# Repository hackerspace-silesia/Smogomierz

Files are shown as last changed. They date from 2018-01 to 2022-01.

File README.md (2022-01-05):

# Smogly 

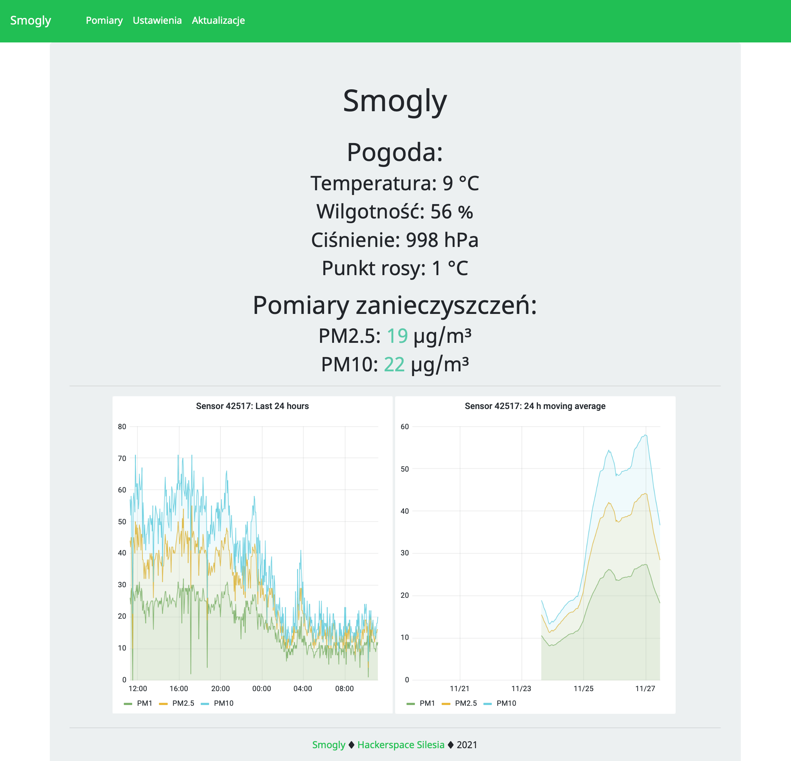
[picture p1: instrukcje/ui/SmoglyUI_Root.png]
Smogly2


Smogly to niekomercyjny projekt łatwego w budowie i taniego miernika zanieczyszczeń powietrza. Projekt jest w pełni otwarty i łatwy w modyfikowaniu. 

Smogly nie wysyła Twoich danych do żadnego serwisu, jeśli nie wyrazisz na to zgody. Dane pomiarowe z Twojego miernika należą do Ciebie i to od Ciebie zależy co z nimi zrobisz i komu je udostępnisz. Jeśli tylko Ty chcesz mieć dostęp do swoich danych, to masz do tego prawo. Jeśli jednak chcesz się nimi podzielić, to w karcie Konfiguracji panelu Smogomierza masz możliwość wyboru kilku serwisów, do których możesz wysłać dane. Wśród nich znajdziesz między innymi serwis [Sensor.Community](https://maps.sensor.community/#7/52.000/19.000), [aqi.eco](https://aqi.eco/), [ThingSpeak](https://thingspeak.com), [AirMonitor](http://mapa.airmonitor.pl)(ESP32), czy bazę danych [InfluxDB](https://www.influxdata.com/time-series-platform/influxdb/). Smogomierz posiada również [wtyczkę Homebridge](https://github.com/bfaliszek/homebridge-smogomierz).

Smogly po pierwszym uruchomieniu tworzy własną sieć WiFi o nazwie "Smogly-deviceName"(np. "Smogly-328017"). Po podłączeniu się z nią, będziesz miał możliwość skonfigurowania połączenia WiFi z własną siecią domową. Z listy dostępnych sieci wybierz swoją własną i podaj do niej hasło. Smogly zapisze dane w swojej pamięci wewnętrznej i ponownie się uruchomienie. Dalszą konfigurację wykonasz już przez przeglądarkę internetową wchodząc pod adres Smogly-deviceName.local lub IP_Smogly(do sprawdzenia na routerze). 

Stworzyliśmy również aplikację dla systemów Windows, macOS oraz Linux), która umożliwia w łatwy sposób wgranie oprogramowania oraz znajdowanie adresu IP Twojego miernika! Możesz ją pobrać ze strony [github.com/hackerspace-silesia/Smogomierz-Flashing-Tool](https://github.com/hackerspace-silesia/Smogomierz-Flashing-Tool/releases).

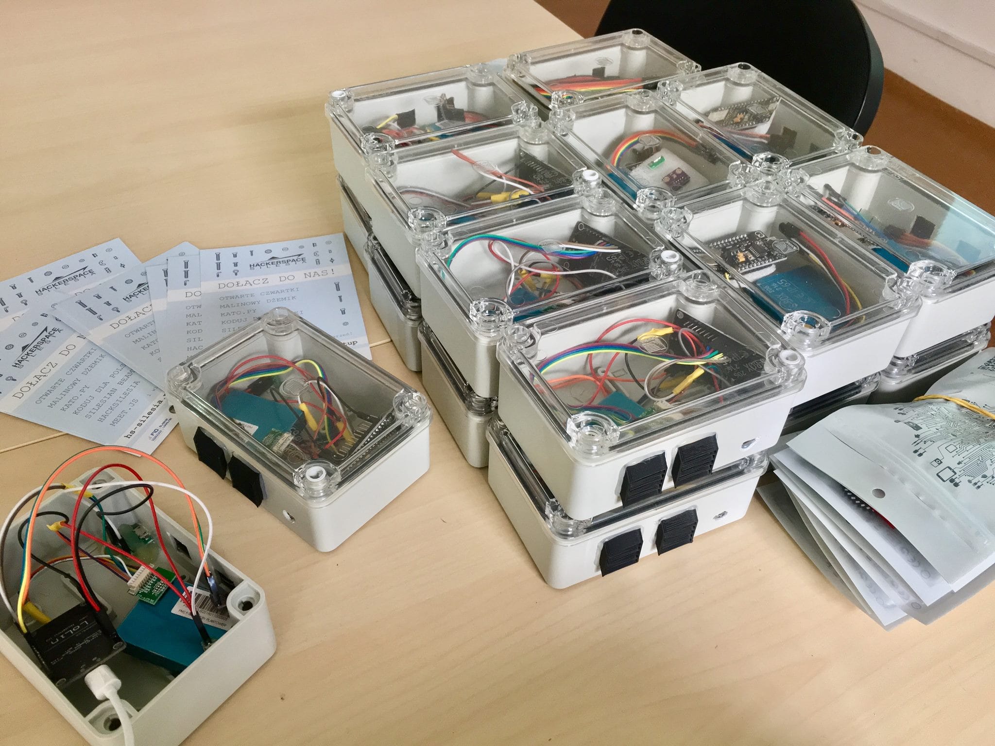
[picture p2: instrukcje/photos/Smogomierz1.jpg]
Smogly1


## Darowizny

Projekt Smogly jest rozwijany od 2017 roku. Wszystko w ramach projektu Smogly robione jest za darmo, w ramach wolontariatu. Jeśli chcesz wesprzeć rozwój projektu, to możesz przekazać darowiznę na Stowarzyszenie Hackerspace Silesia. Najprościej można to zrobić przez specjalny formularz znajdujący się na stronie: [hs-silesia.pl/smogomierz](https://hs-silesia.pl/smogomierz/).



## Instrukcje

1. [Instrukcja zlutowania wymaganych elementów](https://github.com/hackerspace-silesia/Smogomierz/blob/master/instrukcje/soldering.md)

2. [Instrukcja przygotowania obudowy oraz podłączenia elektroniki](https://github.com/hackerspace-silesia/Smogomierz/blob/master/instrukcje/hardware.md)

3. [Instrukcja instalacji/aktualizacji oprogramowania z pliku .bin](https://github.com/hackerspace-silesia/Smogomierz/blob/master/instrukcje/software-bin.md)

4. [Konfiguracja i ustawienia obsługi zewnętrznych serwisów(Sensor.Community, InfluxDB itd.)](https://github.com/hackerspace-silesia/Smogomierz/blob/master/instrukcje/software-additionals.md)

## Parts / Potrzebne części

Do zbudowania własnego Smogly wymagana jest lutownica(wraz z cyną) oraz pistolet do kleju na gorąco, wiertarka, nóż do tapet i śrubokręt do skręcenia obudowy oraz części z poniższej listy.

[Lista potrzebnych części](https://github.com/hackerspace-silesia/Smogomierz/blob/master/instrukcje/components.md)

Gotowe zestawy części potrzebnych do zbudowania własnego Smogly, dostępne są również w sklepie Botland: [Zestaw DIY do budowy miernika smogu](https://botland.com.pl/pl/czujniki-czystosci-powietrza/13434-zestaw-diy-do-budowy-miernika-smogu-czujnik-czystosci-powietrza-pm25-i-pm10.html)

## Smogly PCB

Jeśli ktoś nie lubi podpinać wszystkiego kabelkami, może skorzystać z gotowych projektów płytek PCB. Pozwalają one na połączenie wszystkich elementów. Dostępne są wersja dla [ESP8266](https://github.com/bfaliszek/Smogly-PCB) oraz [ESP32](https://github.com/bfaliszek/Smogly-PCB/tree/esp32). Projekt taki(.zip z plikami gerber [ESP8266](https://github.com/bfaliszek/Smogly-PCB/tree/esp8266/gerber/zip)/[ESP32](https://github.com/bfaliszek/Smogly-PCB/tree/esp32/gerber/zip)) wysyłamy do producenta PCB(np. [JLCPCB](https://jlcpcb.com)) i po kilkunastu dniach otrzymujemy gotowe PCB, do którego przylutowujemy piny lub poszczególne elemeny Smogly.

## Zaawansowane

[Instrukcja instalacji oprogramowania wymaganego do kompilacji oprogramowania z repozytorium](https://github.com/hackerspace-silesia/Smogomierz/blob/master/instrukcje/software.md)

## Roadmap

Lista z głównymi zmianami planowanymi w kolejnych wersjach oprogramowania znajduje się [TUTAJ](https://docs.google.com/spreadsheets/d/1rpeKPuAakPwytqsNge7glb-UtNLumsx8-7kQvhxXOng/edit?usp=sharing). Poza wymienionymi w linkowanym arkuszu funkcjami, przy każdej aktualizacji staram się uaktualnić wsyzstkie wykorzystywane biblioteki i eliminować znalezione błędy.

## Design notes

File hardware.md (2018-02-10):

# Smogomierz - podłączenie elektroniki

Poniższy opis krok po kroku, przeprowadzi Was przez procedurę podłączenia wszystkich czujników obsługiwanych przez nasz miernik smogu. Listę części, wraz z linkami do przykładowych sklepów, gdzie można je kupić znajdziecie pod adresem: https://github.com/hackerspace-silesia/Smogomierz/blob/Arduino/components.md

Całościowy schemat podłączenia:

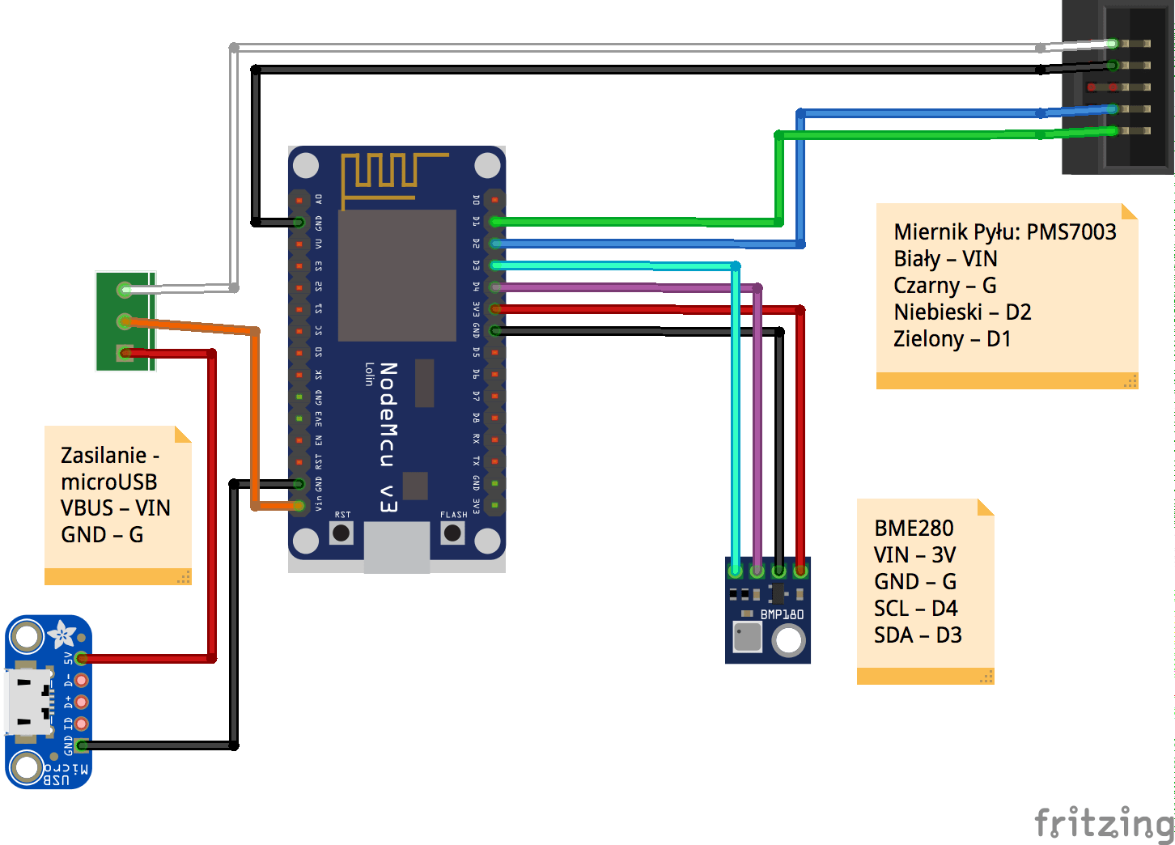
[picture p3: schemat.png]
Schemat


## ESP8266 - NodeMCU V3

Główny element miernika. To właśnie na tę płytkę wgrywamy oprogramowanie. Ma ona wbudowany moduł WiFi, który pozwala na tworzenie sieci bezprzewodowej i wysyłanie danych z pozostałych czujników.

OPIS ESP8266

## BME280 - miernik temperatury, wilgotności i ciśnienia powietrza

BME280 to niewielki moduł pozwalający na bardzo precyzyjne pomiary temperatury powietrza, ciśnienia oraz wilgotności powietrza. 

BME280 można podłączyć na dwa sposoby. W naszym przypadku skorzystamy z I2C. Oznacza to, że poza zasilaniem, będziemy musili jeszcze podłączyć dwa piny: SCL oraz SDA. 

BME280 zasilamy z pinu 3V na ESP8266. Podpinamy go do VIN na BME280. GND łączymy z dowolnym G na ESP8266. SCL podpinamy do pinu D4, SDA do D3 na ESP8266.

SCHEMAT PODŁĄCZENIA BME280

## PMS7003 - laserowy miernik pyłu

Plantower PMS7003 to laserowy miernik pyłu zawieszonego w powietrzu, który podane pomiary PM1, PM2.5 oraz PM10. Posiada wbudowany wiatraczek. Urządzenia zasilane jest 5V i wyniki podaje poprzez UART. W naszym projekcie korzystamy z dwóch pinów RX oraz TX. Pozostałe dostępne w mierniku PMS7003 nie są wykorzystywane.

PMS7003 zasilamy bezpośrednio z pinu 5V wyprowadzonego z portu microUSB w obudowie urządzenia. Piny GND podpinamy do dowolnego pinu G na płytce ESP8266. Pin TX(Pin 9 w PMS7003; zielony kabelek) podpinamy do pinu D1 na płytce ESP8266. Pin RX(Pin 7 w PMS7003; niebieski kabelek) podpinamy do pinu D2 na ESP8266.

SCHEMAT PODŁĄCZENIA PMS7003

## Zasilanie

Miernik smogu zasilany jest poprzez kable microUSB. Układ z wtyczką microUSB umieściliśmy w jednej z gumowych zatyczek w obudowie. Przykleiliśmy go na stałe klejem na gorąco. Z układu wychodzą dwa piny: 5V oraz GND. Służą do zasilania urządzenia.

Wszystkie elementy urządzenia zasilamy poprzez 5V. Źródłem jest pin 5V wyprowadzony z portu microUSB w obudowie urządzenia. 5V musimy doprowadzić do pinu VIN w ESP8266 i 5V w PMS7003(biały kabelek). W tym celu rozdzielamy zasilanie z jednego pinu, na dwa. BME2866 zasilamy z pinu 3V na płytce ESP8266.

Podobnie robimy z GND. Jednak w tym wypadku nie musimy ręcznie rozdzielać masy. Wystarczy ją podłączyć do pinu G na ESP8266. GND z miernika PMS7003(czarny kabelek) podpinamy do G na ESP8266. GND z BME280 również łączymy z G na płytce ESP8266.

SCHEMAT ZASILANIA

## Obudowa

Obudowę miernika smogu stanowi puszka natynkowa IP55. Daje ona dobre zabezpieczenie przeciwko niekorzystnym warunkom atmosferycznym. Puszka ma wymiary 86x86mm i posiada 6 gumowych zatyczek. W miejsce dwóch z nich wkleiliśmy klejem na gorąco elementy wydrukowane na drukarce 3D. Pozwalają one na lepszy przepływ powietrza w obudowie. Można dodać do obudowy niewielki wiatraczek zasilany przez 5V.

ZDJĘCIA OBUDOWY

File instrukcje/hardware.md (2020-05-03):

# Smogomierz - podłączenie elektroniki

Poniższy opis krok po kroku, przeprowadzi Cię przez procedurę podłączenia wszystkich czujników obsługiwanych przez nasz miernik smogu. Listę części, wraz z linkami do przykładowych sklepów, gdzie można je kupić znajdziesz pod adresem: https://github.com/hackerspace-silesia/Smogomierz/blob/master/instrukcje/components.md

Jeśli masz już wszystkie części, to pamiętaj, że kilka z nich wymaga przylutowania pinów. Opis wszystkiego co trzeba zlutować wraz ze zdjęciami znajdziesz w instrukcji ["Lutowanie"](https://github.com/hackerspace-silesia/Smogomierz/blob/master/instrukcje/soldering.md).

Całościowy schemat podłączenia:

Schemat

## ESP32

Moduł ESP, to główny element miernika. To właśnie na tę płytkę wgrywamy oprogramowanie. Ma ona wbudowany moduł WiFi, który pozwala na tworzenie sieci bezprzewodowej i wysyłanie danych z pozostałych czujników. Wszystkie piny GND na płytce są ze sobą połączone i można z nich korzystać zamiennie. Podobnie z pinami 3V. Jeśli zdecydujemy się na Smogomierz oparty o ESP32(zalecane, ma znacznie więcej pamięci niż ESP8266), to nie musimy już zamawiać ESP8266. 

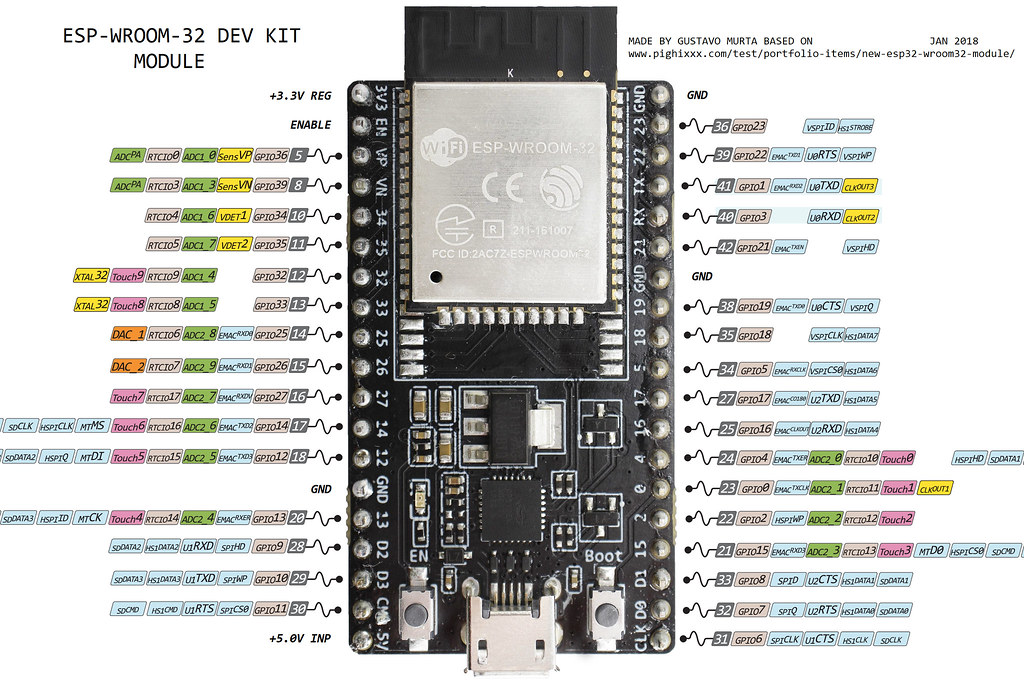
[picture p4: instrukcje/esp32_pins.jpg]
ESP32 Pinour


## ESP8266 - NodeMCU V3

Moduł ESP, to główny element miernika. To właśnie na tę płytkę wgrywamy oprogramowanie. Ma ona wbudowany moduł WiFi, który pozwala na tworzenie sieci bezprzewodowej i wysyłanie danych z pozostałych czujników. Wszystkie piny GND na płytce są ze sobą połączone i można z nich korzystać zamiennie. Podobnie z pinami 3V. Jeśli zdecydujemy się na Smogomierz oparty o ESP8266, to nie musimy już zamawiać ESP32(zalecany jest jednak wybór ESP32, ma znacznie więcej pamięci niż ESP8266). 

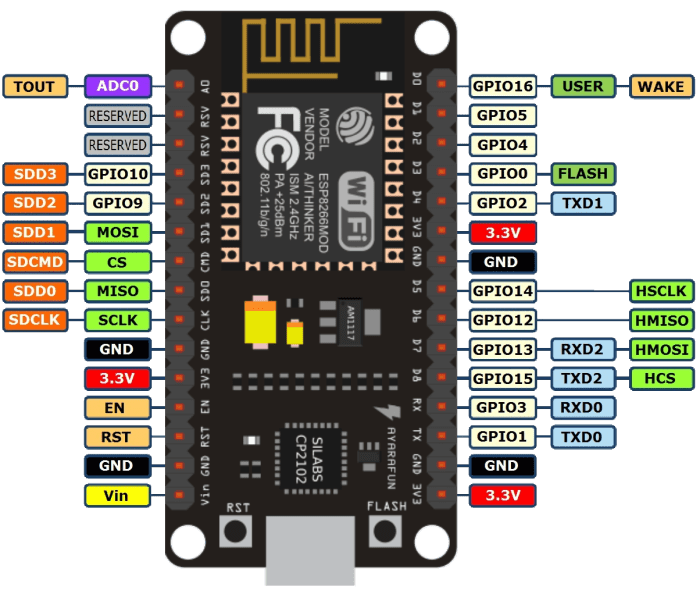
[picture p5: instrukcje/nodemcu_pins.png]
ESP8266 NodeMCU V3 Pinout


## BME280 - miernik temperatury, wilgotności i ciśnienia powietrza

BME280 to niewielki moduł pozwalający na bardzo precyzyjne pomiary temperatury powietrza, ciśnienia oraz wilgotności powietrza. 

BME280 można podłączyć na dwa sposoby. W naszym przypadku skorzystamy z I2C. Oznacza to, że poza zasilaniem, będziemy musieli jeszcze podłączyć dwa piny: SCL oraz SDA. 

BME280 występuje również w wersji **Adafruit**. Charakteryzuje się ona [niebieską płytką](https://www.adafruit.com/product/2652). W przypadku tej wersji BME280 musimy podłączyć SCK tam gdzie pin SCL(do D4) i SDI tam gdzie SDA(do D3) oraz SDO do dowolnego pinu GND na naszym ESP8266.

BME280 zasilamy z pinu 3V na ESP8266. Podpinamy go do VIN na BME280. GND łączymy z dowolnym G(GND) na ESP8266. SCL podpinamy do pinu D4, SDA do D3 na ESP8266.

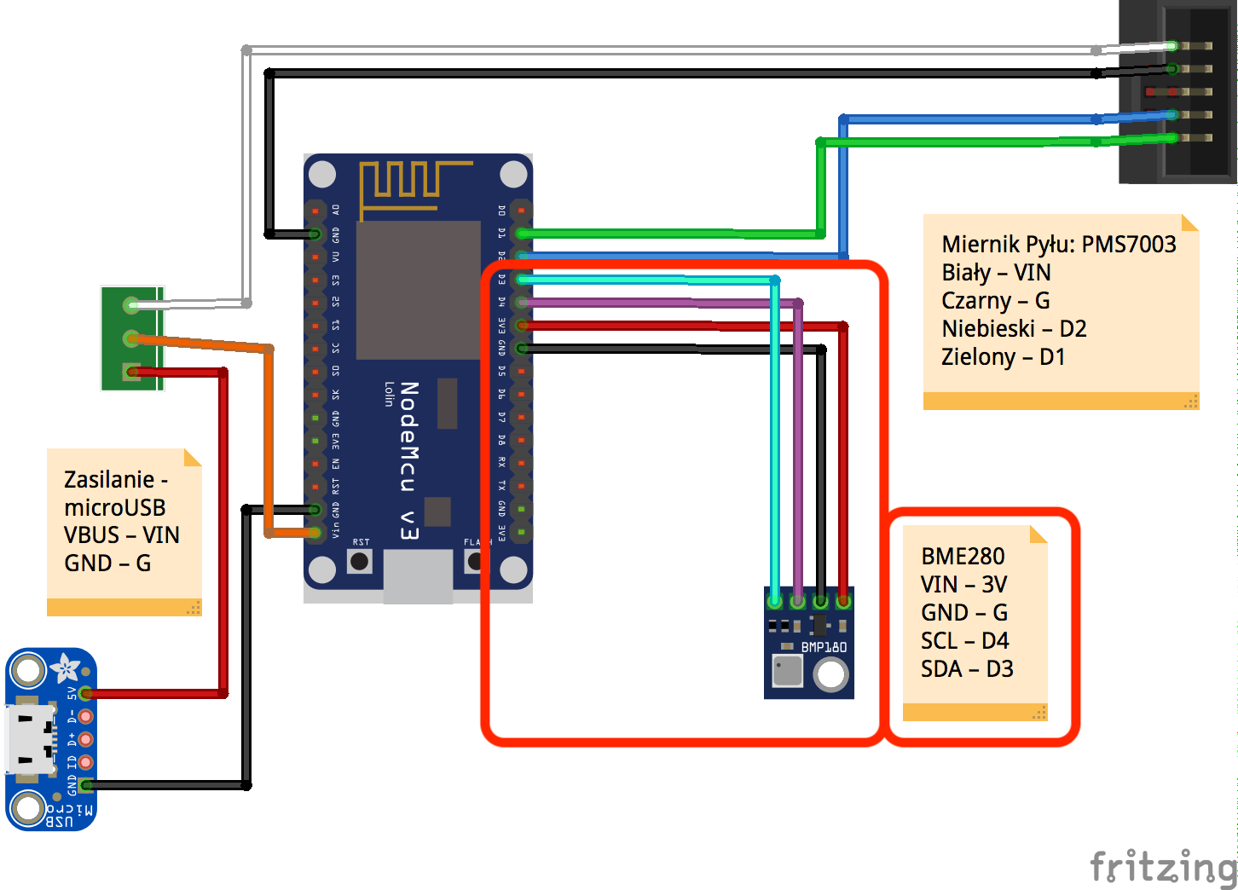
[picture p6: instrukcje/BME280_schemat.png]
BME280 Schemat

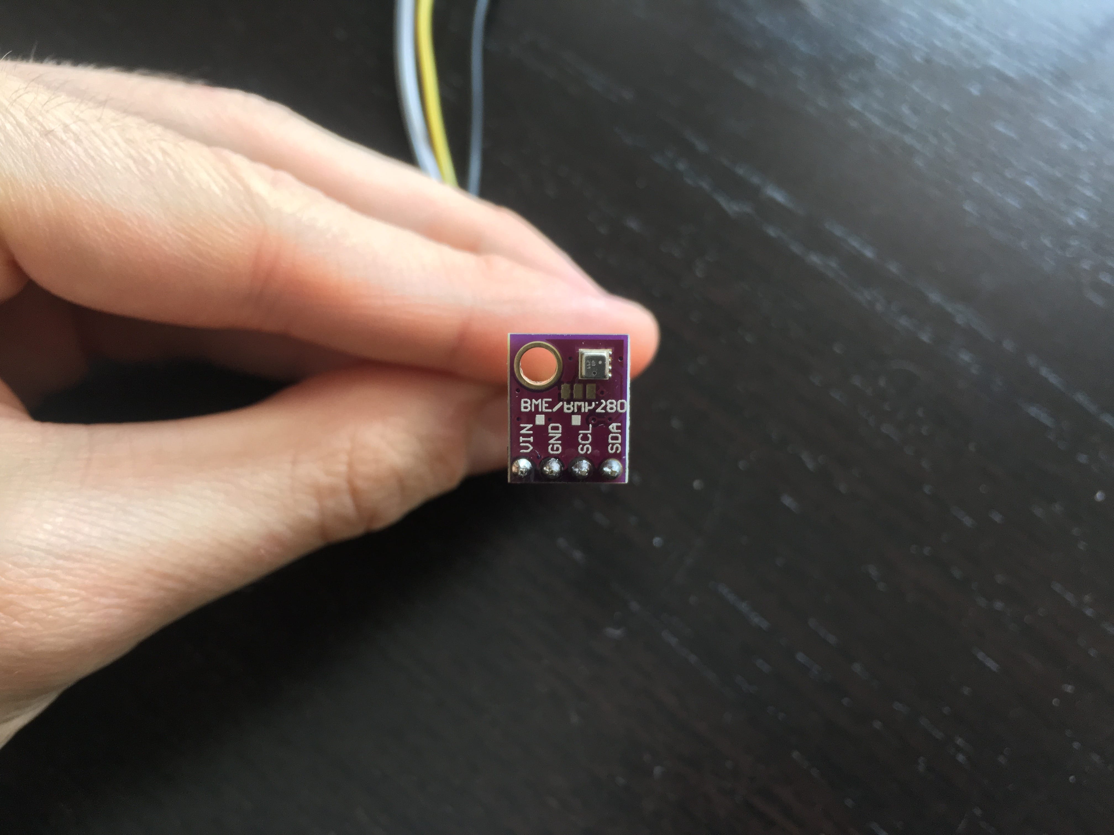
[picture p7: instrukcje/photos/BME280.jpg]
BME280


## SHT1x - miernik temperatury i wilgotności powietrza

SHT1x to niewielki moduł pozwalający na bardzo precyzyjne pomiary temperatury oraz wilgotności powietrza. 

SHT1x zasilamy z pinu 3V na ESP8266. Podpinamy go do VCC na SHT1x. GND łączymy z dowolnym G(GND) na ESP8266. CLOCK/SCL podpinamy do pinu D6, DATA/SDA do D5 na ESP8266. Pomiędzy DATA/SDA a VCC musimy umieścić jeszcze rezystor 10k (pull-up).

## HTU21D - miernik temperatury i wilgotności powietrza

Jeśli zamiast **BME280** chcesz użyć HTU21D. Podłącz go w następujący sposób: 
VIN z HTU21D do pinu 3V na ESP8266. GND łączymy z dowolnym G(GND) na ESP8266. SCL podpinamy do pinu D5, SDA do D6 na ESP8266.

## DHT22/AM2302 - miernik temperatury i wilgotności powietrza

Jeśli zamiast **BME280** chcesz użyć DHT22. Podłącz go w następujący sposób: 
VIN z DHT22/AM2302 do pinu 3V na ESP8266. GND łączymy z dowolnym G(GND) na ESP8266. Pin z danymi pomiarowymi podepnij do D7 na płytce ESP8266.

Kolejność pinów od lewej strony:
- VIN
- DATA
- nieużywany
- GND

## PMS7003 - laserowy miernik pyłu

Plantower PMS7003 to laserowy miernik pyłu zawieszonego w powietrzu, który podane pomiary PM1, PM2.5 oraz PM10. Posiada wbudowany wiatraczek. Urządzenia zasilane jest 5V i wyniki podaje poprzez UART. W naszym projekcie korzystamy z dwóch pinów RX oraz TX do pobierania wyników pomiarów oraz z pinu 5V i GND do zasilania PMS7003. Pozostałe dostępne w mierniku PMS7003 nie będą przez nas wykorzystywane.

PMS7003 zasilamy bezpośrednio z pinu 5V wyprowadzonego z portu microUSB w obudowie urządzenia. Piny GND podpinamy do dowolnego pinu G(GND) na płytce ESP8266. Pin TX(Pin 9 w PMS7003) podpinamy do pinu D1 na płytce ESP8266. Pin RX(Pin 7 w PMS7003) podpinamy do pinu D2 na ESP8266.

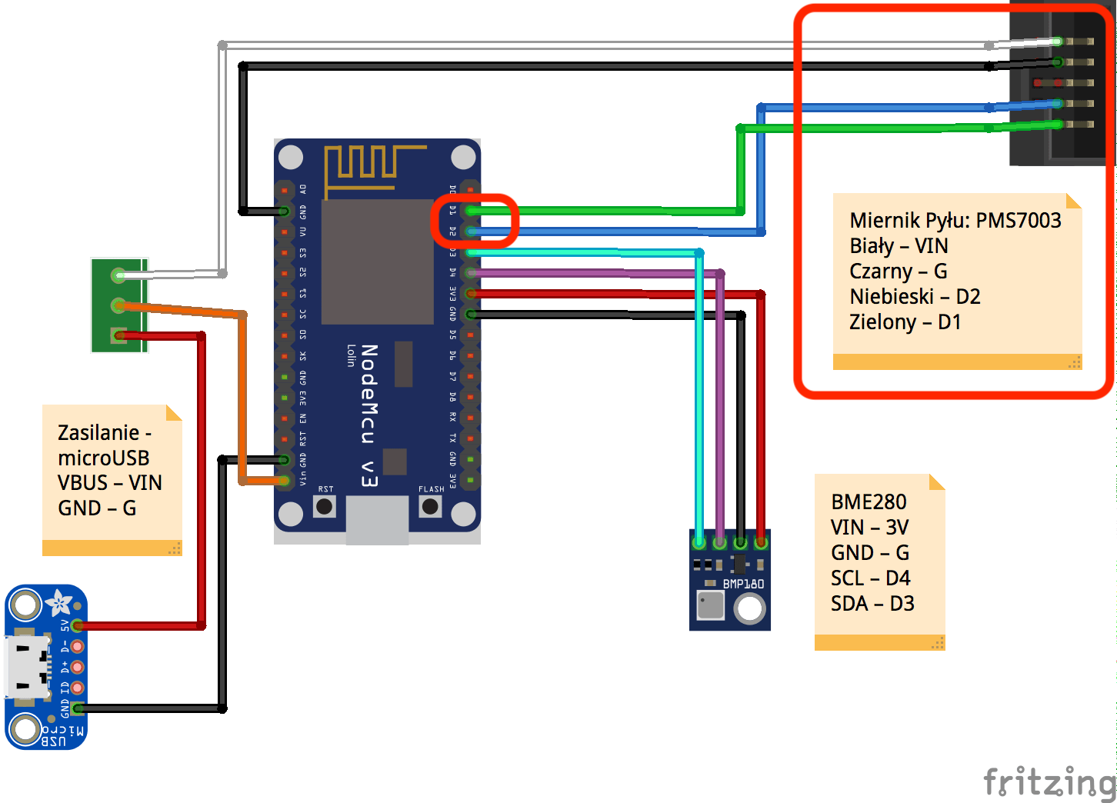
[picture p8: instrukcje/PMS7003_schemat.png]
PMS7003 Schemat


## Sensirion SPS30

Sensirion SPS30 to laserowy miernik pyłu zawieszonego w powietrzu, który podane pomiary PM1, PM2.5, PM4 oraz PM10. Posiada wbudowany wiatraczek. Urządzenia zasilane jest 5V i wyniki podaje poprzez UART. W naszym projekcie korzystamy z dwóch pinów RX oraz TX do pobierania wyników pomiarów oraz z pinu 5V i GND do zasilania SPS30. Pozostałe piny dostępne w mierniku SPS30 nie będą przez nas wykorzystywane. Sensirion SPS30 posiada system automatyczne czyszczenia kurzu osadzającego się wewnątrz miernika oraz żywotność aż 8 lat. Pomiary z Sensirion SPS30 są jednymi z najbardziej dokładnych. Jest on jednak jednym z droższych mierników. Kosztuje w Polsce około 140 zł.

SPS30 zasilamy bezpośrednio z pinu 5V wyprowadzonego z portu microUSB w obudowie urządzenia. Pin GND podpinamy do dowolnego pinu G(GND) na płytce ESP8266. Pin TX podpinamy do pinu D1 na płytce ESP8266. Pin RX podpinamy do pinu D2 na ESP8266. W przypadku użycia ESP8266 pozostały Pin(pin nr. 4) Sensiriona podpinamy do GND. W przypadku ESP32 zostawiamy go niepodłaczonego.

Pełną ([dokumentację](https://www.sensirion.com/en/environmental-sensors/particulate-matter-sensors-pm25/)) możemy znaleźć na stronie producenta Sensiriona SPS30. Warto również pamiętać, że SPS30 posiada dość nietypową wtyczkę: JST ZH 1.5. Wtyczka posiada 5 pinów i raster 1,5mm.

## HPMA115S0

Honeywell HPMA115S0 to laserowy miernik pyłu zawieszonego w powietrzu, który podane pomiary PM1, PM2.5 oraz PM10. Posiada wbudowany wiatraczek. Urządzenia zasilane jest 5V i wyniki podaje poprzez UART. W naszym projekcie korzystamy z dwóch pinów RX oraz TX do pobierania wyników pomiarów oraz z pinu 5V i GND do zasilania HPMA115S0. Pozostałe dostępne w mierniku HPMA115S0 nie będą przez nas wykorzystywane.

## SDS011

SDS011 to laserowy miernik pyłu zawieszonego w powietrzu, który podane pomiary PM2.5 oraz PM10. Posiada wbudowany wiatraczek. Urządzenia zasilane jest 5V i wyniki podaje poprzez UART. W naszym projekcie korzystamy z dwóch pinów RX oraz TX do pobierania wyników pomiarów oraz z pinu 5V i GND do zasilania SDS011. Pozostałe dostępne w mierniku SDS011 nie będą przez nas wykorzystywane.

Pin TXD podłącz do D1 na ESP, natomiast pin RXD do D2.
Zwróć uwagę na sposób montażu ([dokumentacja](http://www.inovafitness.com/en/a/chanpinzhongxin/95.html)) - w zmontowanym urządzeniu wlot powietrza miernika powinien być od góry, lub z lewej strony.

## Obudowa

Na obudowę Smogomierza wybraliśmy puszkę IP67 o wymiarach 118 x 78 x 55 mm. Oferuje ona dobre zabezpieczenie przeciwko niekorzystnym warunkom atmosferycznym. W obudowie Smogomierza istotne są dwie rzeczy. Ochrona przed deszczem oraz swobodny przepływ powietrza. Jeśli chcesz, możesz zastosować jakieś inne rozwiązanie, które spełni te dwa cele.

W przypadku wybranej przez nas obudowy. Musimy wykonać w niej 3 otwory. Dwa większe, które umożliwią przepływ powietrza, oraz jeden mniejszy w celu podłączenia zasilania. Zalecamy wykonanie otworów wentylacyjnych na dłuższym boku obudowy. Otwór na zasilanie możemy umieścić z dowolnej strony. Otwory wentylacyjne najwygodniej wykonać przy użyciu wiertarki i wiertła 10 lub większego. Wykonujemy dwa odwierty obok siebie i następnie wycinany je nożem do tapet w kształt kwadratu. Jeśli chodzi o zasilanie, to wystarczy jeden odwiert wiertłem 10. 

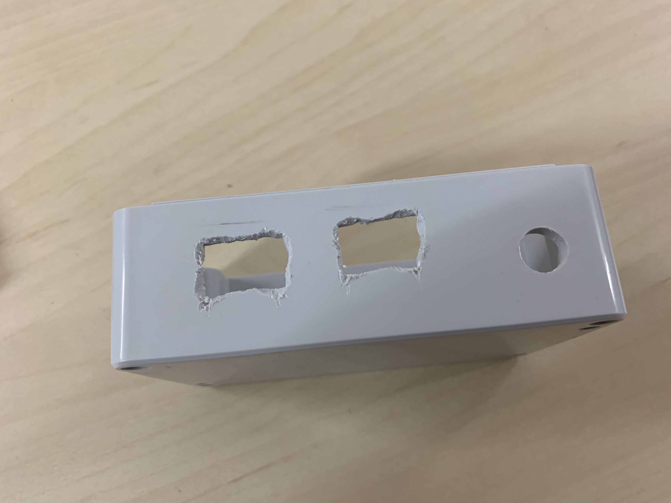
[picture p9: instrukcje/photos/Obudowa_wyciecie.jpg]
Obudowa_wyciecie


Na otwory wentylacyjne wklejamy klejem na gorąco [kratki](https://github.com/hackerspace-silesia/Smogomierz/blob/master/80x80x40mm.stl) wydrukowane na drukarce 3D. Pozwalają one na lepszy przepływ powietrza w obudowie. Natomiast wewnątrz obudowy w miejscu otworu na zasilanie wklejamy wtyczkę microUSB(z wlutowanymi wcześniej pinami).

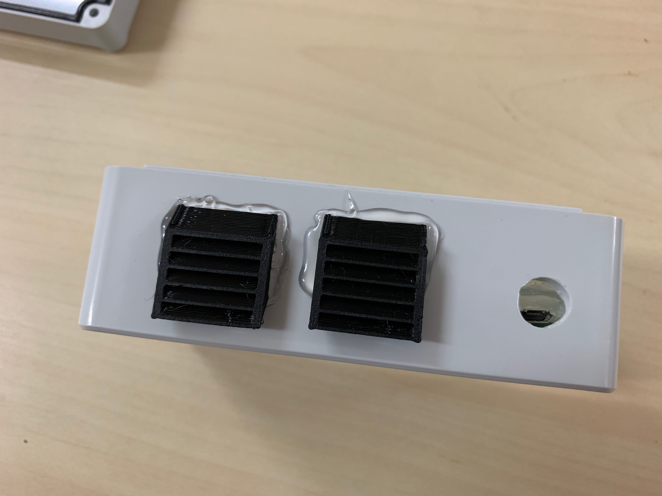
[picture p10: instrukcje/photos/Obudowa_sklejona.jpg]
Obudowa_sklejona

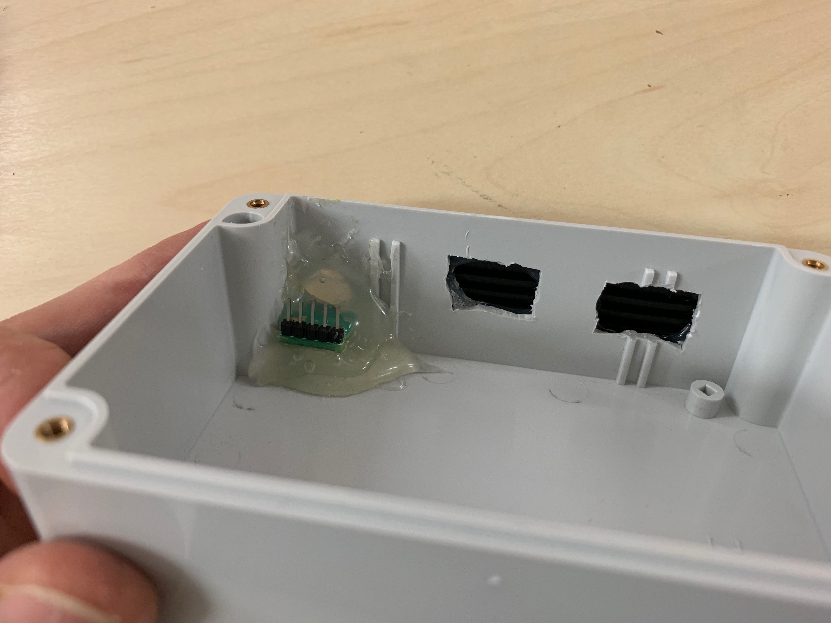
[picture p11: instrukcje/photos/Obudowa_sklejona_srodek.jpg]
Obudowa_sklejona_srodek


## Zasilanie

Miernik smogu zasilany jest poprzez kable microUSB. Układ z wtyczką microUSB wkleiliśmy klejem na gorąco w obudowę. Z układu wychodzą dwa potrzebne nam piny: 5V oraz GND. Służą do zasilania całego Smogomierza.

ESP8266 NodeMCu oraz miernik pyłu PM2.5 i PM10 zasilamy poprzez 5V. Źródłem jest pin 5V wyprowadzony z portu microUSB w obudowie urządzenia. 5V musimy doprowadzić do pinu VIN w ESP8266 i 5V w mierniku pyłu(VCC). W tym celu rozdzielamy zasilanie z jednego pinu, na dwa. Mirnik temperatury i wilgotności zasilamy z pinu 3V na płytce ESP8266. Na koniec nasz rozdzielacz zasilania 5V najlepiej zabezpieczyć kawałkiem taśmy izolacyjnej.

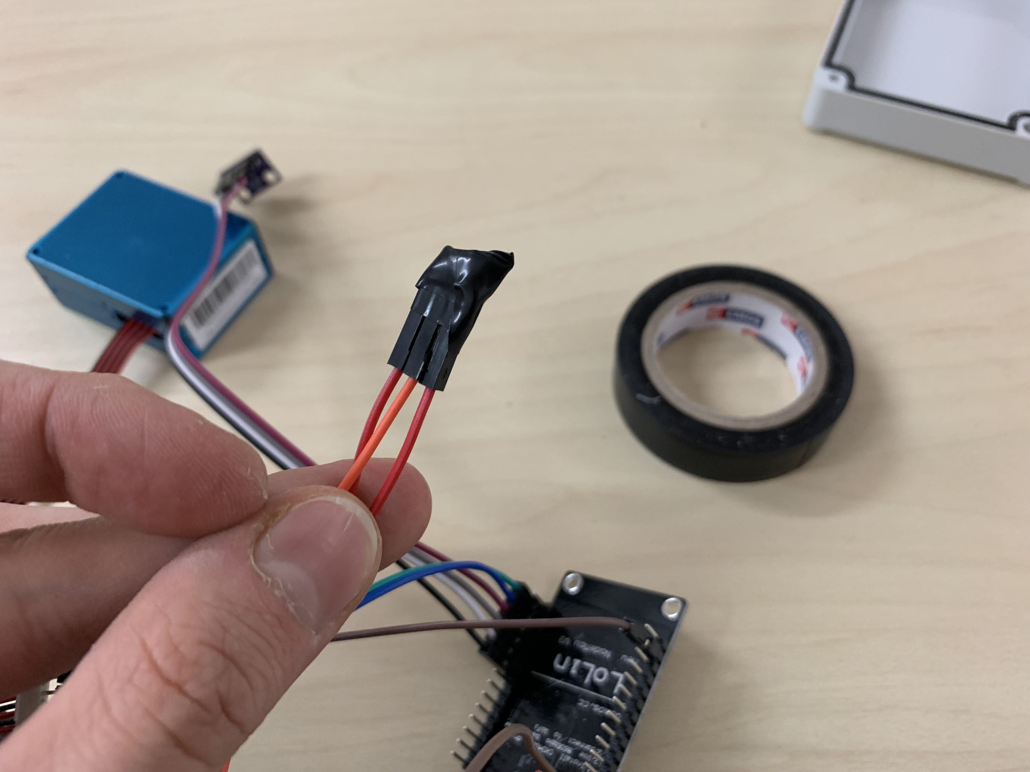
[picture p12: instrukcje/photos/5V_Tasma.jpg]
5V_Tasma


Podobnie robimy z GND. Jednak w tym wypadku nie musimy ręcznie rozdzielać masy. Wystarczy ją podłączyć do pinu G na ESP8266. GND z miernika pyłu podpinamy do G na ESP8266. GND z miernika temperatury i wilgotności również łączymy z G na płytce ESP8266. Wszystkie masy(G/GND) są ze sobą połączone. Tylko od ciebie zależy, do którego pinu G na ESP8266 podłączysz pin G z miernika pyłu czy miernika temperatury.

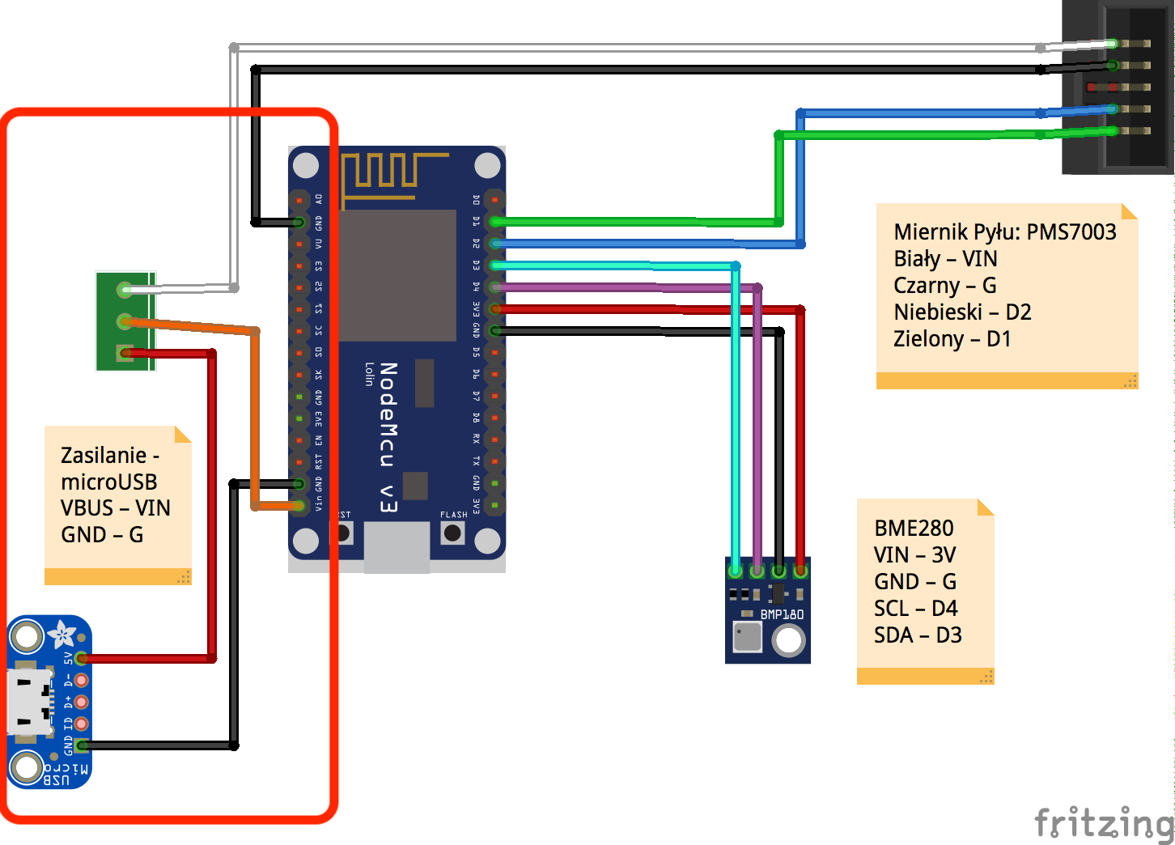
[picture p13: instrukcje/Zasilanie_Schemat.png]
Zasilanie Schemat


## Połączenie całości

Zgodnie ze schematem na początku instrukcji, łączymy wszystkie elementy ze sobą. Z **BME280** pin VIN podpinamy do 3V na ESP8266; GND do G; SCL do D4; SDA do D3. W przypadku **PMS7003** kable 5V z płytką z 3 pinami(pozostałe podpinamy do VIN na ESP8266 oraz VBUS w obudowie miernika); GND do G na ESP8266; TX do D1; RX do D2. Na koniec pin G z obudowy miernika wpinamy do G na ESP8266.

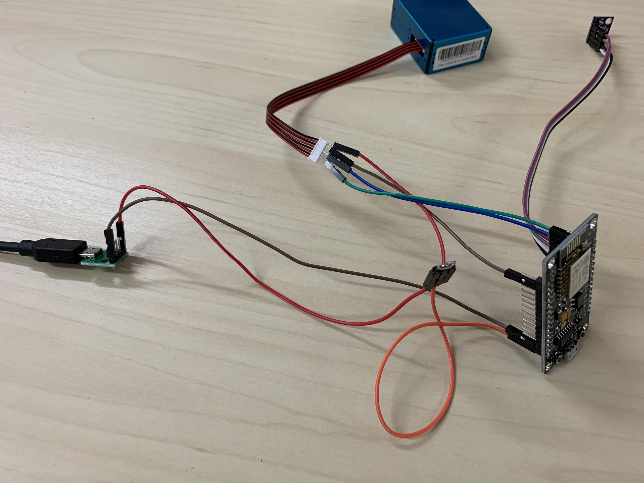
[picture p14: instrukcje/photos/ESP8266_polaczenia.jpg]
ESP8266_polaczenia


## Umiejscowienie podzespołów w obudowie

Jeśli postanowiliśmy użyć jako miernika pyłu modelu SDS011 to obudowa może wydawać się dość mała, ale wszystkie elementy zmieszczą się w niej bez problemu. Jeśli korzystamy z PMS7003 lub HPMA115S0 mamy nadmiar miejsca. Musimy pamiętać, aby wloty z miernika pyłu umiejscowić jak najbliżej otworów wentylacyjnych w obudowie. Pozwoli to na lepszy przepływ powietrza i dokładniejsze pomiary. Polecam ustawienie mierników w obudowie w taki sposób, aby wiatraczkiem z miernika pyłu znajdował się obok otworu wentylacyjnego. 

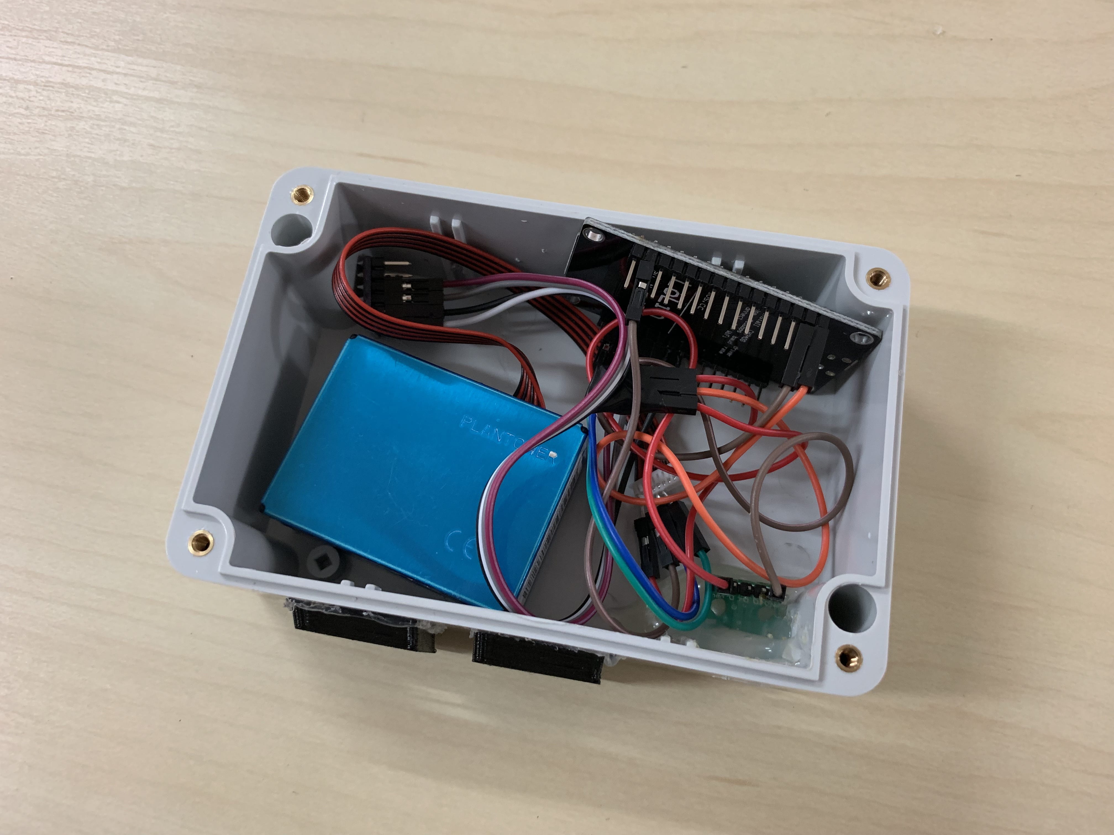
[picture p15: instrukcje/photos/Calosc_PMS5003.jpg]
Calosc_PMS5003

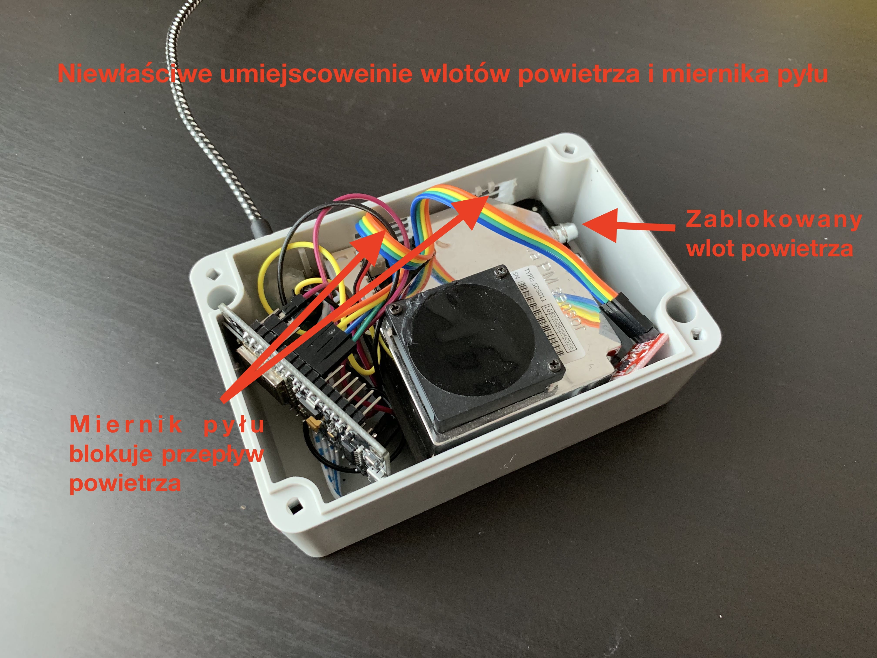
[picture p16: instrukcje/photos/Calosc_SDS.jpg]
Calosc_SDS


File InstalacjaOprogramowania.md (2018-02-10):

# Smogomierz - instalacja orpgoramowania

Poniższy opis ktok po kroku, przeprowadzi Was przez procedurę intalacji oprogramowania wymaganego do wgrania nowego systemu na mierniki smogu. Całe oprogramowanie jest w pełni darmowe, a jego pobranie nie wymaga żadnej rejestracji i podawania swoich danych.

## Arduino - instalacja

Na początku musimy ponrać program ArduinoIDE. Pozwala on na programowanie płytek z rodziny Arduino. W późniejszym kroku, dodamy do niego obsługę płytki ESP8266. To właśnie na nich oparte są nasze mierniki smogu.

1. Pobieramy oprogramowanie ze strony https://www.arduino.cc/en/Main/Software. W tym celu musimy wybrać jaki system operacyjny mamy zainstalowany na komputerze, a następnie kliknąć na napis "Download the Arduino IDE".
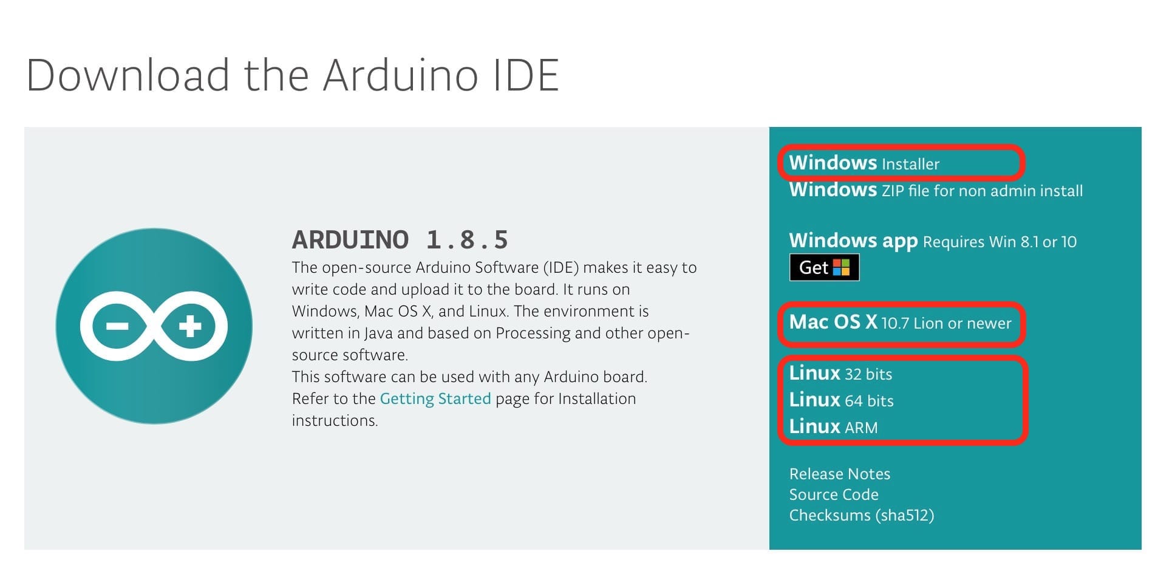
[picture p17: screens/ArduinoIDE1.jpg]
ArduinoIDE1


2. Klikamy napis "JUST DOWNLOAD". W tym momencie rozpocznie się pobieranie instalatora ArduinoIDE.
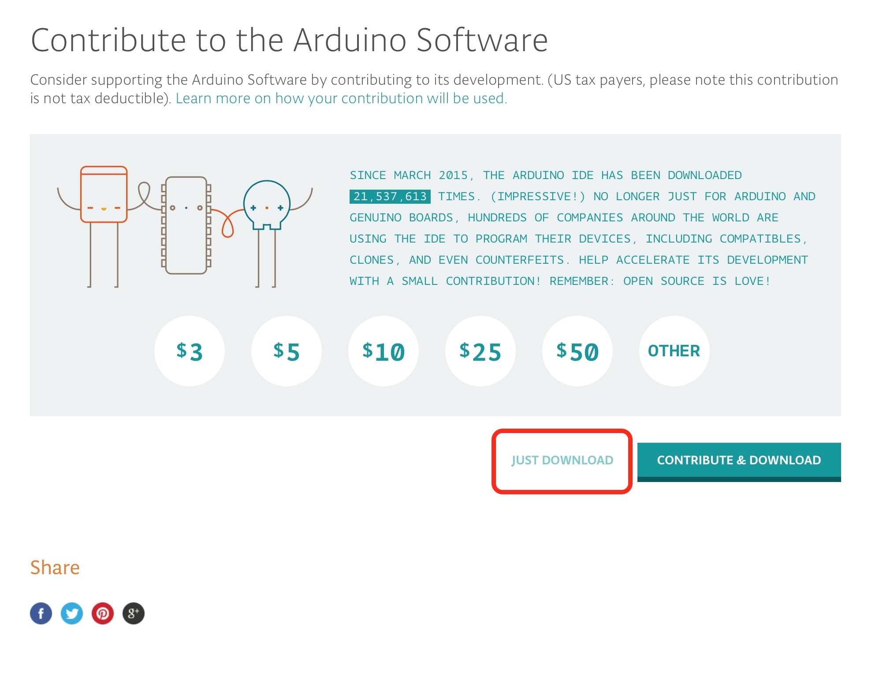
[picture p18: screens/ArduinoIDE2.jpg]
ArduinoIDE2


3. Instalujemy pbrany porogram. W przypadku Windowsa klikamy na niego 2 razy i instalujemy. W systemie macOS przenosimy do foldery Aplikacje. Na Linuksie uruchamiamy skrypt install.sh.

## Arduino - konfiguracja

Po zainstalowaniu ArduinoIDE, musimy dodać w nim obsługę płytek ESP8266.

1. Uruchamiamy aplikację ArduinoIDE i wybieramy "Plik > Ustawienia" lub "Arduino > Preferences…" w przypadku systemu macOS.
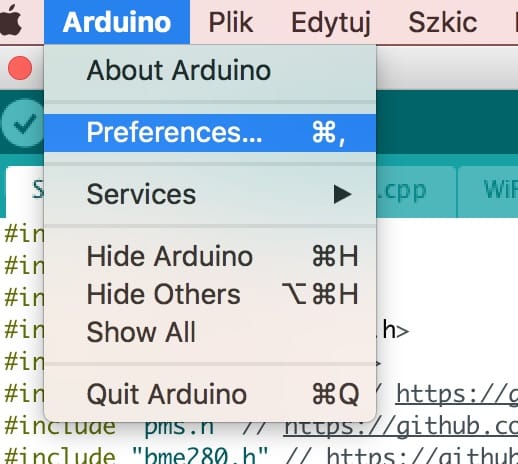
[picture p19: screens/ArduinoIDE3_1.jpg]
ArduinoIDE3_1


2. W okienku „Dodatkowe adresy URL do menedżera płytek:” wpisujemy adres: http://arduino.esp8266.com/stable/package_esp8266com_index.json
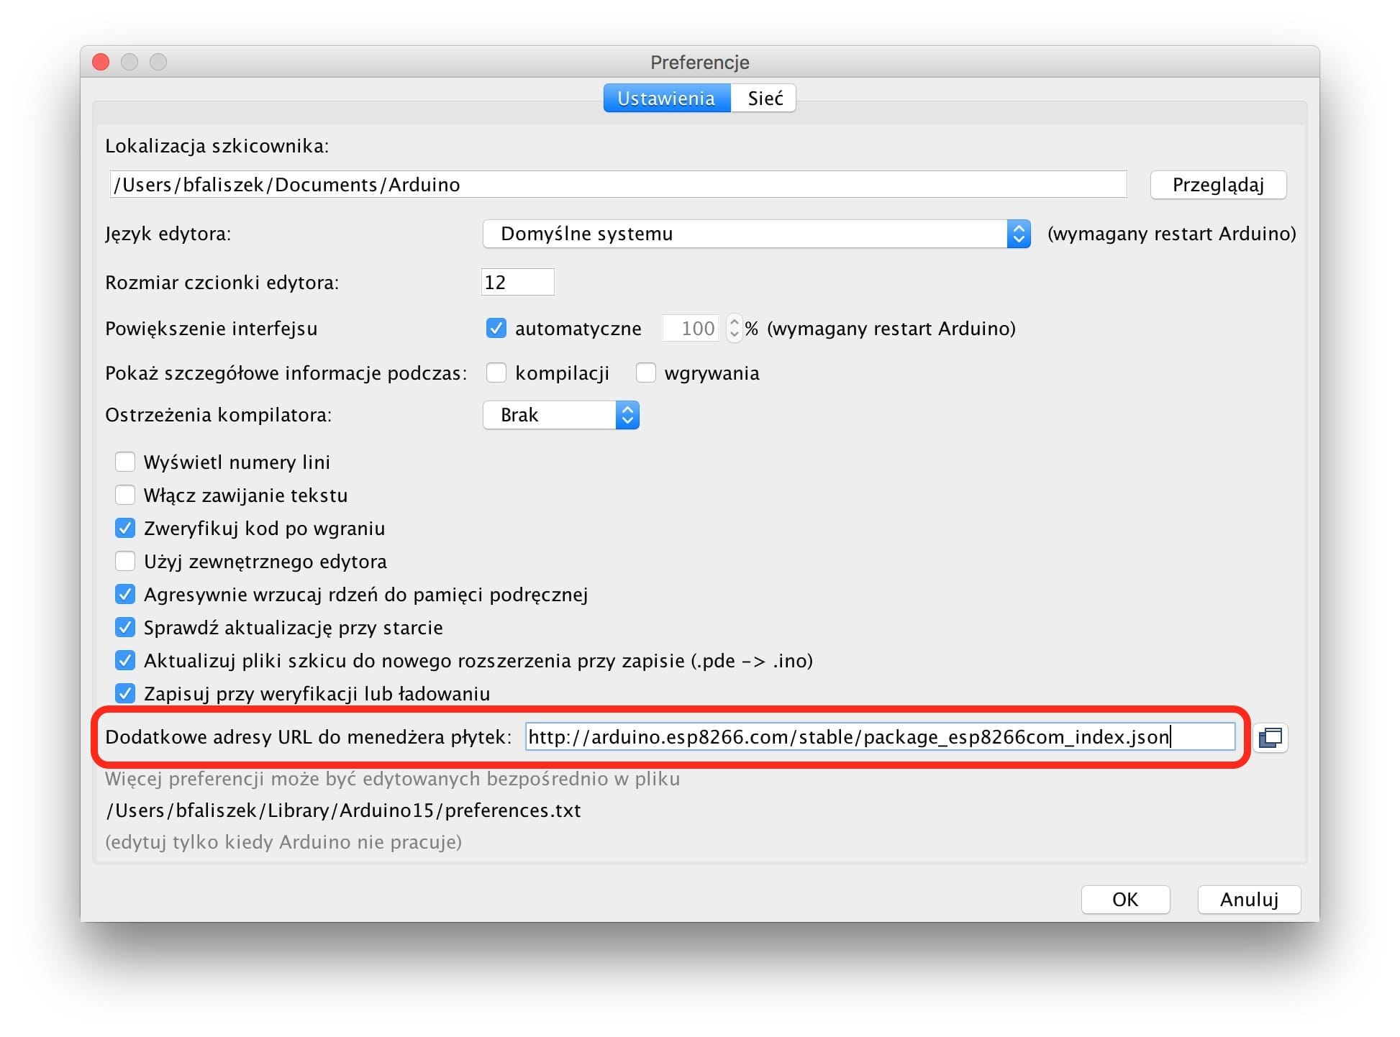
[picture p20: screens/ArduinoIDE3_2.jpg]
ArduinoIDE3_2


3. Po dodaniu adresu, skąd program może pobrać informacje o nowych płytkach, musimy je jeszcze pobrać. W tym celu klikamy "Narzędzia > Płytka > Menedżer płytek…".
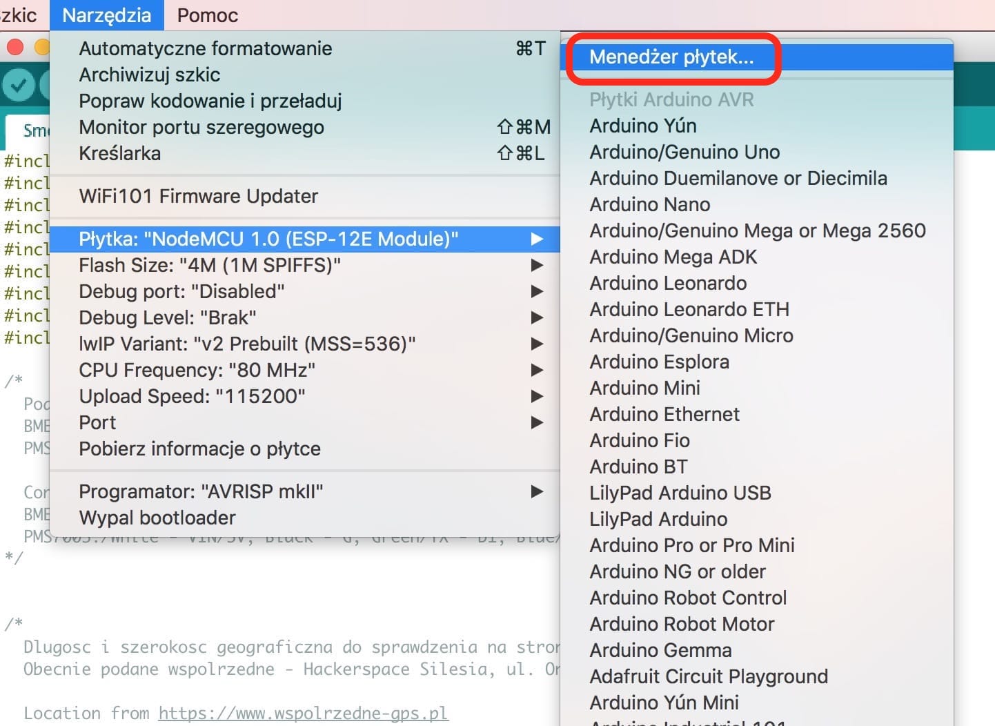
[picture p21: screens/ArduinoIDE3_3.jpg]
ArduinoIDE3_3


4. W wyszukiwarce wpisujemy frazę: "esp8266" i instalujemy nowe płytki.
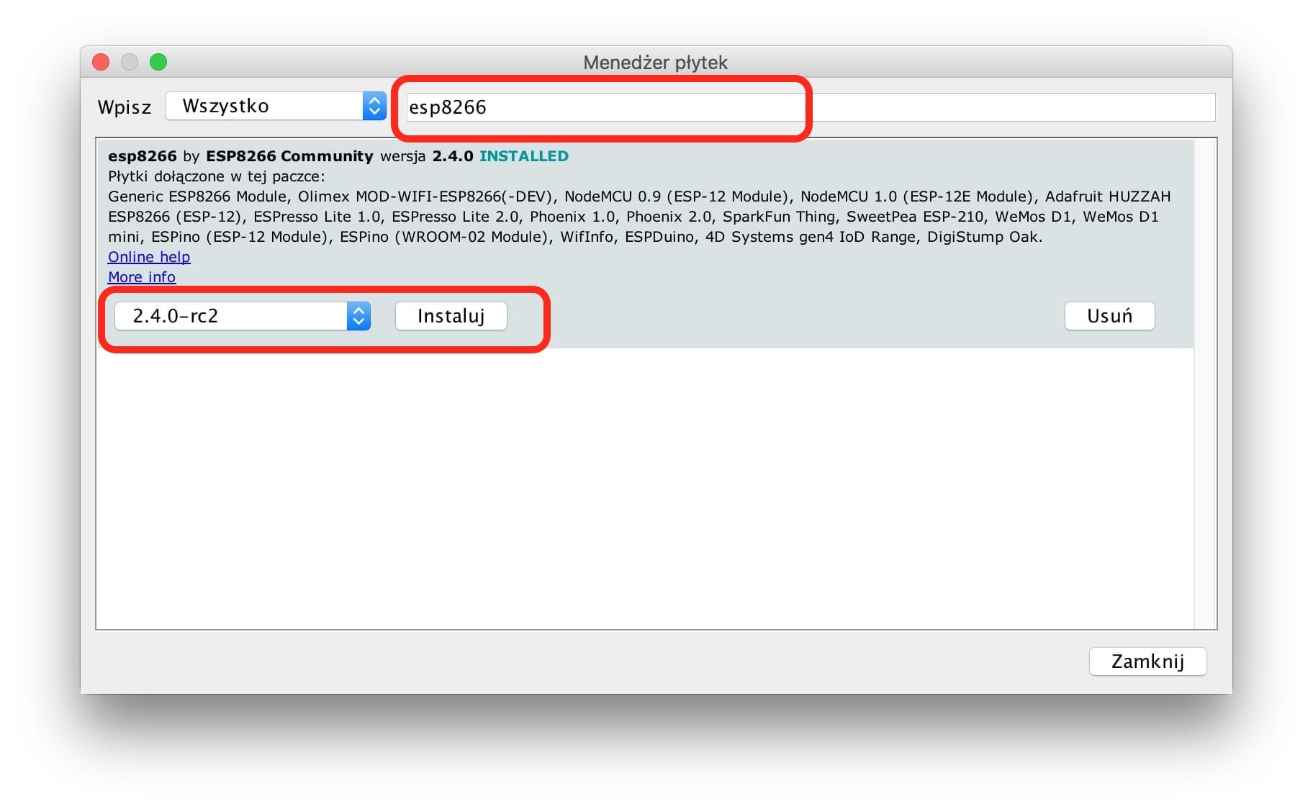
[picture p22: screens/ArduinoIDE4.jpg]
ArduinoIDE4


5. Teraz pozostaje nam tylko ustawić w ArduinoIDE, że nasz kod ma być dostosowany do płytek ESP8266, a nie standardowego Arduino. W tym celu musimy wybrać "Narzędzia > Płytka > NodeMCU 1.0 (ESP-12E Module)". 
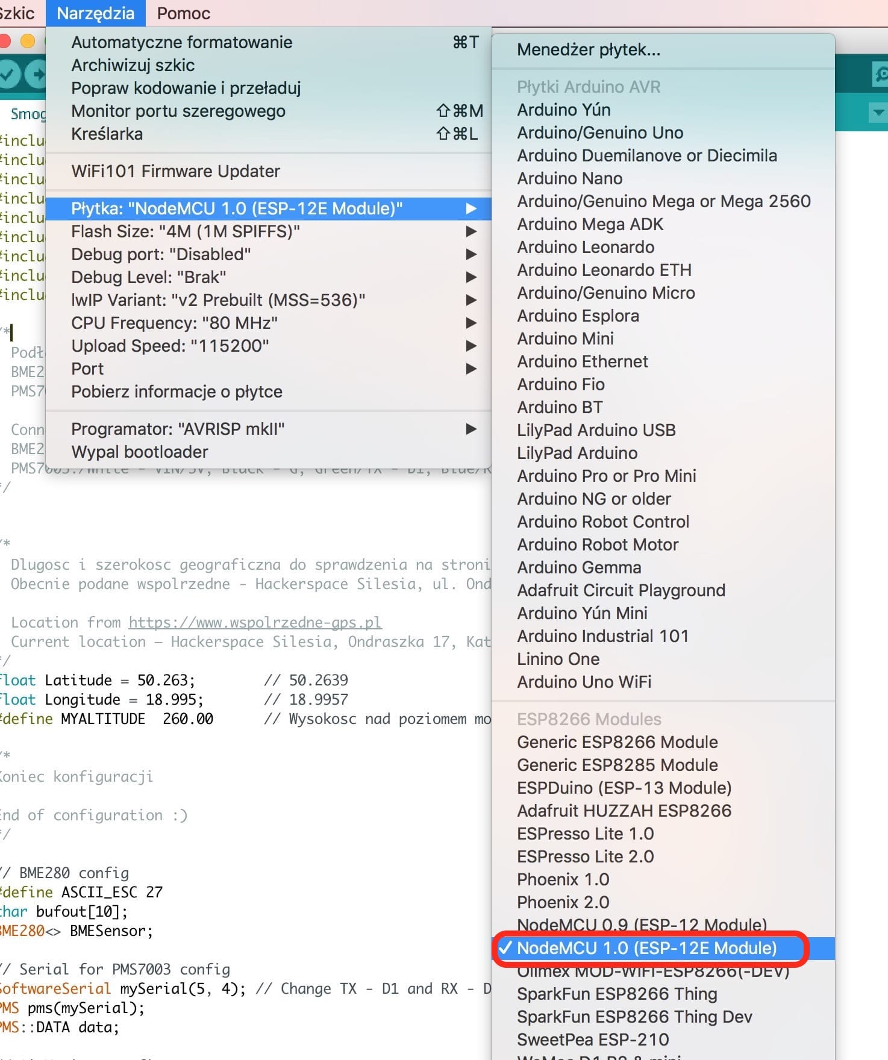
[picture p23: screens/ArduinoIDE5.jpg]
ArduinoIDE5


6. Na koniec pozostaje nam wybranie portu szeregowego, go którego podłączona jest nasza płytka. W tym celu podpinamy ESP8266 do portu USB w komputerze i wybieramy "Narzędzia > Port > COM3". W przypadku systemu innego niż Windows, zamiast "COM3" będziemy mieć inną opcję do wyboru np. "/dev/cu.wchusbserial1410". 
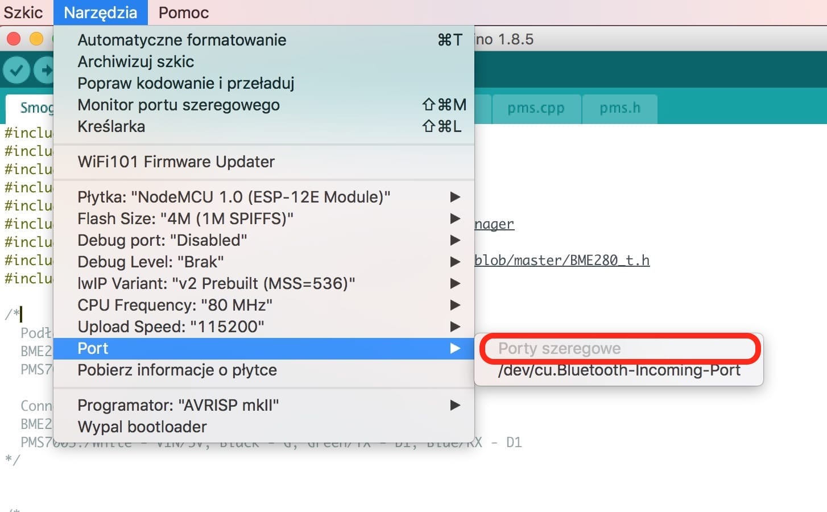
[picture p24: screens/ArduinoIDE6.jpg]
ArduinoIDE6


7. Teraz wszystko jest już gotowe do obsługi naszych mierników smogu. Możemy przejść do pobrania oprogramowania i sprawdzenia czy działa.

## Smogomierz - pobranie i wgranie oprogramowania na ESP8266

1. Wchodzimy na stronę projektu Smogomierz w serwisie github i pobieramy pliki: https://github.com/hackerspace-silesia/Smogomierz/tree/Arduino
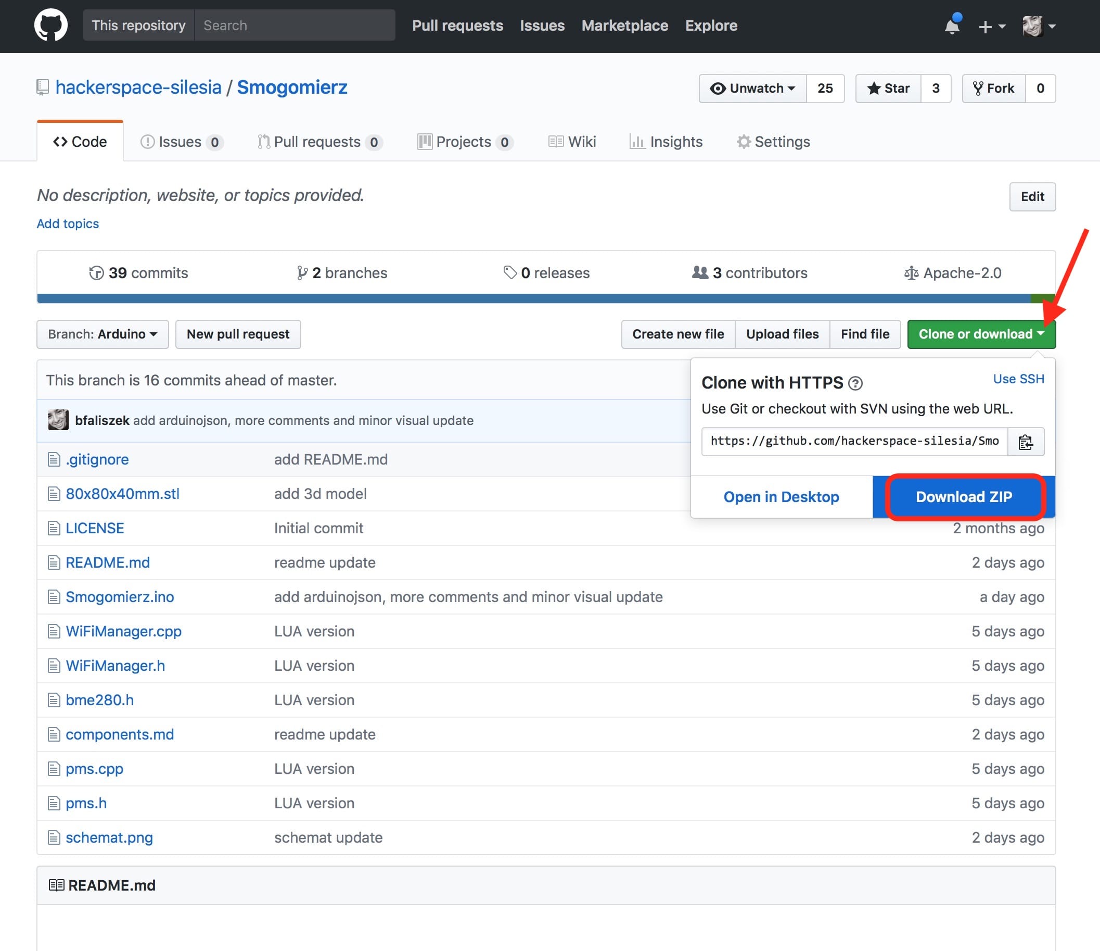
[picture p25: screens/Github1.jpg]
Github1


2. Rozpakowujemy pobraną paczkę i otwieramy plik Smogomierz.ino.

3. Otworzy się nam okienko programu ArduinoIDE z kodem naszej aplikacji Smogomierza.  
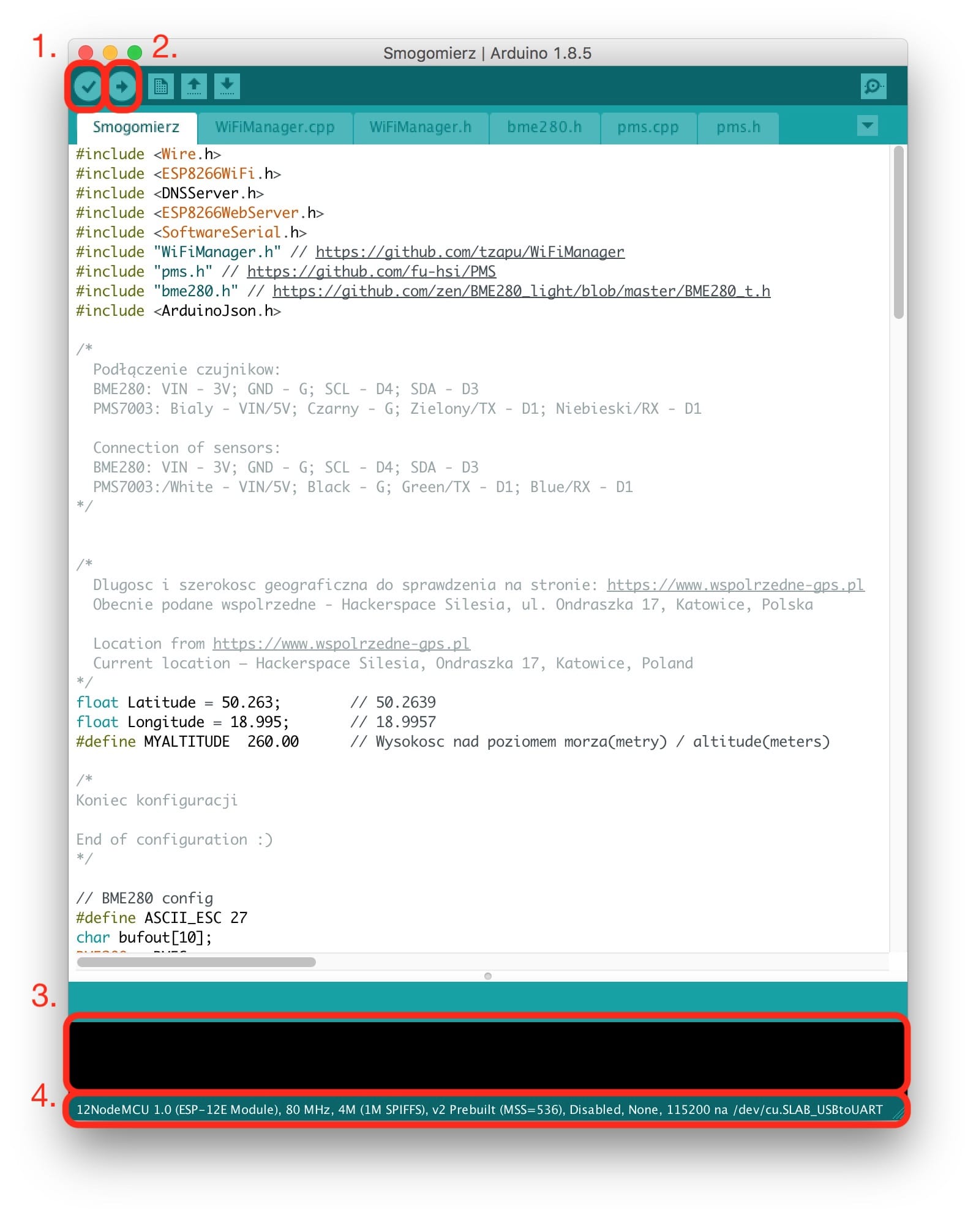
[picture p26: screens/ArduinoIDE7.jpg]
ArduinoIDE7


1 – Sprawdzenie poprawności oprogramowania

2 – Wgranie oprogramowania na płytkę

3 – Postęp weryfikacji/wgrywania oprogramowania i ewentualne błędy

4 – Płytka oraz port, które mamy ustawione

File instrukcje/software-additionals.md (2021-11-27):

# Smogomierz - dodatki

Smogomierz pozwala na obsługę różnych serwisów internetowych, do których możesz wysłać swoje dane. Poniżej znajdziesz opis jak korzystać z kilku z nich.

## Nazwa urządzenia oraz Bonjour/Zeroconf

Smogomierz domyślnie tworzy sieć WiFi o nazwie np. "Smogomierz-328017". Ostatnie 6 znaków to Chip ID płytki ESP. Jest ono unikatowe dla każdego ESP32/ESP8266. Nazwę naszego urządzenia możemy zmienić w zakładce Konfiguracja w panelu Smogomierza. Musimy w tym celu wyłączyć automatyczne generowanie nazwy i wpisać swoją własną. 

Smogomierz domyślnie obsługuje protokół Bonjour/Zeroconf. Pozwala on na połączenie się z miernikiem będącym w naszej sieci, bez znajomości jego adresu IP. Po połączeniu Smogomierza z naszą siecią WiFi, możemy otworzyć przeglądarkę internetową i wpisać adres np. "Smogomierz-328017.local"(jeśli ustawimy sobie własną nazwę urządzenia będzie to NaszaNazwa.local). Zeroconf do działania potrzebuje doinstalowania na komputerze z Windowsem aplikacji [Bonjour](https://support.apple.com/kb/DL999?locale=pl_PL), a pod Linuksem – Avahi. System macOS(oraz iOS) nie wymaga instalacji dodatkowego oprogramowania.

## Sensor.Community

[Sensor.Community](https://maps.sensor.community/#7/52.000/19.000) to największa sieć społecznych czujników jakości powietrza na świecie. Powstała na bazie projektu Luftdaten. Serwis ten umożliwia tworzenie wykresów z pomiarami zanieczyszczeń powietrza i wyświetlanie ich bezpośrednio w panelu Smogly. Dodatkowo serwis udostępnia dane do dziesiątek aplikacji i serwisów zewnętrznych, dzięki temu nasze dane pomiarowe będą mogły znaleźć się w wielu aplikacjach mobilnych czy na mapach zanieczyszczeń powietrza.

Jeśli chcesz wysyłać swoje dane do serwisu Sensor.Community i wyświetlać swoje wykresy, to na początku musisz sprawdzić współrzędne geograficzne miejsca, gdzie znajduje się Twój miernik. Może to zrobić na stronie https://www.wspolrzedne-gps.pl. Wystarczy tam wpisać adres, a uzyskamy szerokość oraz długość geograficzną. 

Sensor.Community wymaga rejestracji na stronie [devices.sensor.community](https://devices.sensor.community), gdzie podajemy adres naszego urządzenia(współrzędne geograficzne, warto zwrócić uwagę, aby były takie same jak w panelu Smogly). Dodatkowo podajemy ID sensora(ChipID z panelu Smogly), oraz wybieramy jakie mierniki ma nasze urządzenie. Jeśli Współrzędne oraz miernik naszego urządzenia są identyczne na stronie devices.sensor.community jak w panelu ustawień Smogly, możemy właczyć wykresy, które powstają na podstawie przesłanych do serwisu danych.

## aqi.eco

[aqi.eco](https://aqi.eco) to serwis, który pozwala na gromadzenie danych pomiarowych z różnych czujników oraz tworzenie wykresów do zgromadzonych danych. Wykresy oraz pomiary mogą być prywatne lub publicznie dostępne. Serwis wymaga rejestracji. Ma darmowe konta ograniczone. aqi.eco pozwala na dostęp do danych pomiarowych z dowolnego miejsca. Jeśli chcesz mieć dostęp do informacji ze swojego Smogomierza w każdym miejscu, to aqi.eco powinien w tym pomóc. Jest to wygodne rozwiązanie dla osób, które nie chcą tworzyć własnej bazy danych, a zależy im głównie na dostępnie do informacjach z własnego miernika.

## ThingSpeak

[ThingSpeak](https://thingspeak.com) to serwis, który pozwala na gromadzenie danych pomiarowych z różnych czujników oraz tworzenie wykresów do zgromadzonych danych. Wykresy oraz pomiary mogą być prywatne lub publicznie dostępne. Serwis wymaga rejestracji. Ma darmowe konta ograniczone do 3 mln pomiarów na rok. ThingSpeak pozwala na dostęp do danych pomiarowych z dowolnego miejsca. Wystarczy tylko login i hasło. Jeśli chcesz mieć dostęp do informacji ze swojego Smogomierza w każdym miejscu, to ThingSpeak powinien w tym pomóc. Dodatkowo serwis posiada aplikacje dostępne na smartfony. Jest to wygodne rozwiązanie dla osób, które nie chcą tworzyć własnej bazy danych, a zależy im głównie na dostępnie do informacjach z własnego miernika. Opis rejestracji w serwisie ThingSpeak oraz konfiguracji profilu znajdziesz w instrukcji ["ThingSpeak"](https://github.com/hackerspace-silesia/Smogomierz/blob/master/instrukcje/thingspeak.md).

## AirMonitor - ESP32

Serwis [AirMonitor](http://mapa.airmonitor.pl) pozwala na umieszczenie naszych danych pomiarowych na mapie. Dodatkowo umożliwia nam generowanie wykresów. Działa tylko z ESP32.

Jeśli chcesz wysyłać swoje dane do serwisu AirMonitor i wyświetlać swoje wykresy, to na początku musisz sprawdzić współrzędne geograficzne miejsca, gdzie znajduje się Twój Smogomierz. Może to zrobić na stronie https://www.wspolrzedne-gps.pl. Wystarczy tam wpisać adres, a uzyskamy szerokość oraz długość geograficzną. 

Musimy również wypełnić [formularz](https://airmonitor.pl/prod/station_registration), aby punkt z naszymi współrzędnymi pojawił się na mapie(Model sensora np. PMS7003). W formularzu długość i szerokość geograficzną wpisujemy w formacie xx.xxxx(np. 50.1234; używamy kropek, a nie przecinków).

Na koniec zostało nam tylko włączenie możliwości wysyłania danych pomiarowych w naszym mierniku. Możemy to zrobić oczywiście w zakładce Konfiguracja w panelu Smogomierza. Musimy tutaj również wpisać nasze współrzędne geograficzne(tutaj używamy formatu xx,xxx – np. 50,1234; używamy przecinków a nie kropek). Dodatkowo podanie wysokości umożliwi nam dokładniejsze pomiary ciśnienia atmosferycznego.

## InfluxDB

Smogomierz pozwala na wysyłanie pomiarów do własnej bazy danych [InfluxDB](https://www.influxdata.com/time-series-platform/influxdb/). Jeśli chcesz to zrobić, to w zakładce Konfiguracja w panelu Smogomierza, musisz włączyć wysyłanie danych do InfluxDB oraz wpisać adres swojej bazy danych, podać port na którym działa, nazwę bazy danych oraz użytkownika i hasło. InfluxDB jest świetnym źródłem danych dla Grafany, czyli darmowego środowiska do wizualizacji danych. [Grafana](https://grafana.com) pozwala na łatwe tworzenie wykresów ze zgromadzonych danych. 

## HomeKit

Jeśli jesteś użytkownikiem sprzętu Apple i Twoje urządzenie używa ESP32, to w ustawieniach możesz włączyć obsługę HomeKit. Dzięki temu będizesz mógł dodać swój miernik do aplikacji Dom na iPhonie/iPadzie/Macu. Domyślny kod dodawania nowych urządzeń to 111-11-111.

## Homebridge

Jeśli jesteś użytkownikiem sprzętu Apple, to możesz również skorzystać z wtyczki dla [Homebridge](https://github.com/nfarina/homebridge), aby mieć dostęp do danych pomiarowych w aplikacji Dom na swoim iPhonie, iPadzie lub na Macu. Wtyczka Homebridge-Smogomierz dostępna jest [tutaj](https://github.com/bfaliszek/homebridge-smogomierz).

## API

Każdy Smogomierz wyświetla pod adresem IP_Smogomierza/api aktualne dane pomiarowe w formacie JSON. Możesz ich użyć w dowolny sposób w swoich własnych projektach.

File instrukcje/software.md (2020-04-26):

# Smogomierz - instalacja oprogramowania

Poniższy opis krok po kroku, przeprowadzi Cię przez procedurę instalacji oprogramowania wymaganego do wgrania nowego systemu na Twój mierniki smogu. Całe oprogramowanie jest w pełni darmowe, a jego pobranie nie wymaga żadnej rejestracji i podawania swoich danych. Poniższy opis jest pomocny jeśli chcesz samemu skompilować oprogramowanie dla Smogomierza. Jeśli chcesz użyć gotowej, przygotowanej przez nas paczki, zajrzyj do opisu ["Wgrywanie pliku .bin z oprogramowaniem"](https://github.com/hackerspace-silesia/Smogomierz/blob/master/instrukcje/software-bin.md)

## Arduino - instalacja

Na początku musisz pobrać program ArduinoIDE. Pozwala on na programowanie płytek z rodziny Arduino. W późniejszym kroku, dodamy do niego obsługę wybranej przez nas płytki ESP(ESP32 lub ESP8266). To właśnie na niej oparty jest nasz mierniki smogu.

1. Pobieramy oprogramowanie ze strony https://www.arduino.cc/en/Main/Software. W tym celu musimy wybrać jaki system operacyjny mamy zainstalowany na komputerze, a następnie kliknąć na napis "Download the Arduino IDE". W przypadku korzystania z systemu Windows, zalecamy wybranie wersji "Installer, for Windows XP and up"
ArduinoIDE1

2. Klikamy napis "JUST DOWNLOAD". W tym momencie rozpocznie się pobieranie instalatora ArduinoIDE.
ArduinoIDE2

3. Instalujemy pobrany program. W przypadku Windowsa klikamy na niego 2 razy i instalujemy. W systemie macOS przenosimy do foldery Aplikacje. Na Linuksie uruchamiamy skrypt install.sh.

## Arduino - konfiguracja

Po zainstalowaniu ArduinoIDE, musisz dodać w nim obsługę płytek ESP.

1. Uruchamiamy aplikację ArduinoIDE i wybieramy "Plik > Preferencje" lub "Arduino > Preferences…" w przypadku systemu macOS.
ArduinoIDE3_1

2. W okienku „Dodatkowe adresy URL do menedżera płytek:” wpisujemy adres: http://arduino.esp8266.com/stable/package_esp8266com_index.json a linijkę niżej https://raw.githubusercontent.com/espressif/arduino-esp32/gh-pages/package_esp32_index.json
ArduinoIDE3_2

3. Po dodaniu adresu, skąd program może pobrać informacje o nowych płytkach, musimy je jeszcze pobrać. W tym celu klikamy "Narzędzia > Płytka > Menedżer płytek…".
ArduinoIDE3_3

4. W wyszukiwarce wpisujemy frazę: "esp8266" lub "esp32"(w zależności od tego jakiej wersji ESP użyliśmy do budowy Smogomierza) i instalujemy nowe płytki.
ArduinoIDE4

5. Teraz pozostaje nam tylko ustawić w ArduinoIDE, że nasz kod ma być dostosowany do płytek ESP8266, a nie standardowego Arduino. W tym celu musimy wybrać "Narzędzia > Płytka > NodeMCU 1.0 (ESP-12E Module)". W przypadku ESP32, wybieramy płytkę "Narzędzia > Płytka > ESP32 Dev Module"
ArduinoIDE5

6. Na koniec pozostaje nam wybranie portu szeregowego, go którego podłączona jest nasza płytka. W tym celu podpinamy ESP do portu USB w komputerze i wybieramy "Narzędzia > Port > COM3". W przypadku systemu innego niż Windows, zamiast "COM3" będziemy mieć inną opcję do wyboru np. "/dev/cu.wchusbserial1410". Jeśli pomimo podłączenia płytki do portu USB, na liście nie ma żadnej pozycji do wyboru, musimy jeszcze doinstalować sterownik odpowiedni sterownik. NodeMCu V3 korzysta z układy **CH340**. Sterowniki do niego można pobrać [tutaj](https://sparks.gogo.co.nz/ch340.html)(W przypadku systemu macOS, zalecamy instalację wersji 1.5 lub nowszej dostępnej [tutaj](https://github.com/adrianmihalko/ch340g-ch34g-ch34x-mac-os-x-driver)). Istnieje jednak możliwość, że Twoja płytka ma układ **CP2102**. Sterowniki do niego dostępnej są [tutaj](https://www.silabs.com/products/development-tools/software/usb-to-uart-bridge-vcp-drivers). Jeśli nie jesteś pewien jaki układ znajduje się na Twojej płytce ESP, zobacz informacje na spodzie płytki. Powinno być tam to napisane. Po pobraniu i instalacji odpowiednich sterowników, powinniśmy uruchomić ponownie komputer. Arduino powinno widzieć już nasza płytkę podłączoną do portu szeregowego.
ArduinoIDE6

7. Smogomierz zapisuje w pamięci wewnętrznej(SPIFFS) płytki ESP ustawienia. Robi to, aby po nonownym uruchomienie nie było konieczne wpisywanie wszystkich danych na nowo. Musimy się upewnić, że w ArduinoIDE wybraliśmy opcję stworzenia przestrzeni w pamięci na nasz plik konfiguracyjny. W tym celu dla ESP8266 musimy zaznaczyć opcję **4M (FS:1M OTA: ~1019KB)** z menu "Narzędzia > Flash Size > 4M (FS:1M OTA: ~1019KB)". Natomiast w przupadku ESP32, opcję **Minimal SPIFFS (1.9MB APP with OTA/190KB SPIFFS)** z menu "Narzędzia > Partition Scheme".
ArduinoIDE7

8. Kod, który będziemy wgrywać na płytki ESP wymaga do poprawnego działania, dwóch zewnętrznych bibliotek. Aby je dodać wystarczy wybrać z menu ArduinoIDE "Szkic > Dołącz bibliotekę > Zarządzaj bibliotekami...".
ArduinoIDE8

9. W wyszukiwarce wpisujemy nazwę biblioteki i następnie ją instalujemy. Biblioteki, które musimy doinstalować to: **ArduinoJson(w wersji 6.5.0 lub nowszej)** oraz najnowsze wersje bibliotek: **Adafruit BMP280 Library**, **DHT sensor library by Adafruit**, **ThingSpeak**, **Adafruit Unified Sensor**, **DallasTemperature**, **OneWire**(by Jim Studt, tom Pollard…) oraz **PubSubClient**.
ArduinoIDE10

10. Musimy jeszcze doinstalować kilka bibliotek, poprzed dodanie plików .zip. Tymi bibliotekami są: [ESPAsyncWebServer](https://github.com/me-no-dev/ESPAsyncWebServer) oraz [ESPAsyncTCP](https://github.com/me-no-dev/ESPAsyncTCP). W przypadku ESP32 musimy doinstalować jeszcze [AsyncTCP](https://github.com/me-no-dev/AsyncTCP). W przypadku ESP32 musimy również doinstalować Pythona3 oraz [pyserial](https://pypi.org/project/pyserial/).

11. Teraz wszystko jest już gotowe do obsługi naszych mierników smogu. Możemy przejść do pobrania oprogramowania i sprawdzenia czy działa.

## Smogomierz - pobranie i wgranie oprogramowania na płytkę ESP

1. Wchodzimy na stronę projektu Smogomierz w serwisie github i pobieramy pliki: https://github.com/hackerspace-silesia/Smogomierz/
Github1

2. Rozpakowujemy pobraną paczkę. Zmieniamy nazwę folderu ze "Smogomierz-master" na "Smogomierz" i otwieramy plik Smogomierz.ino, który znajduje się w środku.

3. Otworzy się nam okienko programu ArduinoIDE z kodem naszej aplikacji Smogomierza.  
ArduinoIDE7

1 – Sprawdzenie poprawności oprogramowania

2 – Wgranie oprogramowania na płytkę

3 – Postęp weryfikacji/wgrywania oprogramowania i ewentualne błędy

4 – Płytka oraz port, które mamy ustawione

4. Zanim wgramy nasz kod na płytkę ESP, możemy w nim ustawić kilka wartości. Wśród nich np. miejsce, gdzie będzie znajdował się nasz miernik. W tym celu musimy otworzyć plik defaultConfig.h. Wszystkie ustawenia można w dowolnej chwili modyfikować przez przeglądarkę internetową, dlatego zmiana czegokolwiek w defaultConfig.h jest opcją dodatkową.

5. Wartości, które możemy zmienić, to szerokość(LATITUDE) i długość(LONGITUDE) geograficzna oraz wysokość na jakiej będzie znajdował się nasz miernik(MYALTITUDE). Wszystkie te dane możemy uzyskać na stronie https://www.wspolrzedne-gps.pl. Wystarczy tam wpisać adres, gdzie miernik zostanie umieszczony. Obecnie wpisane dane, to współrzędne lokalu Hackerspace Silesia. Długość i Szerokość geograficzna jest wymagana, aby nasze dane pojawiły się we właściwym miejscu w serwisie [mapa.airmonitor.pl](http://mapa.airmonitor.pl). Dodatkowo musimy wypełnić [formularz](https://docs.google.com/forms/d/e/1FAIpQLSdw72_DggyrK7xnSQ1nR11Y-YK4FYWk_MF9QbecpOERql-T2w/viewform), aby punkt z naszymi współrzędnymi pojawił się na mapie(Model sensora: PMS7003).
ArduinoIDE12

6. Miernik pozwala na wysyłanie danych do serwisu [ThingSpeak](https://thingspeak.com). ThingSpeak wymaga rejestracji i założenia darmowego konta. Pozwoli to na przesyłanie naszych pomiarów do tego serwisu i uzyskanie wykresów zanieczyszczeń oraz danych o temperaturze, wilgotności i ciśnieniu powietrza. Opis rejestracji i konfiguracji kanału w serwisie ThingSpeak znajdziecie [TUTAJ](https://github.com/hackerspace-silesia/Smogomierz/blob/master/instrukcje/thingspeak.md). W celu dodania obsługi serwisu ThingSpeak, w pliku defaultConfig.h musimy zmienić trzy parametry: Wpisać odpowiednie dane do THINGSPEAK_API_KEY(parametr "Key" ze strony ThingSpeak) oraz THINGSPEAK_CHANNEL_ID(parametr "Channel ID"), a w THINGSPEAK_ON zmienić słowo "false" na "true".
ArduinoIDE13

7.  Miernik jest również w stanie wysyłać dane do serwisu [aqi.eco](https://aqi.eco). Instrukcja konfiguracji aqi.eco znajduje się na [osobnej stronie](aqi-eco.md).

8. Teraz możemy zweryfikować nasz kod(Punkt 3., podpunkt 1.). Jeśli wszystko poprawnie się skompiluje możemy przejść do składania fizycznych części naszego miernika smogu. Dokładny opis w [Instrukcja podłączenia elektroniki](https://github.com/hackerspace-silesia/Smogomierz/blob/master/instrukcje/hardware.md).

9.  Wszystkie wartości podane w pliku defaultConfig.h są domyślnymi wartościami potrzebnymi przy pierwszym uruchomieniu miernika. Każdą z tych pozycji można w dowolnej chwili zmienić w zakładce Ustawienia w panelu Smogomierza.

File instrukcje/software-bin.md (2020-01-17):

# Smogomierz - wgrywanie pliku .bin z oprogramowaniem

Poniższy opis krok po kroku, przeprowadzi Cię przez procedurę wgrywania oprogramowania z pliku .bin na Twój mierniki smogu. Poniższy opis jest pomocny jeśli nie chcesz zmieniać przygotowanego przez nas oprogramowania dla Smogomierza. Jeśli planujesz dopisać własny kod, lub chcesz samemu skompilować plik .bin z oprogramowaniem dla Miernika zajrzyj do opisu ["Instalacja oprogramowania"](https://github.com/hackerspace-silesia/Smogomierz/blob/master/instrukcje/software.md)

Pliki .bin można wgrać na płytkę ESP32/ESP8266 na kilka sposobów. Jeśli masz już działający Smogomierz, wystarczy, że wejdziesz przez przeglądarkę internetową w kartę Update i wybierzesz tam plik .bin. Oprogramowanie zrobi resztę. Przeinstaluje się na nowsza wersję i uruchomi ponownie miernik smogu. Jeśli jednak wgrywasz oprogramowanie po raz pierwszy będziesz musiał skorzystać z połączenia przewodowego i podłączyć ESP do portu USB w komputerze.

Najnowszą wersję oprogramowania dla Smogomierza znajdziesz zawsze [tutaj](https://github.com/hackerspace-silesia/Smogomierz/releases).

## Sterowniki

Jeśli nigdy wcześniej nie korzystaliśmy z Arduino ani ESP32/ESP8266 lub podobnych rozwiązań, będziemy musieli zainstalować sterowniki, aby nasz system widział podłączoną do USB płytkę ESP32/ESP8266.

NodeMCu V3 korzysta najczęściej z układu **CH340**. Sterowniki do niego można pobrać [tutaj](https://sparks.gogo.co.nz/ch340.html)(W przypadku systemu macOS, zalecamy instalację wersji 1.4 dostępnej [tutaj](https://github.com/adrianmihalko/ch340g-ch34g-ch34x-mac-os-x-driver)). 
Istnieje jednak możliwość, że Twoja płytka ma układ **CP2102**. Sterowniki do niego dostępnej są [tutaj](https://www.silabs.com/products/development-tools/software/usb-to-uart-bridge-vcp-drivers). 
Jeśli nie jesteś pewien jaki układ znajduje się na Twojej płytce NodeMCu, zobacz informacje na spodzie płytki. Powinno być tam to napisane. 
Po pobraniu i instalacji odpowiednich sterowników, powinniśmy uruchomić ponownie komputer. 

## Flasher

Nazwa brzmi trochę strasznie, ale to oprogramowanie służące do wgrywania plików .bin na płytkę ESP. Istnieją różne programy służące do wgrywania plików .bin. Polecamy użycie **NodeMCU PyFlasher**. To darmowy program z graficznym interfejsem użytkownika. Działa zarówno pod systemem Windows jak i macOS. Można go pobrać [tutaj](https://github.com/marcelstoer/nodemcu-pyflasher/releases). 
W przypadku Linuksa(działa również na macOS) zalecamy instalację narzędzia konsolowego: [esptool](https://github.com/espressif/esptool). 
PyFlasher1

W przypadku aktualizacji oprogramowania pamiętaj o tym, aby zmienić opcję "Erase flash" na "no". W przeciwnym wypadku wszystkie Twoje ustawienia zostaną skasowane. W przypadku problemów z uruchomieniem się Smogomierza po wgraniu oprogramowania, warto wgrać je jeszcze raz z włączonym wymazaniem pamięci.

## Aktualizacja oprogramowania

W celu aktualizacji oprogramowania najlepiej wejść w zakładkę Update w panelu Smogomierza. Pozwala ona na wgrywanie plików .bin z nową wersją oprogramowania dla miernika. 

Najnowszą wersję oprogramowania dla Smogomierza znajdziesz zawsze [tutaj](https://github.com/hackerspace-silesia/Smogomierz/releases).

Plik .bin można stworzyć samemu z kodu dostępnego w tym repozytorium. Do zrobienia tego potrzebne jest ArduinoIDE – [Instrukcja instalacji wymaganego oprogramowania](https://github.com/hackerspace-silesia/Smogomierz/blob/master/instrukcje/software.md). W "Plik > Preferencje" lub "Arduino > Preferences…" zaznaczamy przy "Pokaż szczegółowe informacje podczas:" opcję "Kompilacji". W czasie kompilowania naszego kodu, na dole ekranu ArduinoIDE pojawią się adresy(coś w stylu "/var/folders/k9/tbv_kmpn1dj5fl5spjk209480000gn/T/arduino_build_795090/Smogomierz.ino.bin"), gdzie zostanie zapisany plik Smogomierz.ino.bin. Plik ten to właśnie paczka z naszym oprogramowaniem, które możemy wgrać przez kartę Update w panelu Smogomierza.

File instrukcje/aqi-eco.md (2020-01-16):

# aqi.eco - opis

aqi.eco to serwis, dzięki któremu w atrakcyjny sposób wyświetlisz wyniki pomiarów czystości powietrza, zmierzone urządzeniami Smogomierz, Nettigo Air Monitor lub Luftdaten.

## Rejestracja

1.  Rejestrujemy się na [aqi.eco](https://aqi.eco/register).
2.  Po rejestracji i zalogowaniu, klikamy na [Urządzenia](https://aqi.eco/device) i znaczek [plusa](https://aqi.eco/device/create).
3.  Jako ESP8266 ID należy wpisać część numeryczną nazwy "ChipID" ze strony konfiguracyjnej czujnika (np. dla czujnika `ChipID: smogomierz-14958720` musimy wpisać 14958720).
4.  Po dodaniu czujnika otworzy się strona konfiguracyjna. Kopiujemy z niej pola "Adres serwera" i "Ścieżka".
5.  Otwieramy stronę Smogomierza i zaznaczymy:
*   Wysyłanie danych do aqi.eco: *Tak*
*   Adres serwera aqi.eco: *skopiowane z aqi.eco*
*   Ścieżka aqi.eco: *skopiowane z aqi.eco*
6.  Po zapisaniu ustawień Smogomierz zacznie wysyłać dane do aqi.eco.

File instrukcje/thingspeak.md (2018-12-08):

# ThingSpeak - opis

ThingSpeak to serwis, który pozwala na gromadzenie danych pomiarowych z różnych czujników oraz tworzenie wykresów do zgromadzonych danych. Wykresy oraz pomiary mogą być prywatne lub publicznie dostępne. Serwis wymaga rejestracji. Ma darmowe konta ograniczone do 3 mln pomiarów na rok. Więcej info w [FAQ](https://thingspeak.com/pages/license_faq) i na stronie [ThingSpeak.com](https://thingspeak.com). ThingSpeak pozwala na dostęp do danych pomiarowych z dowolnego miejsca. Wystarczy tylko login i hasło. Jeśli chcesz mieć dostęp do informacji ze swojego Smogomierza w każdym miejscu, to ThingSpeak powinien w tym pomóc. Dodatkowo serwis posiada aplikacje dostępne na smartfony. Jest to wygodne rozwiązanie dla osób, które nie chcą tworzyć własnej bazy danych, a zależy im głównie na dostępnie do informacjach z własnego miernika.

##  Rejestracja

1. Po wejściu na stronę [ThingSpeak.com](https://thingspeak.com), klikamy przycisk "Sign Up"(prawy górny róg strony). 

2. Podajemy nasz email, login oraz hasło, wybieramy kraj oraz podajemy imię i nazwisko.
ThingSpeak1

3. Po rejestracji i zalogowaniu się na nasze nowe konto, musimy utworzyć nowy kanał. Na każdy kanał możemy wysyłać 8 równych pomiarów. W naszym przypadku wystarczy 1 kanał, gdyż będziemy wysyłać 6 pomiarów(PM1, PM2.5, PM10, Temperatura, Wilgotność i Ciśnienie). W celu stworzenia nowego kanału klikamy na zielony przycisk "Channels". a następnie na zielone "New Channel".
ThingSpeak2

4. Wypełniamy pole Name oraz pola Field od 1 do 6. Podobnie jak na screenie powyżej. Możemy również podać wysokość w metrach oraz położenie naszego miernika. W tym celu musimy uzupełnić pole Elevation oraz Latitude i Longitude. Na koniec klikamy na zielony przycisk "Save Channel" na dole strony.

5. Po stworzeniu nowego kanału możemy dodać opisy do wykresów. W tym celu klikamy na symbol ołówka nad każdym wykresem i w polu "Title" wpisujemy nazwę wykresu.
ThingSpeak3

6. Kolejnym krokiem jest wybranie karty "API Keys". Potrzebujemy z niej pobrać dwa bardzo ważne ciągi znaków: "Channel ID" oraz "Key". Te dwie wartości są unikalne dla każdego użytkownika i będziemy je musieli ustawić w pliku config.h naszego miernika, jeśli chcemy aby nasze pomiary były wizualizowane na wykresach.
ThingSpeak4

7. Pozostała nam jeszcze jedna rzecz do zrobienia na stronie ThingSpeak - ustawienie kwestii prywatności. Przechodzimy do karty "Sharing". Domyślnie zaznaczona opcja to "Keep channel view private". Oznacza ona, że dane przesłane do serwisu ThingSpeak będą widoczne tylko nam. Oznacza to również, że wykresy na naszym mierniku smogu będzie widzieć tylko osoba zalogowana na nasze konto w serwisie ThingSpeak. Jeśli jesteśmy jedyną osobą, która ma mieć dostęp do miernika, to nie musimy niczego zmieniać, ale jeśli będziemy chcieli pokazywać nasze dane pomiarowe innym osobom, warto zmienić ten parametr na "Share channel view with everyone". Dzięki temu nawet, gdy się wylogujemy z serwisu ThingSpeak, lub ktoś inny będzie chciał zobaczyć pomiary naszego miernika, będzie mógł to zrobić. Po zaznaczeniu opcji "Share channel view with everyone", warto również przejść do karty "Public View" i ponownie ustawić opisy wykresów(podobnie jak w punkcie 5.).
ThingSpeak5

Gotowe! Nowy kanał w serwisie ThingSpeak jest już w pełni gotowy do obsługi naszego miernika smogu. Pozostało jedynie przepisać "Channel ID" oraz "Key" do pliku konfiguracyjnego config.h. Jak to zrobić? Zajrzyj do [Instrukcja instalacji wymaganego oprogramowania](https://github.com/hackerspace-silesia/Smogomierz/blob/master/instrukcje/software.md)

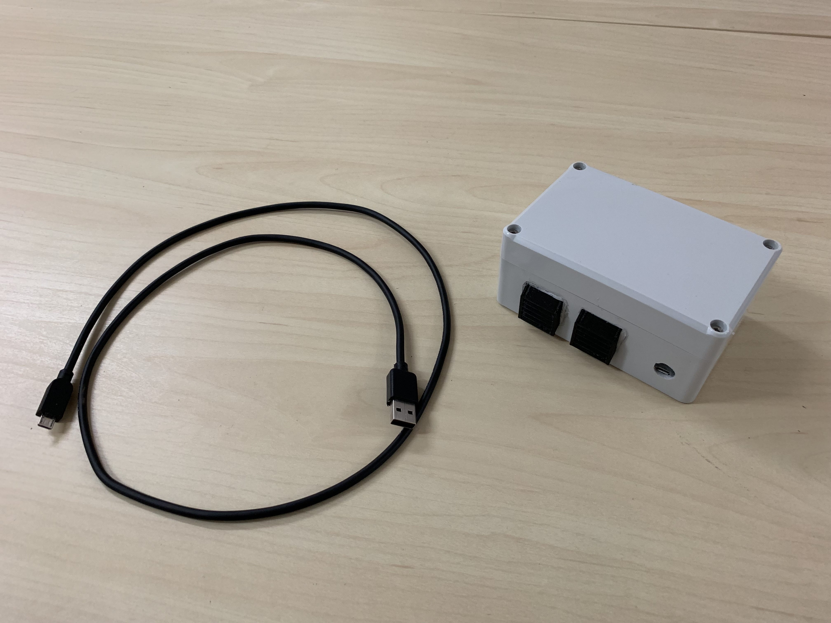
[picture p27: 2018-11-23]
instrukcje/photos/Smogomierz2.jpg

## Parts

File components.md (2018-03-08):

# Smogomierz - Components / Podzespoły

Lista elementów potrzebnych do zbudowania miernika smogu. Podane linki to przykładowe miejsca, w których można kupić dany produkt. Każdą z wymienionych cześci można kupić w dowolnym sklepie. Zastosowane elementy, to łatwodostępne podzespoły, które dostępne są w większości sklepów z elektroniką. 

## Układ główny

**ESP8266 – NodeMCu V3** – https://www.aliexpress.com/item/V3-Wireless-module-NodeMcu-4M-bytes-Lua-WIFI-Internet-of-Things-development-board-based-ESP8266-esp/32647542733.html

## Mierniki

**PMS7003** – Laserowy miernik pyłu PM1, PM2.5 i PM10 – https://www.aliexpress.com/item/1-set-Laser-PM2-5-PMS7003-G7-High-precision-laser-dust-concentration-sensor-digital-dust-particles/32826370928.html 

**BME280** – Miernik temperatury, wilgotności - ciśnienia powietrza – https://www.aliexpress.com/item/High-Accuracy-BME280-Digital-Sensor-Temperature-Humidity-Barometric-Pressure-Sensor-Module-GY-BME280-I2C-SPI-1/32672210336.html 

## Obudowa

Do wyboru mamy dwie możliwości. Polecamy zastosowanie obudowy **IP56**. Nie wymaga ona drukowania elementów na drukarce 3D. Niezależnie od wyboru.

+ **Obudowa IP55**, minimum 86x86 mm – http://allegro.pl/puszka-natynkowa-czarna-ep-lux-ip55-0226-02-86x86x-i7038770485.html 

	Dwa element umożliwiający przepływ powietrza przez obudowę do wydrukowania na drukarce 3D / Two 3D printed parts – https://github.com/hackerspace-silesia/Smogomierz/blob/master/80x80x40mm.stl

+ **Obudowa IP56**, 120x80x50mm – http://allegro.pl/puszka-hermetyczna-ip56-120x80x50mm-przezroczysta-i6661288346.html

## Pozostałe części

**Wtyczka** – microUSB – https://www.aliexpress.com/item/1pcs-MICRO-USB-to-DIP-Adapter-5pin-female-connector-B-type-pcb-converter-pinboard-2-54/32666589270.html 

**Przewody** do połączenia(żeńskie/female) wszystkich elementów – https://www.aliexpress.com/item/Free-Shipping-80pcs-dupont-cable-jumper-wire-dupont-line-female-to-female-dupont-line-20cm-1P/701588771.html 

**Goldpiny** – http://allegro.pl/wtyk-szpilkowy-goldpin-arduino-avr-pic-80szt-fv-i6846674238.html 

## Narzędzia

Lutownica(wraz z cyną) oraz pistolet do kleju na gorąco oraz nóż do tapet, do zlutowania, sklejenia i wycięcia niektórych z wymienionych wyżej elementów. W przypadku obudowy IP56 przyda się również wiertarka.

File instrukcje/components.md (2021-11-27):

# Smogomierz - Components / Podzespoły

Wszystkie potrzebne części możesz zamówić w sklepie internetowym **Botland**. Oferuje on gotowe zestawy z ESP8266(zalecam jednak wybrać mocniejsze ESP32) – https://botland.com.pl/pl/czujniki-czystosci-powietrza/13434-zestaw-diy-do-budowy-miernika-smogu-czujnik-czystosci-powietrza-pm25-i-pm10.html

Jeśli jednak wolisz kupić wszystkie części samodzielnie, to poniżej znajdziesz listę potrzebnych elementów. Podane linki to przykładowe miejsca, w których można kupić dany produkt. Każdą z wymienionych części można kupić w dowolnym sklepie. Zastosowane elementy to łatwo dostępne podzespoły, które znajdziesz w większości sklepów z elektroniką. 

## Układ główny
Główny układ sterujący Smogomierzem to ESP32 lub ESP8266 w wersji ESP-12. Zalecamy użycie **ESP32**(ma znacznie więcej pamięci niż ESP8266), jednak bez problemu oprogramowanie będzie działać też na ESP8266(np. NodeMCu V3, WeMos D1).

+ **ESP32** – https://www.aliexpress.com/item/32928267626.html

+ **ESP8266 – NodeMCu V3** – https://www.aliexpress.com/item/V3-Wireless-module-NodeMcu-4M-bytes-Lua-WIFI-Internet-of-Things-development-board-based-ESP8266-esp/32647542733.html

## Mierniki PM2.5 i PM10

Oprogramowanie Smogomierza wspiera obecnie kilka różnych modeli mierników pyłu zawieszonego w powietrzu. Zalecamy użycie miernika ***Sensrion SPS30*** lub **PMS7003**. Lista obsługiwanych modeli znajduje się poniżej:

+ **PMS5003/PMS7003** – Laserowy miernik pyłu PM1, PM2.5 i PM10. Polecam zamówić wersję z kablem, bo bezpośrednio do PMS7003 praktycznie nie da się przylutować/podłaczyć przewodów. Przykładowy model z kablem – https://www.aliexpress.com/item/1-set-Laser-PM2-5-PMS7003-G7-High-precision-laser-dust-concentration-sensor-digital-dust-particles/32826370928.html 

+ **Honeywell HPMA115S0** – Laserowy miernik pyłu PM1, PM2.5 i PM10 – https://www.tme.eu/pl/details/hpma115s0-xxx/czujniki-gazu/honeywell/

+ **Sensirion SPS30** – Laserowy miernik pyłu PM1, PM2.5, PM4 i PM10 – https://www.tme.eu/pl/details/sps30/czujniki-gazu/sensirion/1-101638-10/ Warto zamiętać o zakupue specjalnego kabla dla SPS30 - JST ZH 1.5. Wtyczka posiada 5 pinów i raster 1,5mm - https://allegro.pl/oferta/jst-zh-1-50mm-5pin-wtyczka-z-kablami-8129839140

+ **SDS011** – Laserowy miernik pyłu PM2.5 i PM10 – https://www.aliexpress.com/item/Nova-PM-sensor-SDS011-High-precision-laser-pm2-5-air-quality-detection-sensor-module-Super-dust/32606349048.html

## Mierniki temperatury, wilgotności i ciśnienia

Smogomierza wspiera obecnie kilka różnych modeli mierników temperatury, wilgotności i ciśnienia powietrza. Najistotniejszym elementem jest tutaj pomiar wilgotności powietrza. Wilgotność wpływa na pomiary pyłu PM2.5 oraz PM10(przy wilgotności >60% mierniki zaczynają wykrywać parę wodną jako zanieczyszczenia powietrza). Smogomierz pozwala na automatyczną kalibrację pomiarów pyłu zawieszonego, jednak potrzebuje do tego pomiarów wilgotności powietrza. Zalecamy użycie miernika **BME280**. Lista obsługiwanych modeli znajduje się poniżej:

+ **BME280** – Miernik temperatury, wilgotności i ciśnienia powietrza – https://www.aliexpress.com/item/High-Accuracy-BME280-Digital-Sensor-Temperature-Humidity-Barometric-Pressure-Sensor-Module-GY-BME280-I2C-SPI-1/32672210336.html 

+ **HTU21D** – Miernik temperatury i wilgotności powietrza – https://www.aliexpress.com/item/New-HTU21D-Temperature-and-Humidity-Sensor-Module/32476325114.html

+ **DHT22** – Miernik temperatury i wilgotności powietrza – https://www.aliexpress.com/item/DHT22-single-bus-digital-temperature-and-humidity-sensor-module-2302-electronic-building-blocks/32753887461.html

## Obudowa

Do wyboru mamy kilka możliwości. Polecamy zastosowanie modelu **IP55**. Obudowa chroni elektronikę przed bezpośrednim kontaktem z wodą. Musi umożliwiać swobodny przepływ powietrza, ale jednocześnie chronić przez deszczem. Jeśli chcesz możesz użyć jakiejś zupełnie innej obudowy, pamiętaj jednak do przepływie powietrza oraz wymiarach. Na wszystkie elementy Smogomierza potrzebne jest około 120 x 80 x 50 mm. Zwłaszcza jeśli postanowiłeś użyć miernika SDS011. 

+ **Obudowa IP55**, 118 x 78 x 55 mm – https://botland.com.pl/pl/obudowy/6235-obudowa-plastikowa-kradex-z57j-118x78x55mm-jasna.html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

+ **Obudowa IP67**, 118 x 78 x 55 mm – https://botland.com.pl/pl/obudowy/9051-obudowa-plastikowa-kradex-z57js-abs-z-uszczelka-i-mosieznymi-tulejkami-ip67-118x78x55mm-jasna.html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

+ **Obudowa IP56**, 120 x 80 x 50 mm – http://allegro.pl/puszka-hermetyczna-ip56-120x80x50mm-przezroczysta-i6661288346.html

	Opcjonalne, choć bardzo mocno zalecane jest użycie dwóch elementów chroniących otwory umożliwiające przepływ powietrza przez obudowę. Elementy te można wydrukować na drukarce 3D / Two 3D printed parts – https://github.com/hackerspace-silesia/Smogomierz/blob/master/instrukcje/80x80x40mm.stl

## Pozostałe części

Elementy potrzebne do podłączenia całości. 

+ **Wtyczka** – microUSB – https://www.aliexpress.com/item/1pcs-MICRO-USB-to-DIP-Adapter-5pin-female-connector-B-type-pcb-converter-pinboard-2-54/32666589270.html 

+ **Przewody** do połączenia(żeńskie/female) wszystkich elementów – https://www.aliexpress.com/item/Free-Shipping-80pcs-dupont-cable-jumper-wire-dupont-line-female-to-female-dupont-line-20cm-1P/701588771.html 

+ **Goldpiny** – http://allegro.pl/wtyk-szpilkowy-goldpin-arduino-avr-pic-80szt-fv-i6846674238.html 

## Narzędzia

Lutownica(wraz z cyną) oraz pistolet do kleju na gorąco, wiertarka oraz nóż do tapet i śrubokręt do skręcenia obudowy. 

Jeśli masz już wszystkie części, to pamiętaj, że kilka z nich wymaga przylutowania pinów. Opis wszystkiego co trzeba zlutować wraz ze zdjęciami znajdziesz w instrukcji ["Lutowanie"](https://github.com/hackerspace-silesia/Smogomierz/blob/master/instrukcje/soldering.md).

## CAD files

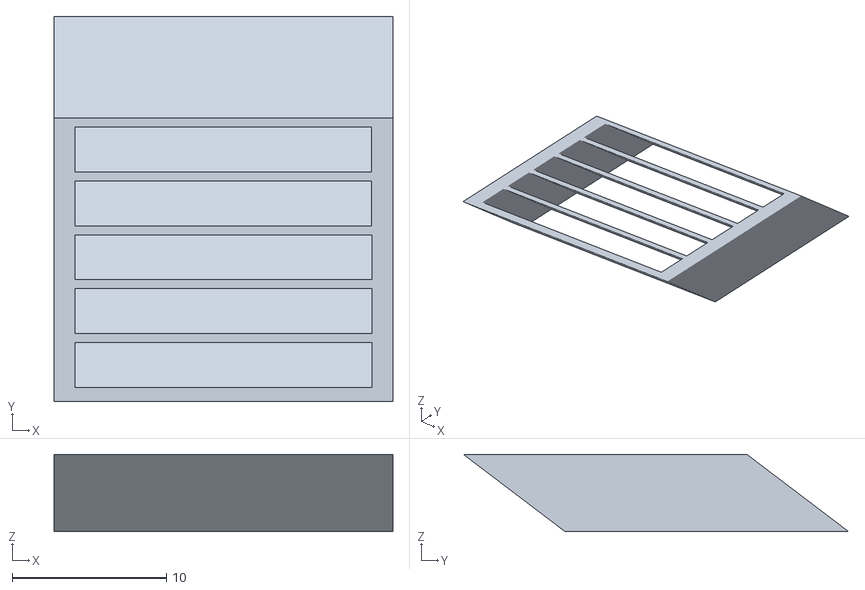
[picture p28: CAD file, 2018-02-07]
instrukcje/80x80x40mm.stl
22.0 x 25.0 x 5.00

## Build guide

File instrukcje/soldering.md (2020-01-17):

# Smogomierz - lutowanie

W przypadku kilku części używanych w Smogomierzy konieczne użycie lutownicy. Lutowanie jest tutaj ograniczone do minimum i w 90% polega na przylutowaniu pinów do mierników. Dla przykładu miernik temperatury, wilgotności i ciśnienia powietrza BME280 najcześciej dostaje się w woreczku razem z pinami do przylotowania. Podobnie z wtyczką microUSB, której użyjemy jako źródło zasilania Smogomierza. Będziemy musili również zlutować ze sobą trzy goldpiny, aby stworzyć rozdzielacz zasilania 5V.

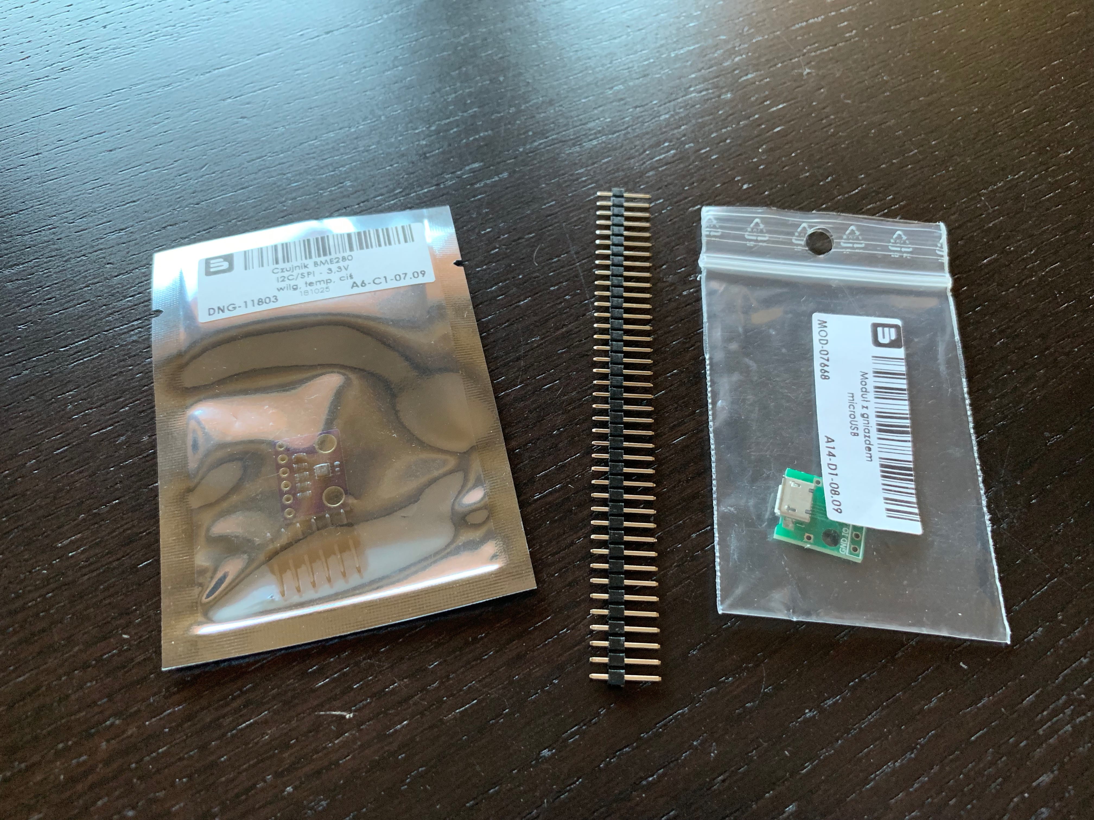
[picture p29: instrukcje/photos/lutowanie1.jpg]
lutowanie1


## BME280 oraz wtyczka microUSB

W przypadku obu tych elementów sprawa jest dosyć prosta. Musimy w otwory w miernikach wlutować goldpiny.

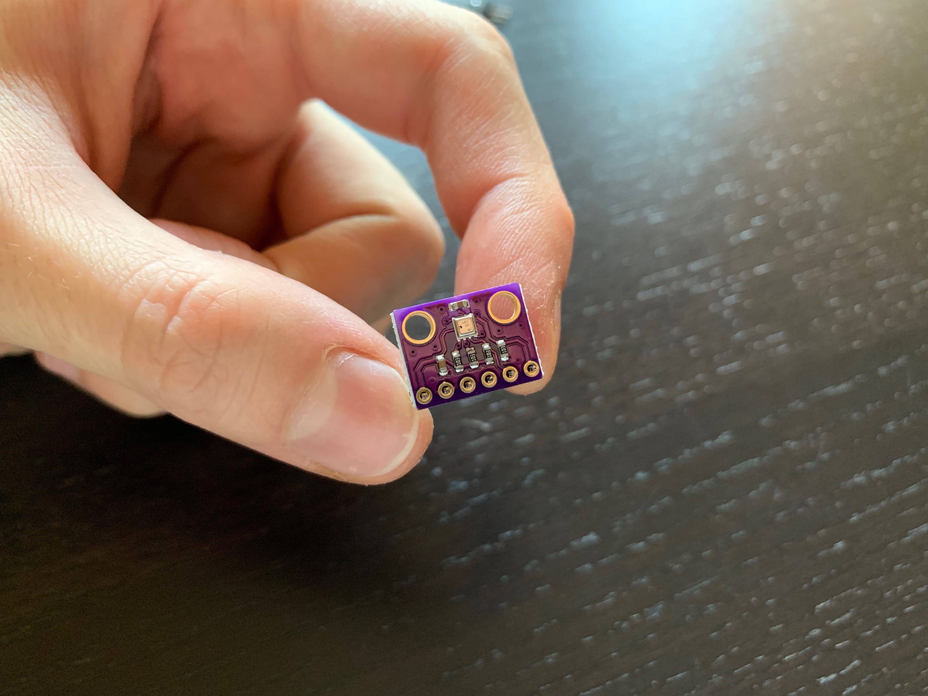
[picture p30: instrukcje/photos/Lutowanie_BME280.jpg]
Lutowanie_BME280

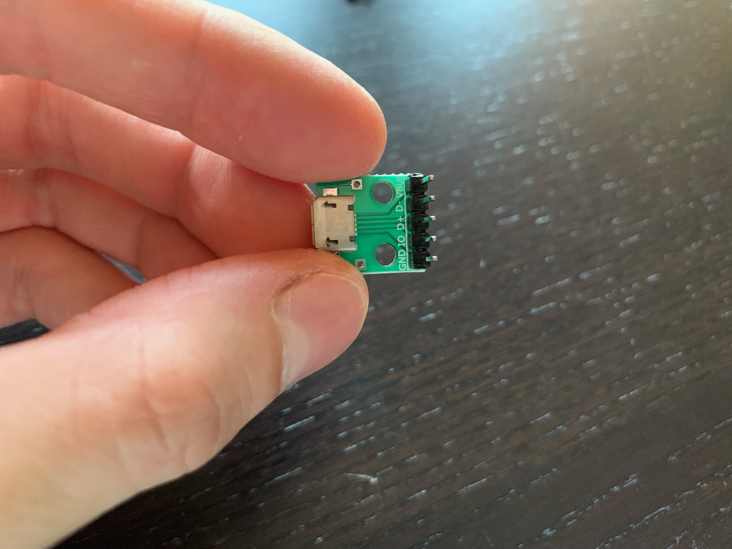
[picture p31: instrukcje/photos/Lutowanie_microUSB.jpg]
Lutowanie_microUSB


## Rozdzielacz 5V

W celu jednoczesnego zasilania ESP oraz miernika zanieczyszczeń powietrza, musimy przygotować rozdzielacz napięcia 5V. Nie jest to nic skomplikowanego. Można go zrobić na wiele sposobów. Postanowiliśmy użyć do tego trzech goldpinów i je ze sobą zlutować.

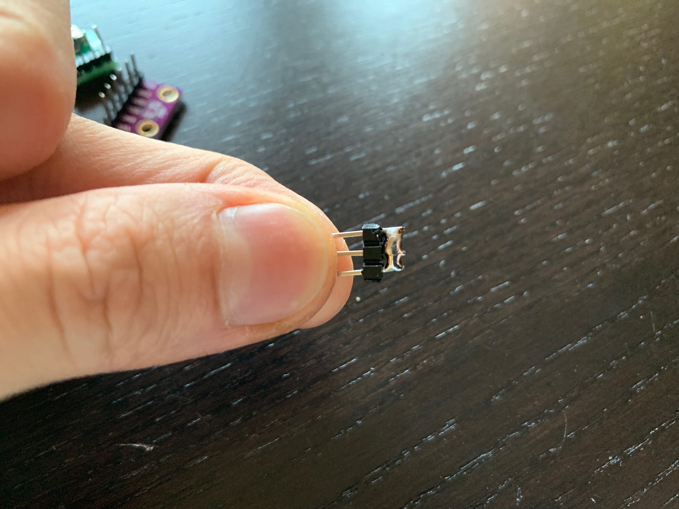
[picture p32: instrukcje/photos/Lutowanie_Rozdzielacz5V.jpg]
Lutowanie_Rozdzielacz5V


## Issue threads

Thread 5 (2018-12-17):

Temperatura i wilgotność w API i interfejsie

jozwikp, 2018-12-17:
Brak danych o temperaturze i wilgotności w odpowiedzi API oraz w interfejsie pomimo włączonego czujnika w konfiguracji.

jozwikp, 2018-12-17:
ok widzę w kodzie, że jest funkcja sprawdzająca status czujnika i u mnie pewnie coś nie działa. Sprawdzę jeszcze raz połączenia.

bfaliszek, 2018-12-17:
Jaki masz model czujnika? Jeśli BME280 to powinny być wszystkie dane na stronie /api w takiej formie(JSON) jak poniżej:
```
{
  "device_name": "Smogomierz-3909D1",
  "pm1": 102,
  "pm25": 195,
  "pm10": 259,
  "temperature": 4.25,
  "pressure": 1026,
  "humidity": 76,
  "dewpoint": -0.413086
}
```

jozwikp, 2018-12-17:
Tak cos nie dziala u mnie.
Czujnik z zestawu botland nie dziala.

W dniu pon., 17.12.2018 o 18:45 Blazej Faliszek <notifications@github.com>
napisał(a):

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
--
Sent from Gmail Mobile

ziyo98, 2018-12-17:
Witajcie, U mnie to samo ( czujnik z zestawu nie działa). Wymieniłem na inny i wszystko śmiga.

jozwikp, 2018-12-17:
czy orientujecie się, czy zadziała DHT11? Jeśli tak to jak podłączyć bo mam tu tylko dout.

bfaliszek, 2018-12-17:
@jozwikp nie testowałem z DHT11, ale działa DHT22 https://github.com/hackerspace-silesia/Smogomierz/blob/master/instrukcje/hardware.md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ści-powietrza Nie polecam używania DHT22 a co dopiero DHT11, one często podają bardzo dziwne dane i skokowo mają jakieś szalone pomiary. Może to nieźle namieszać jeśli włączysz w konfiguracji automatyczną kalibrację pomiarów(wykorzystuje ona wilgotność powietrza do kalibracji pomiarów PM).

@ziyo98 z jakiego modelu miernika temperatury/wilgotności korzystasz? BME280? Część osób, która zamówiła zestawy w Botlandzie dostała wersję Adafriut, podpina się ją troszkę inaczej: https://github.com/hackerspace-silesia/Smogomierz/blob/master/instrukcje/hardware.md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ści-i-ciśnienia-powietrza Ostatnio wysłali też zestawy z BME280 SparkFun, ale nie miałem okazji ich testować.

ziyo98, 2018-12-18:
dokładnie tego SparkFun'a dostałem: [https://botland.com.pl/pl/czujniki-pogodowe/4901-bme280-cyfrowy-czujnik-wilgotnosci-temperatury-i-cisnienia-atmosferycznego-i2cspi.html](https://botland.com.pl/pl/czujniki-pogodowe/4901-bme280-cyfrowy-czujnik-wilgotnosci-temperatury-i-cisnienia-atmosferycznego-i2cspi.html)  .
On ma jeszcze możliwość adresacji i dołożenia pull-up'a , ale nie miałem czasu tego rozkminiac. Na razie wsadziłem takiego: [https://botland.com.pl/pl/czujniki-cisnienia/11803-bme280-czujnik-wilgotnosci-temperatury-oraz-cisnienia-110kpa-i2cspi-33v.html](https://botland.com.pl/pl/czujniki-cisnienia/11803-bme280-czujnik-wilgotnosci-temperatury-oraz-cisnienia-110kpa-i2cspi-33v.html) .

jozwikp, 2018-12-18:
Ja tez mam tego sparkfuna. ktoś wie już jak go zmusić do działania?

firemark, 2018-12-18:
Czy nie powinno wystarczyć podłączenie SDA, SCL, VCC i GND względem https://github.com/hackerspace-silesia/Smogomierz/blob/master/instrukcje/hardware.md?

Jeżeli jest już dobrze podłączone, to może się okazał że adres do BME280 jest inny niż powinnien być.

Adres możesz zmienić tutaj: https://github.com/hackerspace-silesia/Smogomierz/blob/master/src/bme280.h#L18 - prawd. jest gdzieś w PDFie sparkfuna

bfaliszek, 2018-12-18:
Adafriut domyślnie ma adres 0x77. W Adafriut można podłączyć SDO do GND w ESP8266 i zmienia adres na 0x76. Nie trzeba wtedy zmieniać nic w kodzie.

W przypadku SparkFun też jest domyślnie 0x77. Chyba w przypadku SparkFun  trzeba zmienić ręcznie w kodzie lub zlutować odpowiednie piny https://learn.sparkfun.com/tutorials/sparkfun-bme280-breakout-hookup-guide/all

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

bfaliszek, 2018-12-18:
@jozwikp zrobię to dziś wieczorem.

bfaliszek, 2018-12-18:
@jozwikp @ziyo98 przygotowałem na szybko .bin dla osób z BME280 SparkFun. Tylko dajcie znać czy działa, bo nie mam BME280 SparkFun i nie wiem czy działa używana przez nas bibliotek. SparkFun ma swoje i mogę je dodać, ale to trochę potrwa. Jeśli będzie ok, to dodam ten .bin do releases.

https://www.dropbox.com/s/x64tdjx8b40rq9w/Smogomierz_2.4.6_PMS-SparkFunBME280_build_13.05_18.12.2018.bin

jozwikp, 2018-12-18:
404
Tego pliku już tu nie ma

bfaliszek, 2018-12-18:
@jozwikp sorry złego linka wkleiłem. Ten jest poprawny: https://www.dropbox.com/s/12xe23mcz3t5ukp/Smogomierz_2.4.6_PMS-SparkFunBME280_build_13.05_18.12.2018.bin

jozwikp, 2018-12-18:
działa.

bfaliszek, 2018-12-18:
Dodałem ten .bin z obsługą BME280 SparkFun do plików w releases: https://github.com/hackerspace-silesia/Smogomierz/releases

ziyo98, 2018-12-18:
@bfaliszek  - własnie wróciłem z pracy i miałem zabrać się za modyfikację kodu - a tu niespodzianka od Ciebie.  Wielkie dzięki , u mnie też działa.

Closed 2018-12-17.

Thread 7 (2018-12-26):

Stabilność sprzętu - zawieszony smogomierz

jozwikp, 2018-12-26:
Cześć

Zauważyłem problem ze smogomierzem. Zawiesza się. Rzadko udaje mi się utrzymać go więcej niż dobę w działaniu. Czy ktoś spotkał podobne problemy? Może dobrze byłoby go softem restartować raz na jakiś czas?

ziyo98, 2018-12-26:
Hej,  miałem to samo - pomogła wymiana zasilacza na mocniejszy

bfaliszek, 2018-12-26:
@jozwikp Mam kilka mierników i w żadnym nie mam problemu z wieszaniem się. W jednym czasami przestaje na godzinę lub dwie działać bme280 i podejrzewam, że to kwestia zasilania. Jakich zasilaczy używasz?
BTW W oprogramowaniu jest systemowy reset ustawiony na 24 godziny ;)

jozwikp, 2018-12-27:
ja mam 5V - 2500mA - za mało?

bfaliszek, 2018-12-27:
2,5A na pewno wystarczy, na 500mA działa bez problemu. Co rozumiesz przez "Zawiesza się"? Nie działa interface www czy nie wysyła danych do zewnętrznych serwisów? Od ponad roku wysyłam pomiary do InfluxDB z kilku Smogomierzy i poza sporadycznymi zawieszeniami się BME280 reszta pomiarów działa bez problemów.
Możesz też spróbować podłączyć kabel usb bezpośrednio do ESP i włączyć w konfiguracji debug. W monitorze portu szeregowego powinny być komunikaty o każdym pomiarze i ewentualnych błędach.

jozwikp, 2018-12-27:
Nie działa endpoint /api i interfejs www
rusza po restarcie prądowym.

jozwikp, 2018-12-27:
Wersja oprogramowania: 2.4.7 build 13:05_18.12.2018

Closed 2019-03-29.

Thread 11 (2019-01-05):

Smogomierz nie prezentuje nic oprócz PM z BME280

opennas, 2019-01-05:

bfaliszek, 2019-01-05:
BME280 nie podaje PM, tylko temperaturę, wilgotność i ciśnienie. Jaki masz model BME280? Adafruit? SparkFun? Taki na fioletowej płytce? Jaka wersja oprogramowania dla Smogomierza?

opennas, 2019-01-05:
Chyba nie zauważyłem, że źle podłączyłem :(

GND z NodeMcu do CSB zamiast GND
3V z NodeMcu do SDO zamiast VCC

Mój pierwszy błąd!
Teraz już podłączyłem dobrze. Myślicie, że zjarałem już BME280 ?

Jeśli sądzicie, że żyje to jak uzyskać ciśnienie i wilgotność z CSB i SDO ?

bfaliszek, 2019-01-05:
Nie używasz CSB i SD0, bo Smogomierz używa I2C do połączenia z BME280 a nie SPI.

SLC podpinasz do D4, SDA do D3, VCC do 3V, a GND do G.

opennas, 2019-01-05:
Teraz mam tak
VCC - 3V
GND - G
SCL - D4
SDA - D3

niestety w "Pomiary" nie pokazuje nic poza PM1, PM2,5, PM10.
W konfiguracji jest włączony BME280 :(

BME280 padł myślisz i dlatego nic nie pokazuje z temperatury, ciśnienia i wilgotności ?

bfaliszek, 2019-01-05:
Sprawdź jeszcze adres BME280. Możesz to zrobić wybierając w ArduinoIDE Plik>Szkicownik>I2C_Scanner. Powinno być 0x76.

opennas, 2019-01-05:
W programie Arduino w ścieżce Plik>Szkicownik> nie pojawia mi się nic
Nie wiem co zrobić, aby tam było >I2C_Scanner :(

W monitorze portu szeregowego też podaje tylko 3 wartości PM.

bfaliszek, 2019-01-06:
To tutaj jest kod https://playground.arduino.cc/Main/I2cScanner Tylko zmień sobie ```Serial.begin(9600);``` na ```Serial.begin(115200);```. Jeśli wszystko masz dobrze podłączone to powinien wykryć połączenie I2C i wyświetlić adres w monitorze portu szeregowego. BME280 ma zazwyczaj adres 0x76 albo 0x77. W kodzie Smogomierza ustawiony jest 0x76. Jeśli masz 0x77 to nie będzie go widzieć.

opennas, 2019-01-26:
Przepraszam za zwłokę, ale dla pewności zamówiłem drugi komplet częsci, bo nie wiedziałem czy nie jest coś uszkodzone. Skorzystałem z kodu do sprawdzenia I2C, który powyżej zaproponowałeś. Zamieniłem szybkość zgodsnie z rekomendacją. Wynikiem jest dziwne zachowanie, bo skanowanie nie daje rezultatu pozytywnego.
Nie wiem co może być przyczyną tego problemu i proszę o pomoc, bo chwilowo wyczerpały mi się pomysły.

20:16:21.928 -> Scanning...
20:16:21.928 -> Unknown error at address 0x01
20:16:21.928 -> Unknown error at address 0x02
20:16:21.928 -> Unknown error at address 0x03
20:16:21.962 -> Unknown error at address 0x04
20:16:21.962 -> Unknown error at address 0x05
20:16:21.962 -> Unknown error at address 0x06
20:16:21.962 -> Unknown error at address 0x07
20:16:21.962 -> Unknown error at address 0x08
20:16:21.962 -> Unknown error at address 0x09
20:16:21.962 -> Unknown error at address 0x0A
20:16:21.962 -> Unknown error at address 0x0B
20:16:21.962 -> Unknown error at address 0x0C
20:16:21.962 -> Unknown error at address 0x0D
20:16:21.962 -> Unknown error at address 0x0E
20:16:21.962 -> Unknown error at address 0x0F
20:16:21.962 -> Unknown error at address 0x10
20:16:21.995 -> Unknown error at address 0x11
20:16:21.995 -> Unknown error at address 0x12
20:16:21.995 -> Unknown error at address 0x13
20:16:21.995 -> Unknown error at address 0x14
20:16:21.995 -> Unknown error at address 0x15
20:16:21.995 -> Unknown error at address 0x16
20:16:21.995 -> Unknown error at address 0x17
20:16:21.995 -> Unknown error at address 0x18
20:16:21.995 -> Unknown error at address 0x19
20:16:21.995 -> Unknown error at address 0x1A
20:16:21.995 -> Unknown error at address 0x1B
20:16:21.995 -> Unknown error at address 0x1C
20:16:22.029 -> Unknown error at address 0x1D
20:16:22.029 -> Unknown error at address 0x1E
20:16:22.029 -> Unknown error at address 0x1F
20:16:22.029 -> Unknown error at address 0x20
20:16:22.029 -> Unknown error at address 0x21
20:16:22.029 -> Unknown error at address 0x22
20:16:22.029 -> Unknown error at address 0x23
20:16:22.029 -> Unknown error at address 0x24
20:16:22.029 -> Unknown error at address 0x25
20:16:22.029 -> Unknown error at address 0x26
20:16:22.029 -> Unknown error at address 0x27
20:16:22.029 -> Unknown error at address 0x28
20:16:22.063 -> Unknown error at address 0x29
20:16:22.063 -> Unknown error at address 0x2A
20:16:22.063 -> Unknown error at address 0x2B
20:16:22.063 -> Unknown error at address 0x2C
20:16:22.063 -> Unknown error at address 0x2D
20:16:22.063 -> Unknown error at address 0x2E
20:16:22.063 -> Unknown error at address 0x2F
20:16:22.063 -> Unknown error at address 0x30
20:16:22.063 -> Unknown error at address 0x31
20:16:22.063 -> Unknown error at address 0x32
20:16:22.063 -> Unknown error at address 0x33
20:16:22.063 -> Unknown error at address 0x34
20:16:22.063 -> Unknown error at address 0x35
20:16:22.097 -> Unknown error at address 0x36
20:16:22.097 -> Unknown error at address 0x37
20:16:22.097 -> Unknown error at address 0x38
20:16:22.097 -> Unknown error at address 0x39
20:16:22.097 -> Unknown error at address 0x3A
20:16:22.097 -> Unknown error at address 0x3B
20:16:22.097 -> Unknown error at address 0x3C
20:16:22.097 -> Unknown error at address 0x3D
20:16:22.097 -> Unknown error at address 0x3E
20:16:22.097 -> Unknown error at address 0x3F
20:16:22.097 -> Unknown error at address 0x40
20:16:22.097 -> Unknown error at address 0x41
20:16:22.130 -> Unknown error at address 0x42
20:16:22.130 -> Unknown error at address 0x43
20:16:22.130 -> Unknown error at address 0x44
20:16:22.130 -> Unknown error at address 0x45
20:16:22.130 -> Unknown error at address 0x46
20:16:22.130 -> Unknown error at address 0x47
20:16:22.130 -> Unknown error at address 0x48
20:16:22.130 -> Unknown error at address 0x49
20:16:22.130 -> Unknown error at address 0x4A
20:16:22.130 -> Unknown error at address 0x4B
20:16:22.130 -> Unknown error at address 0x4C
20:16:22.130 -> Unknown error at address 0x4D
20:16:22.130 -> Unknown error at address 0x4E
20:16:22.130 -> Unknown error at address 0x4F
20:16:22.164 -> Unknown error at address 0x50
20:16:22.164 -> Unknown error at address 0x51
20:16:22.164 -> Unknown error at address 0x52
20:16:22.164 -> Unknown error at address 0x53
20:16:22.164 -> Unknown error at address 0x54
20:16:22.164 -> Unknown error at address 0x55
20:16:22.164 -> Unknown error at address 0x56
20:16:22.164 -> Unknown error at address 0x57
20:16:22.164 -> Unknown error at address 0x58
20:16:22.164 -> Unknown error at address 0x59
20:16:22.164 -> Unknown error at address 0x5A
20:16:22.164 -> Unknown error at address 0x5B
20:16:22.198 -> Unknown error at address 0x5C
20:16:22.198 -> Unknown error at address 0x5D
20:16:22.198 -> Unknown error at address 0x5E
20:16:22.198 -> Unknown error at address 0x5F
20:16:22.198 -> Unknown error at address 0x60
20:16:22.198 -> Unknown error at address 0x61
20:16:22.198 -> Unknown error at address 0x62
20:16:22.198 -> Unknown error at address 0x63
20:16:22.198 -> Unknown error at address 0x64
20:16:22.198 -> Unknown error at address 0x65
20:16:22.198 -> Unknown error at address 0x66
20:16:22.198 -> Unknown error at address 0x67
20:16:22.233 -> Unknown error at address 0x68
20:16:22.233 -> Unknown error at address 0x69
20:16:22.233 -> Unknown error at address 0x6A
20:16:22.233 -> Unknown error at address 0x6B
20:16:22.233 -> Unknown error at address 0x6C
20:16:22.233 -> Unknown error at address 0x6D
20:16:22.233 -> Unknown error at address 0x6E
20:16:22.233 -> Unknown error at address 0x6F
20:16:22.233 -> Unknown error at address 0x70
20:16:22.233 -> Unknown error at address 0x71
20:16:22.233 -> Unknown error at address 0x72
20:16:22.233 -> Unknown error at address 0x73
20:16:22.233 -> Unknown error at address 0x74
20:16:22.266 -> Unknown error at address 0x75
20:16:22.266 -> Unknown error at address 0x76
20:16:22.266 -> Unknown error at address 0x77
20:16:22.266 -> Unknown error at address 0x78
20:16:22.266 -> Unknown error at address 0x79
20:16:22.266 -> Unknown error at address 0x7A
20:16:22.266 -> Unknown error at address 0x7B
20:16:22.266 -> Unknown error at address 0x7C
20:16:22.266 -> Unknown error at address 0x7D
20:16:22.266 -> Unknown error at address 0x7E
20:16:22.266 -> No I2C devices found
20:16:22.266 ->

Marcin999, 2019-12-05:
Witam,
mam identyczny problem. Poniżej dane:
demos D1 mini
dystrybucja: ESP8266_Smogomierz_2.7.2_PMS-SparkFunBME280_build_4.10.2019.bin
VCC - 5V
GND - G
SCL - D4
SDA - D3
Mój czujnik działa na 5V. Sprawdzone na dystrybucji espeasy - działa bez problemu I2C.
Na rynku dwa rodzaje tych czujników 3V i 5V i podłączając go pod 3V na espeasy miałem te same błędy co opennas.
Niestety wyniki z BME280 nie są widoczne. Będę wdzięczny za wskazówki.

bfaliszek, 2019-12-05:
Wersja `ESP8266_Smogomierz_2.7.2_PMS-SparkFunBME280_build_4.10.2019.bin` różni się od `ESP8266_Smogomierz_2.7.2_PMS_build_4.10.2019.bin` innym adresem BME280 w I2C. Jeśli BME280 nie jest widoczne, to może sprawdź oprogramowanie bez `SparkFunBME280` w nazwie.

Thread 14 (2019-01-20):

Problem z BMP280

kuba-str, 2019-01-20:
cześć

mam problem z I2C.
Mam dwa czujniki takie jak:
http://prntscr.com/m9mqnc
oraz
http://prntscr.com/m9mqwh

Podłączam je prawidłowo. Według instrukcji. Niestety nie są wykrywane. Wgrałem także szkic z https://playground.arduino.cc/Main/I2cScanner. Skaner nie wykrywa ani jednego, ani drugiego termometru.

Macie jakiś pomysł ?
wersja softu to: Smogomierz_2.4.9_PMS_build_19.05_3.01.2019.bin
Zmiana czujnika z BME na BMP w sofcie nic nie daje.

bfaliszek, 2019-01-20:
Jeśli nie wykrywa ich I2cScanner, to muszą być źle podłączone. Spróbuj odwrotnie podłączyć SCL i SDA.

kuba-str, 2019-01-20:
Na NodeMCU też wykrywa, pokazuje mu 0x76. Jednak musiałem zmienić piny 12 i 14. Na 0 i 2 nie czytało w skanerze. Jednak nadal nie podaje wartości, w debugu pokazuje brak danych.

bfaliszek, 2019-01-20:
Sprawdzę to jutro wieczorem, bo mam gdzieś BMP280 i dam znać.

bfaliszek, 2019-01-21:
Głównie BME280 i jednego SHT1x. BMP280 ma raczej tutaj średnie zastosowanie, bo nie mierzy wilgotności powietrza, która jest potrzeba do automatycznej kalibracji pomiarów PM2.5 oraz PM10. Przy zastosowaniu BMP280 pomiary PM będą bez kalibracji i mogą być zawyżone.

kuba-str, 2019-01-21:
mam i taki i taki, jednak wykrywane są tylko pod pinami 12 i 14, nie podają natomiast pomiarów. Czekam na efekt sprawdzania.

bfaliszek, 2019-01-21:
OK, faktycznie BMP280 nie działa. Przy kolejnej aktualizacji oprogramowania postaram się to naprawić.

kuba-str, 2019-01-21:
szukałem, szukałem aż w końcu znalazłem. Skaner pokazywał że czujnik działa na I2C i jego port 0x76. Szukałem dalej, szukałem problemu w bibliotece. Znalazłem kod https://github.com/finitespace/BME280/blob/master/examples/BME_280_I2C_Test/BME_280_I2C_Test.ino. Oparty jest na innej bibliotece i po wgraniu ukazała się wartość wilgotności, ciśnienia i temperatury. Czy można tą bibliotekę włączyć do smogomierza ?

kuba-str, 2019-01-21:
dobra, już wszystko wiem. Testowałem, testowałem aż doszedłem do tego że w tych płytkach NODEMCU i wemos I2C działa tylko na portach D1 i D2. Co za tym idzie, na żadnym innym nie będzie działać. Teraz, wystarczyło zamienić miejscami piny na których działa czujnik smogu i BME280.  Czujnik smogu na 0,2 a I2C na 5 i 4. Teraz elegancko działa. http://prntscr.com/maaj4f

Closed 2019-01-22.

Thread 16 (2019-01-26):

Smogomierz nie podaje danych z BME280 cd.

opennas, 2019-01-26:
Mam czujnik BME280 wilgotności temperatury oraz ciśnienia i podłączony mam 4 kabelkami z wykorzystaniem SCL i SDA.

Zgodnie z rekomendacją wdo sprawdzenia adresu BME280 wykorzystałem kod https://playground.arduino.cc/Main/I2cScanner i zmieniłem Serial.begin(9600); na Serial.begin(115200);

Zmieniłem na nowy zarówno kontroler NodeMCU v3 + moduł WiFi ESP8266 jak i również czujnik BME280. Wszystko połączone jest zgodnie ze schematem i opisem.

Nie wiem co może być przyczyną tego problemu i proszę o pomoc, bo chwilowo wyczerpały mi się pomysły.

20:16:21.928 -> Scanning...
20:16:21.928 -> Unknown error at address 0x01
20:16:21.928 -> Unknown error at address 0x02
20:16:21.928 -> Unknown error at address 0x03
20:16:21.962 -> Unknown error at address 0x04
20:16:21.962 -> Unknown error at address 0x05
20:16:21.962 -> Unknown error at address 0x06
20:16:21.962 -> Unknown error at address 0x07
20:16:21.962 -> Unknown error at address 0x08
20:16:21.962 -> Unknown error at address 0x09
20:16:21.962 -> Unknown error at address 0x0A
20:16:21.962 -> Unknown error at address 0x0B
20:16:21.962 -> Unknown error at address 0x0C
20:16:21.962 -> Unknown error at address 0x0D
20:16:21.962 -> Unknown error at address 0x0E
20:16:21.962 -> Unknown error at address 0x0F
20:16:21.962 -> Unknown error at address 0x10
20:16:21.995 -> Unknown error at address 0x11
20:16:21.995 -> Unknown error at address 0x12
20:16:21.995 -> Unknown error at address 0x13
20:16:21.995 -> Unknown error at address 0x14
20:16:21.995 -> Unknown error at address 0x15
20:16:21.995 -> Unknown error at address 0x16
20:16:21.995 -> Unknown error at address 0x17
20:16:21.995 -> Unknown error at address 0x18
20:16:21.995 -> Unknown error at address 0x19
20:16:21.995 -> Unknown error at address 0x1A
20:16:21.995 -> Unknown error at address 0x1B
20:16:21.995 -> Unknown error at address 0x1C
20:16:22.029 -> Unknown error at address 0x1D
20:16:22.029 -> Unknown error at address 0x1E
20:16:22.029 -> Unknown error at address 0x1F
20:16:22.029 -> Unknown error at address 0x20
20:16:22.029 -> Unknown error at address 0x21
20:16:22.029 -> Unknown error at address 0x22
20:16:22.029 -> Unknown error at address 0x23
20:16:22.029 -> Unknown error at address 0x24
20:16:22.029 -> Unknown error at address 0x25
20:16:22.029 -> Unknown error at address 0x26
20:16:22.029 -> Unknown error at address 0x27
20:16:22.029 -> Unknown error at address 0x28
20:16:22.063 -> Unknown error at address 0x29
20:16:22.063 -> Unknown error at address 0x2A
20:16:22.063 -> Unknown error at address 0x2B
20:16:22.063 -> Unknown error at address 0x2C
20:16:22.063 -> Unknown error at address 0x2D
20:16:22.063 -> Unknown error at address 0x2E
20:16:22.063 -> Unknown error at address 0x2F
20:16:22.063 -> Unknown error at address 0x30
20:16:22.063 -> Unknown error at address 0x31
20:16:22.063 -> Unknown error at address 0x32
20:16:22.063 -> Unknown error at address 0x33
20:16:22.063 -> Unknown error at address 0x34
20:16:22.063 -> Unknown error at address 0x35
20:16:22.097 -> Unknown error at address 0x36
20:16:22.097 -> Unknown error at address 0x37
20:16:22.097 -> Unknown error at address 0x38
20:16:22.097 -> Unknown error at address 0x39
20:16:22.097 -> Unknown error at address 0x3A
20:16:22.097 -> Unknown error at address 0x3B
20:16:22.097 -> Unknown error at address 0x3C
20:16:22.097 -> Unknown error at address 0x3D
20:16:22.097 -> Unknown error at address 0x3E
20:16:22.097 -> Unknown error at address 0x3F
20:16:22.097 -> Unknown error at address 0x40
20:16:22.097 -> Unknown error at address 0x41
20:16:22.130 -> Unknown error at address 0x42
20:16:22.130 -> Unknown error at address 0x43
20:16:22.130 -> Unknown error at address 0x44
20:16:22.130 -> Unknown error at address 0x45
20:16:22.130 -> Unknown error at address 0x46
20:16:22.130 -> Unknown error at address 0x47
20:16:22.130 -> Unknown error at address 0x48
20:16:22.130 -> Unknown error at address 0x49
20:16:22.130 -> Unknown error at address 0x4A
20:16:22.130 -> Unknown error at address 0x4B
20:16:22.130 -> Unknown error at address 0x4C
20:16:22.130 -> Unknown error at address 0x4D
20:16:22.130 -> Unknown error at address 0x4E
20:16:22.130 -> Unknown error at address 0x4F
20:16:22.164 -> Unknown error at address 0x50
20:16:22.164 -> Unknown error at address 0x51
20:16:22.164 -> Unknown error at address 0x52
20:16:22.164 -> Unknown error at address 0x53
20:16:22.164 -> Unknown error at address 0x54
20:16:22.164 -> Unknown error at address 0x55
20:16:22.164 -> Unknown error at address 0x56
20:16:22.164 -> Unknown error at address 0x57
20:16:22.164 -> Unknown error at address 0x58
20:16:22.164 -> Unknown error at address 0x59
20:16:22.164 -> Unknown error at address 0x5A
20:16:22.164 -> Unknown error at address 0x5B
20:16:22.198 -> Unknown error at address 0x5C
20:16:22.198 -> Unknown error at address 0x5D
20:16:22.198 -> Unknown error at address 0x5E
20:16:22.198 -> Unknown error at address 0x5F
20:16:22.198 -> Unknown error at address 0x60
20:16:22.198 -> Unknown error at address 0x61
20:16:22.198 -> Unknown error at address 0x62
20:16:22.198 -> Unknown error at address 0x63
20:16:22.198 -> Unknown error at address 0x64
20:16:22.198 -> Unknown error at address 0x65
20:16:22.198 -> Unknown error at address 0x66
20:16:22.198 -> Unknown error at address 0x67
20:16:22.233 -> Unknown error at address 0x68
20:16:22.233 -> Unknown error at address 0x69
20:16:22.233 -> Unknown error at address 0x6A
20:16:22.233 -> Unknown error at address 0x6B
20:16:22.233 -> Unknown error at address 0x6C
20:16:22.233 -> Unknown error at address 0x6D
20:16:22.233 -> Unknown error at address 0x6E
20:16:22.233 -> Unknown error at address 0x6F
20:16:22.233 -> Unknown error at address 0x70
20:16:22.233 -> Unknown error at address 0x71
20:16:22.233 -> Unknown error at address 0x72
20:16:22.233 -> Unknown error at address 0x73
20:16:22.233 -> Unknown error at address 0x74
20:16:22.266 -> Unknown error at address 0x75
20:16:22.266 -> Unknown error at address 0x76
20:16:22.266 -> Unknown error at address 0x77
20:16:22.266 -> Unknown error at address 0x78
20:16:22.266 -> Unknown error at address 0x79
20:16:22.266 -> Unknown error at address 0x7A
20:16:22.266 -> Unknown error at address 0x7B
20:16:22.266 -> Unknown error at address 0x7C
20:16:22.266 -> Unknown error at address 0x7D
20:16:22.266 -> Unknown error at address 0x7E
20:16:22.266 -> No I2C devices found
20:16:22.266 ->

bfaliszek, 2019-01-27:
Wygląda jakby BME280 było uszkodzone

firemark, 2019-01-27:
Pytanie durne - czy dobrze podłączyłeś zasilanie? :)

bfaliszek, 2019-01-29:
a sprawdź na D1 i D2? Jeśli samemu kompilujesz kod w ArduinoIDE to daj znać też jaką masz wersję ESP8266core najnowsza to 2.5.0 beta 3 i w tych betach może coś nie działać(np. SoftwareSerial).

opennas, 2019-02-02:
Po odłączeniu D1 i D2 z projektu Smogomierz i podłączeniu BME280

VCC - 3V
GND - G
SCL - D2
SDA - D1

nie wykrywał nic.

```
22:30:30.391 -> Scanning...
22:30:30.425 -> No I2C devices found
22:30:30.425 ->
22:30:35.402 -> Scanning...
22:30:35.435 -> No I2C devices found
22:30:35.435 ->
```

ESP8266 mam teraz w wersji 2.4.2.

bfaliszek, 2019-02-03:
To jeszcze ostatnie pytanie. Na pewno masz wybraną płytkę NodeMCU 1.0? To chyba jeszcze ostatnia opcja jaka została. Jeśli tak, to chyba masz po prostu wadliwe BME280, które nie działa.

opennas, 2019-02-03:
Włączona opcja NodeMCU 1.0 (ESP-12E Module) i dwa czujniki BME280. Jeszcze mam trzeci, ale muszę wlutować piny.
Mam dwa pełne zestawy Smogomierza i testowałęm na dwóch płytkach NodeMCU.

Zauważyłem teraz po zmianach, że mam w trakcie kompilacji błędy dotyczące biblioteki Wire.
Nie mogę ich skopiować i proaszę o pomoc jak skopiować błędy z kompilacji.
Mam kompilacja zakończona, ale były błedy Wire.
Pewnie to pomoże ustalić przyczyny ...

opennas, 2019-02-09:
Jeszcze dwie kwestie do upewnienia się:

1. Kabel USB mam podłączony do komputera z jednej a do NodeMCU z drugiej.
Po zaprogramowaniu mogę oglądać monitor portu szeregowego, ale nie mam podłączonego zasilania Smogomierza w dedykowanym konektorze. Może muszę dodatkowo podłączyć zasilania i wtedy dopiero pojawi się zasilanie i będzie działać I2C?

2. Po przeprogramowaniu straciłem urządzenie na WiFi i pomimo ponownego programowanie nie generuje sie sieć Smogomierz..
Jak zresetować WiFi w smogomierzu, abym po zaprogramowaniu mógł zmienić jemu sieć WiFi

3 Czy może lepiej jest ustawićdomyślną sieć w kodzie i podać nazwę SSID oraz hasło do przyłaczenia sieci jako default

bfaliszek, 2019-02-09:
> masz po prostu wadliwe BME280, które nie działa.
🤷🏻‍♂️

opennas, 2019-02-09:
Próbowałem już dwa BME280. Dzisiaj doszła trzecia sztuka BM280. Zaraz ją przygotuje i podłączę.

opennas, 2019-02-09:
Teraz podłączyłem 3 sztukę BME280 i to samo :(
Zakupiłem w Botland i teraz po sprawdzeniu 3 sztuju pozostaje mi nic innego jak napisać reklamacje.
Mało prawdopodobne, aby w trzech wysyłkach tylko BME280 było 3X wadliwe.

opennas, 2019-02-09:
Sukces, po resecie NodeMCU oraz ustawieniu SSDI na sztywno.
Zadziałał BME280.

Ciągle zastanawiam się co było przyczyną tego.

{
  "device_name": "Smogomierz-C68890",
  "pm1": 19,
  "pm25": 31,
  "pm10": 37,
  "temperature": 23.3,
  "pressure": 1022,
  "humidity": 25,
  "dewpoint": 8.306054
}

Closed 2019-02-26.

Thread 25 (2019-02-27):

Wsparcie dla czujnika BME680

wiuwiu, 2019-02-27:
Z ciekawych rzeczy fajnie by było mieć obsługę MQTT w Smogomierzu by móc przesyłać dane bezpośrednio do lokalnego systemu inteligentnego domu.
Kolejną ciekawą rzeczą jest obsługa czujnika BME680 z pomiarem VOC / gazów. Bosh udostępnia firmware dla ESP8266 do obliczania indeksu jakości powietrza IAQ. Link: [https://botland.com.pl/pl/czujniki-gazow/10872-adafruit-bme680-czujnik-temperatury-wilgotnosci-cisnienia-i-gazu.html](url)

bfaliszek, 2019-02-27:
Zakładam, że Smogomierze są umieszczane raczej na zewnątrz, więc pomiar IAQ (Indoor air quality), plus to co podaje BME680 to nie jest wartość VOC, tylko rezystancja wszystkich gazów. Myślałem o dodaniu CCS811, który podaje właśnie VOC i CO2, ale on nie podaje wartości absolutnych i każdy z nich wymaga kalibracji, więc raczej za dużo z tym zachodu. Chciałbym dodać coś do pomiaru NO2 ale większość mierników nie radzi sobie z niskimi wartościami, a te które podają wartość od 0, kosztują majątek.

wiuwiu, 2019-02-27:
Wzięte z opisu czujnika:

> Czujnik BME680 zawiera mały czujnik MOX. Ogrzewany tlenek metalu zmienia rezystancje w oparciu o lotne związki organiczne (VOC) znajdujące się w powietrzu, dzięki czemu może wykrywać gazy i alkohole, takie jak etanol, alkohol i tlenek węgla. Może być także wykorzystywany do wykonywania pomiarów czystości powietrza.

>
W przypadku CCS811 można by oprzeć się nie tyle na samych wartościach co na ich zmianie. Wówczas kalibracja nie byłaby potrzeba a każdy by widział, że jeżeli wartości nagle strzelają w górę to "wiedz, że coś się dzieje" :)

bfaliszek, 2019-03-23:
W 2.6.0 dodałem wstępnie wsparcie dla MQTT, tylko nie miałem za bardzo jak przetestować, więc będę wdzięczny na info czy działa – https://github.com/hackerspace-silesia/Smogomierz/tree/2.6.0

mientki, 2019-03-24:
Wygląda na to że coś tam się pojawia w brokerze...

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
 Możnaby ewentualnie dodać w składni topiców nazwę urządzenia, np. tak:

Smogomierz-8421EF/sensor/temperature

gdzie "Smogomierz-8421EF" to nazwa urządzenia. Przy dwóch smogomierzach na tym samym brokerze MQTT jest konflikt, a wyniki nadpisują się pod takim samym topikiem.

bfaliszek, 2019-03-24:
@mientki dzięki za info. Dodam to w kolejnej aktualizacji.

bfaliszek, 2019-03-29:
Jest już 2.6.2 - https://github.com/hackerspace-silesia/Smogomierz/releases/tag/v2.6.2 poprawiłem m.in. tam wsparcie dla MQTT

mientki, 2019-04-07:
Mam 2 smogomierze w sieci:
1) Nazwa urządzenia: Smogomierz-8421EF
2) Nazwa urządzenia: Smogomierz-0A5017

Na brokerze MQTT pojawiają zupełnie inne nazwy:

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

Z czego to może wynikać?

bfaliszek, 2019-04-07:
Nazwa urządzenie jest trochę inaczej generowane. To co jest w brokerze to ten sam ChipID, który jest podany na stronie Konfiguracji przy opcji włączenia luftdaten.

mientki, 2019-04-07:
A jak jest generowany? Możnaby to ujednolicić.

Closed 2021-11-16.

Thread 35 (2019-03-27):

changing chipID may cause collision with other sensors on Luftdaten.info

ricki-z, 2019-03-27:
At the moment Luftdaten.info doesn't accept regsitrations for devices with this firmware.
The possibility to change the chipID may lead to collisions with other sensors (not only for Luftdaten.info).
Please contact me for more infos (we had a collsion with the third registration of such a device).
You could change the device prefix in "X-Sensor" (src/luftdaten.cpp) from esp8266 to smogomierz . Users then need to send "smogomierz-"+chipID as the chipID at registration. So collisions may only affect users of this firmware.

bfaliszek, 2019-03-27:
thanks for the information. I will correct the code as suggested. I will change the X-Sensor to a smogomierz

bfaliszek, 2019-03-27:
1) Removed change ChipID option: https://github.com/hackerspace-silesia/Smogomierz/commit/173f307d755490a2c5fe84594a6c6be9225e7a8c
2) Added "smogomierz" to X-Sensor: https://github.com/hackerspace-silesia/Smogomierz/commit/838135d37aec250721df52e6304eeee744c49d56

ricki-z, 2019-03-27:
could you please also add the prefix to the config page so that user will see what "chipID" they have to use for registration?

bfaliszek, 2019-03-27:
Yes. I also added it to the configuration page https://github.com/hackerspace-silesia/Smogomierz/commit/173f307d755490a2c5fe84594a6c6be9225e7a8c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

ricki-z, 2019-03-27:
Then I can close this issue.

Closed 2019-03-27.

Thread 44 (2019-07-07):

Niepoprawny build z kodów źródłowych

p-jac, 2019-07-07:
Na początek dziękuję hackerspace-silesia i @bfaliszek - świetny projekt, zmontowałem Wasz smogomierz kilka miesięcy temu i sprawdza się świetnie!

Próbuję go odrobinę wzbogacić (używam smogomierza w mieszkaniu i chcę dołożyć mu czujnik CCS811, LCD 2x16 + pasek 8 LEDów) i mam kłopot z właściwym zbudowaniem pliku .bin.

Działam na wersji 2.7.0 i z gotowym plikiem .bin ściągniętym z gita działa dobrze. Jestem w stanie również skompilować tę wersję u siebie w Arduino i wgrać na płytkę - ale niestety tak przygotowana wersja nie działa (pomimo braku jakichkolweik zmian w kodzie) - sypie się coś przy starcie, bo dioda NodeMCU nie świeci, ewentualnie mruga niemrawo. Taki stan mam zarówno po wgrywce skompilowanego przeze mnie pliku .bin flasherem, jak i bezpośrednio z Arduino.

Po wgraniu oryginalnego pliku .bin z gita, działa dobrze. Binarnie wersje te są różne (.bin z gita ma 497 968 B, a skompilowany u mnie 504 416 B).

Coś mam pewnie nie tak z Arduino, ale nie mogę tego namierzyć. Jedyne co przychodzi mi do głowy to niewłaściwa wersja jakiejś biblioteki - wszystko ściągałem w czerwcu, więc są świeże, ale może właśnie któraś potrzebna jest "nieświeża"? Możecie podrzucić numery wersji bibliotek wykorzystywane przez Was do kompilacji? Ewentualnie inne pomysły, co może być nie tak...

Z góry dzięki za pomoc - jak się uda i moje dodatko zadziałają, dorzucę na gita propozycję kodu do obsługi czujnika CCS811, LCD i LEDów - może komuś jeszcze się przyda :-)

PS Moja konfiguracja: Arduino 1.8.9 na Windows 10, ustawiona płytka ESP-12E, prędkość 115200, CPU 80Mhz, pamięć 4 MB (1 MB SPIFFS), wszystkie debugowania wyłączone. Każdorazowo czyszczę tylko sketch z flasha, żeby nie tracić ustawień. Ustawień Arduino nie ruszałem poza płytką, pamięcią i ściągnięciem bibliotek. Jestem początkujący jeśli chodzi o NodeMCU i szerzej mikrokontrolery, więc może chodzić o jakąś drobnostkę.

bfaliszek, 2019-07-08:
Sprawdź jaką masz wersję biblioteki do obsługi płytek esp8266? Najnowsza to 2.5.2 i na niej się raczej nie skompiluje, bo zmienili coś w obsłudze SPIFFS. Dostępne .bin są skompilowane na 2.5.0 i tam powinno być ok. Jak znajdę trochę wolnego czasu na poprawię kod, żeby działał na 2.5.2.

bfaliszek, 2019-07-08:
Co do CCS811 to w sumie ostatnio trochę z nimi eksperymentuję i w sumie to mogę dodać obsługę, tylko wychodzę raczej z założenie, że Smogomierz to urządzenie, które umieszcza się na zewnątrz, więc pomiary eCO2 i TVOC raczej nie mają sensu. Plus z CCS811 mam problem z ustawieniem baseline, teoretycznie zapisuję po 30 minutach na świeżym powietrzu ustawienia i przywracam je później, a wyniki i tak są zupełnie inne niż z MH-Z19.

p-jac, 2019-07-08:
Dzięki! Na bibliotece płytki 2.5.0 wgrywa się i śmiga bez zarzutu.
Jeśli możesz podrzucić swój kod z CCS811, chętnie potestuję. Mam na razie bardzo wstępną wersję, która tylko wystawia wyniki do bazy influx. Udało mi się to odpalić, ale patrząc na wykres czujnik chyba jeszcze się wygrzewa... rozrzuty pomiarów o setki punktów w odstępie kilku minut.

bfaliszek, 2019-07-10:
CCS811 powinien się nagrzewać jakieś 25 minut i później ma sensowne pomiary.
Jeśli chodzi o kod, to używałem tej biblioteki https://github.com/maarten-pennings/CCS811

p-jac, 2019-07-11:
No cóż, u mnie po 48-godzinnym burn in CCS811 daje jeszcze bardziej rozedrgane wyniki. Potestuję jeszcze, ale nie wygląda, żeby miał pokazywać coś sensownego (załączam zrzuty gdyby Cię zainteresowały - spadek rano nie daje się powiązać z niczym, czujnik stał 2 metry od uchylonego okna, sądzę że powinien pokazywać w miarę stabilne czyste powietrze...). Używam oryginalnej biblioteki Sparkfun (https://github.com/sparkfun/CCS811_Air_Quality_Breakout), taką mam płytkę.
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

Za to wyświetlacz LCD 2x16 działa dobrze i pasek LEDowy też (pozytywne zaskoczenie, bo zasilam go z linii 3,3V - poniżej specyfikacji). Wszystko (choć nie bez kłopotów z wykorzystaniem pinu D8) udało mi się podpiąć pod NodeMCU. Wrzucę kod jak go trochę posprzątam, może komuś się przyda.

bfaliszek, 2019-08-23:
Hej, w końcu znalazłem chwilę, żeby poprawić kilka rzeczy w kodzie i już mi się kompiluje na esp8266 core 2.5.2, kod jest na razie w branchu dev - https://github.com/hackerspace-silesia/Smogomierz/tree/dev
Wersja 2.7.1 nie wnosi żadnych nowości, po prostu kompiluje się i powinna działać na najnowszych bibliotekach.

bfaliszek, 2019-08-30:
Właśnie udostępniłem poprawiony kod - 2.7.1. Teraz już się kompiluje na najnowszych bibliotekach dla ESP8266 oraz ESP32 ;)

Closed 2019-08-30.

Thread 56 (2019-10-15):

Pomiar napięcia zasilania Smogomierza

porebskitomasz, 2019-10-15:
Witam.
Zmajstrowałem Smgomierza zgodnie z opisem.
Wszystko działa wyśmienicie.
Ja swoją wersję zasilam niezależnie z ogniw 3x18650 o łącznej pojemności około 8000mAh.  Jednocześnie wykorzystałem do doładowania ich dwa niewielkie panele fotowolaticzne o napięciu do 6V- niestety nie potrafię określić ich mocy.
Moje pytanie/propozycja brzmi: Czy byłaby możliwość dopisania funkcji pomiaru napięcia akumulatorów, i wysyłania na przykład do serwisów np http://thingspeak.com, lub żeby było widoczne na głównej stronie z pomiarami Smogomierza?
Tomek

turonl, 2019-10-22:
Hej,
  Czy masz tam jakiś stabilizator czy po prostu podłączasz te ogniwa do 5v ESP8266?
Z odpowiednim dzielnikiem powinno się dać użyć wejścia ADC Esp8266 - trochę rozbieżne są tylko opisy co do zakresu napiec tego ADC i obecności tegoż dzielnika na płytce ESP.
Tu przykład : https://www.engineersgarage.com/esp8266/nodemcu-battery-voltage-monitor/
Pytanie czy jest potrzeba dodać do Smogomierza coś takiego na stale (jako opcja)...

Riventros, 2020-01-25:
Hej,
Na jak długo starcza zasilania? Ogniwa zmieściły się w zalecanej obudowie? Czy twój układ pracuje na zewnątrz?

Pozdrawiam.

m-dudzinski, 2020-02-17:
Cześć, ja też jestem już po budowie własnego egzemplarza, wszystko śmiga aż miło :) Zamówiłem też sobie akumulatorki 18650 razem z modułem ładowania ([link](http://pl.aliexpress.com/item/32966489898.html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,searchweb201602_,searchweb201603_)), żeby móc zamontować urządzenie na zewnątrz bez konieczności podciągania do niego kabla.

Czy jest możliwość aby te dane były wysyłane tak jak pomiary np PM2.5 do serwisów (ja używam thingspeak)? Jak podejść do tego tematu?

Closed 2021-11-16.

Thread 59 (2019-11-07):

Zawieszanie SDS011

skwaruch, 2019-11-07:
Coś nie ma szczęścia do czujników PMS7003 nie wyłącza się softwear'owo a SDS011 wiesza mi się średnio co dzień (smogomierz pokasuje ciągle tą samą wartość). Ponowne uruchomienie czujnika pomaga.

bfaliszek, 2019-11-07:
Oprogramowanie 2.7.2 i ESP8266?

skwaruch, 2019-11-07:
Tak

piotrrekkk, 2020-02-07:
Jakaś aktualizacja odnośnie tego buga? Też się z nim spotkałem.

Kriztower, 2020-02-07:
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
U mnie podobnie. Wiesza się minimum codziennie, jak nie kilka razy dziennie. Po restarcie kilka godzin spokoju i znowu.

slawek0200, 2020-02-07:
Ja również potwierdzam, restart co kilka godzin. SDS011 się zawiesza.

theundefined, 2020-02-08:
U mnie na wemos d1 + sds11 +dht22 działa stabilnie. 2.7.2.
Jedno co to mam wrażenie że zaniża wielkości pomiarów - trend jest zgodny z tym co okoliczne czujniki syngeos i looko2, ale wielkosci niższe.

slawek0200, 2020-02-09:
U mnie płytka CH340 NodeMcu V3, +SDS011 +BME280 są problemy z zawieszaniem. Wymienię na  płytkę WEMOS D1 i sprawdzę.

bfaliszek, 2020-02-09:
> U mnie na wemos d1 + sds11 +dht22 działa stabilnie. 2.7.2.
> Jedno co to mam wrażenie że zaniża wielkości pomiarów - trend jest zgodny z tym co okoliczne czujniki syngeos i looko2, ale wielkosci niższe.

Ogólnie looko2 używa mierników PMS5003. Najbardziej zauważalna różnica pomiędzy PMS a SDS to różnica w wykrywaniu poziomu zanieczyszczeń przy ich niskim poziomie. SDS lepiej wykrywa poziomy do około 15ug/m3. PMSy zazwyczaj pokazują 0-2, 5 albo od razu 10ug/m3. SDS jest po prostu bardziej czuły przy niskich stężeniach pyłu. To może być powodem rozbieżności. Plus dht22 często podaje wilgotność z czapy, więc może też wpływać na pomiary PM, jeśli masz włączoną kalibrację w ustawieniach.

bfaliszek, 2020-02-09:
> U mnie płytka CH340 NodeMcu V3, +SDS011 +BME280 są problemy z zawieszaniem. Wymienię na płytkę WEMOS D1 i sprawdzę.

Wydaje mi się, że zmiana z NodeMcu na Wemosa nie powinna mieć żadnego wpływu. Sprawdzę w wolnej chwili jak całość działa z SDSem. Możliwe, że jest jakiś błąd w bibliotece do obsługi SDSów, bo ten błąd nie występuje w innych wersjach oprogramowania, a one różnią się tylko obsługiwanymi miernikami pyłu.

Kriztower, 2020-02-09:
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

Jeszcze się u mnie na zewnątrz nie zdąży o żeby czujnik (sds011) pokazał <10 😀

Kriztower, 2020-02-10:
Niestety znowu to samo😭
Widać dwa zawieszenia, a po restarcie znowu mierzy przez kilka godzin i znowu zawias.
A ciekawe że temperaturę i wilgotność pokazuje dobrze cały czas.
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

skwaruch, 2020-02-10:
Nic w tym ciekawego że jest temp. bo zawiesza się SDS011, który temp. nie mierzy.

theundefined, 2020-02-10:
Może inny zasilacz?

Kriztower, 2020-02-10:
> Może inny zasilacz?

Chodzi bezpośrednio z płytki.

> Nic w tym ciekawego że jest temp. bo zawiesza się SDS011, który temp. nie mierzy.

No tak tylko dlaczego? Wina czujnika? Przecież po restarcie działa ok.

theundefined, 2020-02-10:
Może zwiesza się SDS przy problemach z zasilaniem? Strzelam. Jak nie masz jak zmienić SDS spróbuj jakiś mocniejszy zasilacz użyć :-)

bfaliszek, 2020-02-11:
@Kriztower tutaj opcje są dwie, a w zasadzie to trzy. Dane o temperaturze są wysyłane, więc urządzenia działa. Pomiary temperaturze są dobrze wykonywane, więc jedyne co nie działa to wykonywanie pomiarów przez SDS. Stąd trzy opcje:

+ biblioteka do obsługi SDS ma jakieś błędy i co jakiś czas nie działa

+ trzeba wymienić kabelki do SDS, bo nie można się z nim czasami połączyć

+ jest problem z zasilaniem, lub sam SDS jest wadliwy

skwaruch, 2020-02-12:
Zmieniłem wczoraj zasilacz na mocniejszy i o ciut większym na napięciu (5,12V wcześniej 4,9..V).
Też się zawiesiło :( .

Kriztower, 2020-02-21:
U mnie cały czas się zawiesza. Raz chodzi pół dnia raz półtora dnia, ale zawsze się zawiesi. Czy dałoby radę dopisać linijkę żeby np. co 10 min nastąpił restart samego czujnika, poprzez odłączenie do niego zasilania?

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

MiG-41, 2020-12-19:
U mnie jeszcze inna reakcja , na wsadzie ESP8266_Smogomierz_2.7.2_SDS011_build_4.10.2019.bin działał 5 dni i było ok , zaktualizowałem automatycznie do najnowszej 2.7.9 SDS i wtedy zaczęły się zawieszania czytnika. Zwykły restart nie wystarczał , trzeba było odłączać na chwilę zasilanie.
Teraz wgrałem ESP8266_Smogomierz_2.7.3_SDS011_build_17.01.2020.bin , na razie od 12godzin jest ok ( choć tu mam wielkie problemy z ustawieniem konfiga , uruchamiam jedno , i przestawia się do defaultowych ustawien , czasami cos przestawie , a np jezyk sie cofa na angielski..)

Closed 2021-11-16.

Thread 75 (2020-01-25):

Praca na zewnątrz i zasilanie z 18650

Riventros, 2020-01-25:
Witam!

Czy smogomierz byłby w stanie bezpiecznie pracować na zewnątrz? Obudowa ma IP67, chyba wywietrzniki byłby problemem? Gdyby w miejscu samego mUSB zastosować moduł ładowarki ogniw, a za ogniwem przetwornice step-up na 5V to miałoby to rację bytu? Jak wygląda pobór prądu całego układu. Czy można by zoptymalizować kod pod kątem energooszczędności np. pomiar co 15 minut, i tryb czuwania?

Pozdrawiam

bfaliszek, 2020-01-25:
Można włączyć w ustawieniach Deepsleep i wybudzanie urządzenia co kilka-kilkanaście minut.
Jeśli chodzi o obudowę to bez problemu urządzenie może działać na zewnątrz. Sam 5 Smogomierzy, każdy jest w takiej obudowie i jest zasilany przez USB. Najstarszy działa od 3 lat. Wszystkie są na zewnątrz.

Riventros, 2020-01-25:
Jak wygląda zasilanie z USB na zewnątrz?

bfaliszek, 2020-01-25:
No normalnie, mam podłączony kabel do Smogomierza. Chyba nie za bardzo rozumiem o co pytasz.

Riventros, 2020-01-25:
Ale jak pociągnięty jest kabel na zewnątrz?

bfaliszek, 2020-01-25:
najczęściej przekładam go przez okno i zamykam. Da się tak zamknąć okno bez problemu, a kabel nadal działa. Najczęściej tak przerzucam kable USB na zewnątrz.

Riventros, 2020-01-25:
A czy obudowa jest wystawiona na działanie np. deszczu?

bfaliszek, 2020-01-25:
Jasne. Jak już pisałem, przez 3 lata nie miałem problemów z obudową. Tak szczerze to najbardziej problematyczne są kabelki w środki. Czasami trzeba je wymienić po roku, a czasami działają trzy bez problemów

Riventros, 2020-01-26:
A z doświadczenia, który czujnik najlepiej zastosować?

ookris, 2020-01-26:
> Ale jak pociągnięty jest kabel na zewnątrz?

Tak jak pisał Błażej kabel zwyczajnie można "przyciąć" oknem. Polecam do tego kable typu "flat", które bez problemu można tak robić.

https://www.trust.com/en/product/20135-flat-micro-usb-cable-1m-black

bfaliszek, 2020-01-26:
Jeśli chodzi o czujnik to polecam Sensirion SPS30 i do tego ESP32. No i BME280 do pomiarów temperatury, wilgotności i ciśnienia.

Kriztower, 2020-02-07:
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
U mnie tak to wygląda.

jankes46, 2020-11-30:
czy jest jakaś możliwość dołożenia panelu słonecznego ?

Closed 2021-11-16.

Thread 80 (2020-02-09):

Informacja przez LED o stanie powietrza

dudus2000, 2020-02-09:
Witam.
Na wstepie przepraszam jezeli moje pytania sa niezbyt powazne, Jestem samoukiem i probuje sie zmierzyc z ta materia.
Nie moge sobie poradzic w dostosowaniu kodu do obslugi diody LED na obudowie smogomierza.
Dioda bedzie infomowala o stanie powietrza bez potrzeby odpalania strony.
Najpierw usuniete zostaly  zdefiniowane piny 12 13 i 14 z DHT22 i SHT1x (D5,D6,D7) w sumie to wszystkim wpisalem jeden nie uzywany pin 10

zdefiniowalem od nowa w/w piny
1sposob
#define ledR 14
#define ledR 12
#define ledR 13

2sposob
const int ledR = 14; //led red
const int ledG = 12; //led green
const int ledB = 13; //led blue
.............................
**nastepnie w :**
void setup() {
// dodany kod
  pinMode(ledR, OUTPUT);
  pinMode(ledG, OUTPUT);
  pinMode(ledB, OUTPUT);
.............................................
 **i w**
void loop() {
krysian();
   yield();
............................................
 **a na koncu funkcja**

void krysian() {
if (averagePM25 <= 10) {
       digitalWrite(ledG, HIGH);
       delay(200);
        digitalWrite(leG, LOW);
        delay(200);
      } else if (averagePM25 > 10 && averagePM25 <= 20) {
        digitalWrite(ledG, HIGH);
        digitalWrite(ledR, HIGH);
      } else if (averagePM25 > 20 && averagePM25 <= 25) {
        digitalWrite(ledB, HIGH);
        digitalWrite(ledR, HIGH);
      } else if (averagePM25 > 25 && averagePM25 <= 50) {
        digitalWrite(ledR, HIGH);
      } else if (averagePM25 > 50) {
        digitalWrite(ledR, HIGH);
        delay(500);
        digitalWrite(ledR, LOW);
        delay(500);
      } else {
        digitalWrite(ledR, HIGH);
        delay(200);
        digitalWrite(ledR, LOW);
        delay(200);
      }
      yield();
  }

efekt:
ze wzgledu na brak podlaczonego czujnika pm mam averagePM25 = 0 - przynajmniej tak pokazuje na stronie ;).
dioda mruga przez jakies 10-20 sek i zatrzymuje sie swiecac
roznie juz kombinowalem i wciaz mam efekt ze sie tak jakby zawieszalo "mruganie"

Przepraszam jezeli nie w tym dziale ale nie wiem gdziebym mogl zadac to pytanie

pozdrawiam
krystian

bfaliszek, 2020-02-09:
> delay(200);
Raczej nie polecam używać delay. Delay blokuje wszystko inne i w czasie delay, ESP8266 nie robi nic, czyli nie wykonuje w tle pomiarów itp. Lepiej użyć millis(). Tutaj przykład jak zrobić pętlę, która przez 20 sekund, będzie wykonywać coś co jest wewnątrz niej, a później przejdzie dalej - https://github.com/hackerspace-silesia/Smogomierz/blob/master/Smogomierz.ino#L869-L876
To najprawdopodobniej powoduje, że program zatrzymuje się na tym świeceniu i nie robi nic więcej.

Kolejna sprawa to delay(200); oznacza wstrzymanie pacy na 200ms. Jeśli wpiszesz delay(1000) to masz wstrzymanie na prawie sekundę. Takie szybkie zmiany mruganie może być problematyczne.

Jak rozumiem masz 3 diody, a nie jedną RGB, która zmienia kolory?W przypadku diody RGB(np. ws2812), nie musisz definiować trzech pinów, tylko na jednym masz wszystko. Plus są bardzo fajne biblioteki do ich obsługi, na przykład - https://github.com/Makuna/NeoPixelBus

Kolejna sprawa - w jaki sposób masz podłączone te trzy diody LED?

Kriztower, 2020-02-09:
Prędzej bym widział żeby inna płytka "odczytywała" pomiar że Smogly i wyświetlała status na LED.

Czujnik jest na zewnątrz, a wizualizacja led w środku 😀

bfaliszek, 2020-02-09:
> Prędzej bym widział żeby inna płytka "odczytywała" pomiar że Smogly i wyświetlała status na LED.
>
> Czujnik jest na zewnątrz, a wizualizacja led w środku 😀

Aktualne dane pomiarowe są zawsze dostępne w formie JSON pod adresem IP_Twojego_SMogly/api możesz pobierać dane z tego JSONa i wizualizować za pomocą LED czy wyświetlać na ekranie.

dudus2000, 2020-02-09:
Czujnik (raczej swiatlo diody) chcialem wystawic na widok wszystkich w okolicy i sa tez ludzie starsi nie obslugujacy komputerow a telefon sluzy im tylko do rozmawiania
Chcialbym stworzyc mozliwosc korzystania przez nich z pomiarow czujnika bez używania jakichkolwiek sprzetow
fajnie by bylo docelowo wystawic duuuuza diode ktorej barwa byla odzwierciedleniem jakosci powietrza
co do millis prubuje go okielznac

majstercar, 2020-02-09:
Ale dostałem do myślenia mam w domu gdzieś paski ip65 na ws (od myfrendów) i tak wymyśliłem sobie dwa paski na obudowie  jeden PM10 drugi PM2.5

dudus2000, 2020-02-09:
Chyba z millis zadzialalo, narazie sie nie zawiesza, ale jak mrugnie niebieska dioda na esp8266 to widac ze troche sie wydluza przejscie  diody mrugajacej  w stan przeciwny

Kriztower, 2020-02-09:
Trochę zrobił się offtopic😀 ale pożyteczny
Podzielcie się panowie kodem swoich projektów dla takich nieogarow jak ja😀

dudus2000, 2020-02-09:
Oglaszam sukces :) dzieki waszej pomocy oczywiscie :)
Podaje swoja konfiguracje
NodeMCU v3, BME280, PMS7003

do pinow D5 D6 i D7 oraz 3V podlaczylem zwykla 4 pionowa diode rgb ktora bedzie pokazywala stan powietrza
kod zaraz podesle, tylko musze to jakos uporzadkowac , bo straszny burdel mi sie do niego wkradl

dudus2000, 2020-02-09:
zanieczyszczenie - kolorow

0-10 zielony
10-20 mruga zielony
20-25 zolty
25-50 czerwony
powyzej 50 mruga czerwony
[Smogomierz.ino.nodemcu.zip](https://github.com/hackerspace-silesia/Smogomierz/files/4177454/Smogomierz.ino.nodemcu.zip)

Kriztower, 2020-02-09:
Mieszkam na Śląsku, więc muszę zmienić progi, bo będę miał cały czas na czerwono 😋
Gratulacje! Dobra robota. Jak chińczyk wyzdrowieje (koronabadziew) to wyślę mi moje diody RGB. Miałem zrobić z nich sygnalizator świateł na przycisk dla dziecka, ale priorytety się dzisiaj zmieniły 😀 pozdrowienia z malowniczego Sosnowca 😀

ookris, 2020-02-10:
> Mieszkam na Śląsku, więc muszę zmienić progi, bo będę miał cały czas na czerwono 😋
To raczej niewiele da bo jakość powietrza i tak będzie zła. Są pewne standardy, których należy się trzymać nawet jeśli dioda będzie się prze 90% czasu świeciła na czerwono.

bfaliszek, 2020-02-11:
W naszym wypadku(w sensie Polski) mamy do wyboru dwa standardy:

+ Polski Indeks Jakości Powietrza: http://powietrze.katowice.wios.gov.pl/indeks-jakosci-powietrza

+ Europejski Indeks Jakości Powietrza: http://airindex.eea.europa.eu (legenda do mapki)

W zależności od tego czy ktoś woli mniej rygorystyczny(polski) czy bardziej rygorystyczny(europejski) indeks jakości powietrza, na takie kolory powinna świecić dioda(lub je zmieniać przy takich wartościach jak w którymś z tych indeksów).

Osobiście zalecam europejski. To, że u nas jest tragicznie źle, nie oznacza, że mamy zrezygnować z wyższych standardów i do nich nie dążyć.

Closed 2021-11-16.

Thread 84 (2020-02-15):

ESP-Wroom-32 - podłączenia przewodów

ebuke, 2020-02-15:
Cześć,

Potrzebuję wsparcia, jak podłączyć przewody do budowy smogomierza, z modułemESP-Wroom-32? Kupiłem taki zgodnie z zaleceniami w instrukcji (https://github.com/hackerspace-silesia/Smogomierz/blob/master/instrukcje/hardware.md) i zacząłem składać, ale brakuje mi pinu GDN.   ESP32 ma 2 piny GND, a potrzeba 3 wg schematu. Będę wdzięczny, za podesłanie schematu, jak zbudować smogomierz w oparciu o moduł ESP32, albo wsparcie jak poradzić sobie z tym podłączeniem. Myślałem o zlutowaniu rodzielacza, tak jak wskazane jest dla zasilania 5V w instrukcji, ale wolę się upewnić czy to dobra droga.

krupniok200, 2020-02-15:
to jest ok droga, możesz zrobić osobną żyłę masową dla czujnika, a masę z czujnika temp/ciśnienia/wilg. do płytki

bfaliszek, 2020-02-16:
Możesz rozdzielić GND tak samo jak rozdzielone jest 5V. W zależności od producenta płytki z ESP, różnie są wyprowadzone piny. Czasami jest kilka GND, czasami jest jedna. Jeśli brakuje, to najprościej zrobić sobie taki rozdzielacz dla 5V i GND, bo tego najczęściej brakuje.

ebuke, 2020-02-23:
Wszystko działa, dzięki. Dla tych którzy kiedyś będą mieli podobne problemy, to opis podłączenia przewodów jest w komentarzu w kodzie.

ebuke, 2020-02-23:
Wszystko działa, dzięki. Dla tych którzy kiedyś będą mieli podobne problemy, to opis podłączenia przewodów jest w komentarzu w kodzie.

Closed 2020-02-23.

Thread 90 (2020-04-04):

Dwa problemy: brakujące pomiary oraz MQTT

tnowak, 2020-04-04:
Hej. W końcu znalazłem czas aby złożyć zestaw DYI kupiony w Botlandzie.
Dzięki zamieszczonej tu instrukcji dałem radę mimo, że z "kabelkami" w życiu miałem mało do czynienia.
Po wgraniu firmware (tego też musiałem się nauczyć) i uruchomieniu urządzenia zidentyfikowałem dwa problemy, z którymi nie mogę sobie poradzić:

1. Nie wiem dlaczego, ale nie widzę pomiarów temperatury i wilgotności.
Konfigurację mam zrobioną tak:

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

A pomiary wyglądają tak:

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

API też zwraca tylko zanieczyszczenia:

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

To samo z MQTT.
Czy coś robię źle?
Wydaje mi się, że kabelki podłączyłem zgodnie z instrukcją:

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

2. Mój drugi problem dotyczy konfiguracji MQTT:

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

Czy jest jakiś powód, dla którego smogomierz publikuje w ścieżce zaczynającej się od slasha?
Zgodnie z dokumentacją MQTT slashe rozdzielają poziomy, więc tu jakby poziom pierwszy jest pusty. Być może jest to dopuszczalne technicznie, ale na pewno dziwne. Mam ok 100 urządzeń publikujących w MQTT i żaden ich temat nie zaczyna się od slasha, tylko od nazwy poziomu.

Widziałem na różnych screenach tutaj, że wcześniej tak nie było. To błąd, czy jakaś zmiana?
Jeśli zmiana, to czy jest jakaś szansa, aby dodać do oprogramowania opcję "do not start MQTT topic with a slash"?

Dzięki z góry za pomoc.

bfaliszek, 2020-04-04:
1) to albo masz źle podłączone BME280 albo sam moduł BME280 jest wadliwy. Dlatego nigdzie nie pokazuje danych pomiarowych.

2) tak sugerowano mi we wcześniejszym wątku o MQTT - https://github.com/hackerspace-silesia/Smogomierz/issues/54. Jak rozumiem, chodzi Ci o to, żeby było `smogly/sensor/PM10/4` a nie `/smogly/sensor/PM10/4`?

tnowak, 2020-04-04:
Dzięki za szybką odpowiedź.

Ad.1.
BME280 które dostałem ma 6 pinów, u Was na zdjęciach 4 - nie wiem czy ma to znaczenie. W każdym razie mam je podłączone tak:

```
BME   | ESP8266/NodeMCU
======+================
VCC ----> 3V
GND ----> G
SCL ----> D4
SDA ----> D3
```

Pozostałe dwa piny na BME280 (SCB i SDO) są wolne.
Chyba więc jest dobrze.
No to by wynikało, że czujnik jest uszkodzony :/

Ad.2.
Dokładnie tak.

Jest jeszcze jedna "dziwność" w tej implementacji MQTT, właściwie z tej samej bajki co slash na początku, bo dotyczy slasha na końcu.
Chodzi o to, że wartość podana na ostatnim poziomie nie ma żadnej nazwy.
Czyli przykładowo jest tak:
smogly/sensor/PM10/=5
A na podstawie dużej liczby innych urządzeń MQTT które mam powiedziałbym, że standardem jest coś takiego:
smogly/sensor/PM10/value=5
Czyli "monitorowany" przez klienta temat zaczyna oraz kończy się nazwą poziomu (a nie separatorem).
Obecny format da się odczytać, ale po prostu zwracam uwagę, że to dziwna konstrukcja.

tnowak, 2020-04-04:
Update: jednak miałem jakiś problem u siebie w systemie z odczytem aktualnego formatu (ze slashem na początku i na końcu).
Tymczasowo zrobiłem w Node-RED konwersję na "standard"

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

To oczywiście głupie, bo dane trafiają do MQTT dwa razy i na około, więc fajnie byłoby gdyby można było w firmware skonfigurować sobie odpowiednio 🙏

tnowak, 2020-04-09:
Błażej, no niestety to nie była wina wadliwego czujnika BME280.
"Wykosztowałem" się na dwa kolejne BME280 (dwa aby mieć pewność) i NA ŻADNYM Wasz soft nie działa.
A wszystko podłączone zgodnie z instrukcją - sprawdzałem 10 razy. Kabelki też na wszelki wypadek wymieniałem.

Dla już absolutnej pewności natrudziłem się i zainstalowałem na płytce ESPeasy wersja Dev (bo ma też obsługę PMS7003).
Wszystkie trzy czujniki BME280 bez problemu są widziane przez ESPeasy. Oto dowód:

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

Tak naprawdę chciałem już machnąć ręką na Wasz soft i zostać na ESPEasy, ale na nim obsługa PMS7003 jest jeszcze bardzo szczątkowa i nie ma np. dobrze zrobionych cyklicznych pomiarów.
Jest tylko pomiar ciągły, a w ten sposób mój sensor pożyje tylko rok.

Tak więc bardzo uprzejmie proszę o pilną weryfikację tego błędu, zobaczenie co może być nie tak
i możliwie szybkie naprawienie.

jakubcichocki, 2020-04-09:
> Tak więc bardzo uprzejmie proszę o pilną weryfikację tego błędu, zobaczenie co może być nie tak
> i możliwie szybkie naprawienie.

Jak roszczeniowo się zrobiło w stosunku do projektu open source, ojoj.

Spróbuj podłączyć się pod smogomierz b

akotas, 2020-04-09:
Jeśli chodzi o BME280 to raczej nie błąd w kodzie, no chyba ze coś poszło nie tak w kompilacji. wczoraj wgrywałem 2.7.5 do takiego samego świeżego zestawu i śmiga.

Jak kolega Jakub mówi USB debug i logi, nikt tego za Ciebie nie zrobi. Jak by co wrzuć tu dump logów to się zobaczy.

tnowak, 2020-04-09:
To wszystko jest naprawdę dziwne. Wróciłem dzisiaj do firmware'u smogly, aby wykonać te debugi po USB (choć jeszcze nie wiem jak, ale nauczyłbym się) i jestem totalnie zaskoczony dwoma zdarzeniami:

1. Po wgraniu firmware, nie mogłem znaleźć telefonem hostspotu smogomierz-xxxxx.
Ku mojemu szczeremu zaskoczeniu, smogly już był podłączony do mojej sieci Wifi.
Myślałem że taki firmware flash robi orkę na chipie i wrzuca się w formie dziwiczej.
Jak przejście przy przejściu z ESP Easy do smogly uchowało się hasło do mojego wifi? 😮

2. Drugie zaskoczenie - zgadnijcie co?! Tak, dobrze się domyślacie (- TVP Style 😁)

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

Najciekawsze jest to, że wszystko jest IDENTYCZNIE podłączone. Specjalnie robiłem zdjęcia
wtedy i teraz, więc mam pewność.

Naprawdę nie wiem co wtedy poszło nie tak i jest to nurtujące. Jedyną "odchyłką" od normy jak mogłem popełnić w całym procesie, to użycie innego programu do flashowania. NodeMCU-PyFlasher-4.0-x86.exe coś mi nie chciał działać z początku, więc użyłem ESP8266Flasher.exe. Ale używałem go zarówno wtedy, jak i teraz (jak również do wgrania ESP Easy).

Jestem początkujący w te klocki (esp, flashowanie, kabelki) i chodzę trochę po omacku,
wybaczcie jeśli robię jakieś głupie rzeczy.

tnowak, 2020-04-09:
A tak przy okazji, to zgłaszam jeszcze "czeski błąd" z tymi placeholderami:

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

Zauważyłem dopiero jak zobaczyłem:

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

:)

bfaliszek, 2020-04-09:
Faktycznie odwrotnie wpisałem w domyślnych ustawieniach. W każdym razie to można samemu edytować, więc nie jet to nic poważnego.

Cieszę się, że problem z BME280 został rozwiązany :)

bfaliszek, 2020-04-20:
@tnowak dodałem opcję wyłączenia tego '/' na początku topicu oraz poprawiłem ten błąd z ciśnieniem i wilgotnością. Na razie w wersji prerelease dla ESP8266 z miernikiem PMS
https://github.com/hackerspace-silesia/Smogomierz/tree/dev/firmware/ESP8266

tnowak, 2020-04-21:
Chciałem wypróbować, ale wyskakuje mi błąd:
Update error: ERROR[10]: Magic byte is wrong, not 0xE9

bfaliszek, 2020-04-21:
Masz ESP32 czy ESP8266? Wersja dla ESP32 jest tutaj - https://github.com/hackerspace-silesia/Smogomierz/tree/dev/firmware/ESP32

tnowak, 2020-04-21:
Mam ESP8266, próbowałem .bin dla tego właśnie

bfaliszek, 2020-04-21:
Spróbuj pobrać jeszcze raz .bin i wgrać. Jeśli problem będzie się powtarzał, to sprawdź czy zmiana zasilacza coś da. Znalazłem info, że ten błąd może być spowodowany za słabym zasilaczem.

tnowak, 2020-04-22:
Zasilacz mam klasyczny beczkowy DC 5V 2A, więc raczej prądu pod dostatkiem.
Ale pobrałem jeszcze raz ten .bin i rzeczywiście - tym razem weszło!
Dziwności... ale najważniejsze że działa 💪

bfaliszek, 2020-04-22:
Czyli jak rozumie, chodziło o takie coś, żeby nie było '/' na początku i teraz jest już ok?

tnowak, 2020-04-22:
Tak, tzn. to załatwia większą część sprawy. Ale rzecze mówiąc byłoby już tak zupełnie idealnie, gdybyś dodał jeszcze jedną, analogiczną opcję odnośnie slasha na końcu, tj:

Add '/' at the beginning of the topic: [No]
**Add '/' at the end of the topic: [No]**    <-------- o to mi chodzi

Bo przeznaczeniem slasha w tematach MQTT jest separacja członów tematu, więc zarówno rozpoczynanie tematu od slasha jak i kończenie slashem wydaje się bezzasadne (nie ma od czego separować). Na około 90 pomiarów jakie zbieram przez MQTT żadnej temat nie kończy się slashem, tu przykładowo parę:

```
conbee/Aqara_Temp_Sensor_3H/humidity=40.37
conbee/Aqara_Temp_Sensor_3T/temperature=25.85
iobroker/mihome-humidifier/0/info/humidity=49
mqttmiot/airpurifier/humidity/state=43
mqttmiot/airpurifier/pm25/state=17
espeasy/MH-Z19B/PPM=982
espeasy/MH-Z19B/Temperature=27.0

```

W smogly jest obecnie tak (sam pewnie przyznasz, że trochę dziwnie):
```
smogly/sensor/temperature/=15.05
smogly/sensor/humidity/=37.55
smogly/sensor/pressure/=1028.61
smogly/sensor/PM10/=24
smogly/sensor/PM2.5/=23
itd.

```
A w mojej ocenie domyślnie mogłoby to wyglądać tak:
```
smogly/sensor/temperature=15.05
smogly/sensor/humidity=37.55
smogly/sensor/pressure=1028.61
smogly/sensor/PM10=24
smogly/sensor/PM2.5=23
itd.
```

Chyba lepiej pasowałoby to do praktyk stosowanych w branży i przez inne urządzenia.
I do tego wystarczy jedynie dodanie tej drugiej opcji (która jednocześnie pozwoli zachować kompatybilność wsteczną)

bfaliszek, 2020-04-22:
Dodałem 😉
Nowe pliki .bin są tutaj - https://github.com/hackerspace-silesia/Smogomierz/tree/dev/firmware

tnowak, 2020-04-22:
Działa jak złoto! Dzięki!!! 🙌 Zamykam issue bo wszystko z niej już rozwiązane!

Closed 2020-04-22.

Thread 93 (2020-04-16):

no matching function for call to 'esp8266webserver - problem z kompilacją kodu Smogomierz

Ralphie71, 2020-04-16:
Witam,

Chciałbym zmienić tło w stronie WWW wyświetlającej wyniki pomiarów z białego na czarne i litery białe dla kontrastu  ( wyświetlam wyniki na urządzeniu mobilnym w sposób ciągły i ekran szybko pochłania energię i rozładowuje baterie ).
Zacząłem od instalacji najnowszego 1.8.12 IDE Arduino i bibliotek dla płytek aby skompilować kod źródłowy Smogomierz i niestety jeszcze bez wprowadzania zmian w kodzie obecna wersja Smogomierza 2.7.5  wyrzuca błąd podczas kompilacji w sekcji dot. AsyncWebServer:

exit status 1
no matching function for call to 'esp8266webserver::ESP8266WebServerTemplate<WiFiServer>::on(const char [2], WebRequestMethod, void (&)())'

Czytałem o tym w Internecie i chodzi chyba o błędne użycie funkcji wymagającej parametru bez możliwości jej przekazania dalej  -> niestety nie jest to  na moim poziomie   :-(   i  nie jestem w stanie tego poprawić w kodzie ESPWebServera.

Proszę o poprawienie problemu z kodem tak aby kod źródłowy mógł się kompilować w IDE.
Z góry dziękuję.

W załączeniu kopia opisu błędu.

[blad_webserver.txt](https://github.com/hackerspace-silesia/Smogomierz/files/4487296/blad_webserver.txt)

Pozdrawiam, dziękuję  i gratuluję takiego przydatnego urządzenia jak Smogomierz.

Rafał

bfaliszek, 2020-04-16:
Pobierz jeszcze raz kod z githuba i zainstaluj wszystkie wymagane biblioteki: ArduinoJson, Adafruit BMP280 Library, DHT sensor library by Adafruit, ThingSpeak, Adafruit Unified Sensor oraz PubSubClient. Na koniec ręcznie doinstaluj biblioteki z plików zip:  ESPAsyncWebServer oraz ESPAsyncTCP. W przypadku ESP32 musimy doinstalować jeszcze AsyncTCP. W przypadku ESP32 musimy również doinstalować Pythona3 oraz pyserial. Więcej info na https://github.com/hackerspace-silesia/Smogomierz/blob/master/instrukcje/software.md#arduino---konfiguracja

Ralphie71, 2020-04-16:
Zrobiłem jak pisałeś. Niestety nie pomogło - w starym pliku 2.7.5  który opisałem powyżej pozostaje ten sam błąd a w nowym który ściągnąłem z githuba jak radziłeś jest:

Błąd kompilacji dla płytki NodeMCU 1.0 (ESP-12E Module)

zmieniałem typy płytek i dla każdej był ten sam błąd kompilacji danej płytki.

Nie wiem - pewnie coś z moim środowiskiem IDE jest nie tak bo skoro innym się kompiluje a u mnie nie to cóż.....
Prosiłbym może abyś dodał  "czarny Theme" strony www Smogomierza jako opcję dla oszczędzających energię baterii gdy będziesz przygotowywał nową paczkę aktualizacyjną ?
Byłbym wdzięczny.

Rafał
[blad_details.txt](https://github.com/hackerspace-silesia/Smogomierz/files/4488875/blad_details.txt)

bfaliszek, 2020-04-17:
Będę pamiętał przy kolejnej aktualizacji.
Jeśli chodzi o ustawienia ArduinoIDE:
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
Możesz sprawdzić jeszcze kod z brancha dev. Tam dodaję na bierząco poprawki i jak się nazbiera więcej to puszczam jako finalna wersja - https://github.com/hackerspace-silesia/Smogomierz/tree/dev

majstercar, 2020-04-17:
Fajnie - ale mam problem z esp32 pomimo zmiany nazwy sprawdzone w de-bug moja sieć widzi dalej espresif - co robię źle  wszystko działa?

bfaliszek, 2020-04-18:
Wszędzie wcześniej pisałeś, że błąd to "Błąd kompilacji dla płytki NodeMCU 1.0 (ESP-12E Module)". Jeśli masz ustawione NodeMCU, to masz ESP8266, a nie ESP32. Dla ESP32 musisz mieć konfigurację dla ESP32.
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

Ralphie71, 2020-04-19:
Cześć,
wpadłem na jeszcze jeden pomysł ->  żeby kompilować zmieniając za każdym niepowodzeniem wersję biblioteki płytek  ESP8266 Community gdyż przy najnowszej która zainstalowała się razem z Arduino był błąd kompilacji dla płytki NodeMCU 1.0 (ESP-12E Module)  jak pisałem wyżej.

Zacząłem od wersji 2.3.0  i szedłem w górę i przy wersji 2.5.0  udało mi się skompilować kod Smogomierza !!!.

Musisz chyba podawać przy plikach źródłowych Smogomierza przy której wersji biblioteki płytek tworzysz kod bo najwyraźniej wersja nowsza biblioteki nie zawsze jest zgodna wstecznie..... i stąd może być błąd kompilacji NodeMCU 1.0 (ESP-12E Module).

Mi udało się przy 2.5.0  i już nie próbowałem kolejnej wersji żeby nie zepsuć   :-)

bfaliszek, 2020-04-20:
Zawsze używam najnowszej dostępnej, obecnie 2.6.3. W branży dev, wszystko działa i się kompiluje.

Closed 2020-04-26.

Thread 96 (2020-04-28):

Nieprawidłowe odczyty z DHT22

grucha532, 2020-04-28:
Witam,

Mam problem z konfiguracją bądź odczytami z czujników. Kombinuje już drugi dzień i niestety bez powodzenia.

Otóż w konfiguratorze IP_Smogly odczyty pogody oraz jakości powietrza są następujące:
### Weather:
Temperature: 2147483647 °C
Humidity: 2147483647 %
Dewpoint: 2147483647 °C
### Air pollution:
PM1: -1 µg/m³
PM2.5:  -1 µg/m³
PM10:  -1 µg/m³

Sprawdziłem 3x i wszystko podpięte jest poprawnie. Użyłem czujników PMS7003 oraz DHT22 (podpięte do ESP8266). W ustawieniach urządzeń Smogly ten pierwszy ustawiony jako PIN TX: D1 oraz PIN RX: D2, natomiast ten drugi DHT22 PIN SDA: D7 oraz PIN SCL: D7. W rzeczywistości jednak czujnik ten ma tylko 3 wyjscia, dlatego nie wiedziałem co wybrać jako SCL. Probówałem tutaj podpinać czujnik DHT22 zarówno z rezystorem podciągającym (10k) jak i bez niego. W obu przypadkach te same wyniki.
Podpiąłem również Homebridge lecz tam czujniki te chociaż się wyświetlają to nie odpowiadają.

Czy miał ktoś podobny problem i/lub wie jak to rozwiązać?

Z góry dziękuję za rady/wskazówki.

bfaliszek, 2020-04-28:
Sprawdź jak będzie działać bez DHT22

grucha532, 2020-04-30:
Nie wiem co ostatecznie miało wpływ, lecz czujnik pyłów zaczął prawie działać tj. czasem pokazuje wartości PM a czasem 0µg/m³ i dopiero po kilku minutach się aktualizuje (co i tak jest postępem). Obecnie działa z podpiętym DHT22, którego wyniki to nadal:
Temperature: 2147483647 °C
Humidity: 2147483647 %
Dewpoint: 2147483647 °C

Mam dwa czujniki DHT22 i testowałem oba i oba działają - sprawdzone na RPi), tak jak pisałem zarówno z rezystorem jak i bez niego. Czy ustawienia Smogly mam poprawne? Jeśli chodzi o SCL to próbowałem wszystkich możliwości.

Nie wiem czy to efekt czy może wskazówka szukając przyczyny, lecz komunikacja z Homebridge (tj. wyników w aplikacji Home) jest słaba tj. aby na smartphonie sprawdzić jakość powietrza muszę kliknąć kafelek "Air Quality" i wtedy albo się zaktualizuje i pokaże ocenę np. "good", po czym wychodzę z tego jednego czujnika na stronę pokoju w aplikacji gdzie czujników jest wiele, w tym momencie wszystkie czujniki się aktualizują a następnie kafelek "Air Quality" zmienia status na brak odpowiedzi. --> jeśli to jest jedynie negatywny efekt a nie wskazanie, że zawodzi tutaj gdzieś komunikacja to wrócę do niego później - po rozwiązaniu problemu z czujnikiem.

bfaliszek, 2020-04-30:
Naprawiłem obsługę DHT22. Wrzuć sobie .bin prerelease z https://github.com/hackerspace-silesia/Smogomierz/tree/dev/firmware/ESP8266 Wersja dla ESP8266 i miernika PMSx003.

grucha532, 2020-04-30:
Działa! Super, dziękuję :)

bfaliszek, 2020-05-03:
https://github.com/hackerspace-silesia/Smogomierz/releases/tag/v2.7.9

Closed 2020-05-03.

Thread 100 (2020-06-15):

Request from AirMonitor

airmonitor, 2020-06-15:
Cześć Błażej,

Dałbyś radę wrzucić do następnej wersji interwał przesyłania danych do API AirMonitora na minimalną wartość 30 minut?

Najlepiej tez jitter aby rozłożyć workload między 60 a 300 sekund.

Czyli każda stacja wysyłałaby metryki co 30 minut +- 60 do 300 sekund.

bfaliszek, 2020-06-16:
Dodałem w kodzie minimalną wartość interwału dla AirMonitora to 30 minut. Jedynie w przypadku włączonego DEEPSLEEP w ESP może być inna, bo jest wtedy uzależniona od tego kiedy wybudza się samo ESP. https://github.com/hackerspace-silesia/Smogomierz/commit/7d805e06e04d6a713c66249dad52816e125c2440

Closed 2021-04-08.

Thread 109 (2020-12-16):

Problem z kompilacją na ESP32

ebuke, 2020-12-16:
cześć,
Mam problem z kompilacją na płytce ESP32. Ktoś ma pomysł o co chodzi?

wysypuje się na linii 875
#elif defined ARDUINO_ARCH_ESP32
    sprintf(device_name, "Smogly-%06X", ESP.getEfuseMac());

exit status 1
comparison with string literal results in unspecified behaviour [-Werror=address]

bfaliszek, 2020-12-17:
Hej!
Użyłeś kodu z dev? https://github.com/hackerspace-silesia/Smogomierz/tree/dev
Zmieniałeś coś w nim? Jaką masz ustawioną płytkę ESP32 w ArduinoIDE? Ja kompiluję zawsze na ESP32 Dev Module

ebuke, 2020-12-17:
Hej. Kod mam z mastera. Nic nie zmieniałem. Kompiluję też na ESP32 DEV Module. Może brakuje mi którejś biblioteki poza tymi które są w instrukcji?

ebuke, 2020-12-19:
Winne ustawienia ostrzeżeń kompilatora. Były za wysokie.

Closed 2020-12-19.

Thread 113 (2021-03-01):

Guru Meditation Error: Core  1 panic'ed (LoadProhibited) podczas sprawdzania update

mjarosie, 2021-03-01:
Hej, dzięki za super robotę, instrukcje budowy Smogomierza są bardzo pomocne! : )

Podczas włączania urządzenia, z jakiegoś powodu zapytanie do https://smogomierz.hs-silesia.pl/firmware/latest_esp32.json zwraca kod `-1` ([tutaj](https://github.com/hackerspace-silesia/Smogomierz/blob/375a111aa2468572a48c8fa69fa649c81c447790/src/autoupdate.cpp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)). Kod dochodząc do [tej linii](https://github.com/hackerspace-silesia/Smogomierz/blob/375a111aa2468572a48c8fa69fa649c81c447790/src/autoupdate.cpp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), rzuca błąd:

```
connected...yeey :)
Waiting for NTP time sync:
Current time: Mon Mar  1 18:53:26 2021
GET... failed, error: connection refused
Guru Meditation Error: Core  1 panic'ed (LoadProhibited). Exception was unhandled.
Core 1 register dump:
PC      : 0x4000159c  PS      : 0x00060c30  A0      : 0x800f224a  A1      : 0x3ffb1b30
A2      : 0x3ffc5820  A3      : 0x00000001  A4      : 0x00000020  A5      : 0x0000ff00
A6      : 0x00ff0000  A7      : 0xff000000  A8      : 0x80102029  A9      : 0x3ffb1b00
A10     : 0x3ffc5820  A11     : 0x000000ff  A12     : 0x00000029  A13     : 0x3ffb1b20
A14     : 0x3ffb1aa0  A15     : 0x00000008  SAR     : 0x00000010  EXCCAUSE: 0x0000001c
EXCVADDR: 0x00000001  LBEG    : 0x400014fd  LEND    : 0x4000150d  LCOUNT  : 0xfffffffb

ELF file SHA256: 0000000000000000

Backtrace: 0x4000159c:0x3ffb1b30 0x400f2247:0x3ffb1b40 0x400e4a9f:0x3ffb1f70 0x4010ad52:0x3ffb1fb0 0x4008a6f2:0x3ffb1fd0

Rebooting...
```

`strncpy` jest wywolane na niezainicjalizowanej pamięci zadeklarowanej [tutaj](https://github.com/hackerspace-silesia/Smogomierz/blob/375a111aa2468572a48c8fa69fa649c81c447790/src/autoupdate.cpp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).

Po użyciu [exception stack trace decoder](https://github.com/me-no-dev/EspExceptionDecoder) register dump wygląda tak:

```
PC: 0x4000159c
EXCVADDR: 0x00000001

Decoding stack results
0x400f2247: checkUpdate(int) at /var/folders/7d/0fcl4nds6xd1_sjw8c0ndsn80000gp/T/arduino_build_272800/sketch/src/autoupdate.cpp line 164
0x400e4a9f: setup() at /Users/mjarosie/source/mjarosie/Smogomierz/Smogomierz.ino line 660
0x4010ad52: cbuf::write(char const*, unsigned int) at /Users/mjarosie/Library/Arduino15/packages/esp32/hardware/esp32/1.0.5/cores/esp32/cbuf.cpp line 171
0x4008a6f2: vPortTaskWrapper at /home/runner/work/esp32-arduino-lib-builder/esp32-arduino-lib-builder/esp-idf/components/freertos/port.c line 143
```

mjarosie, 2021-03-01:
Quickfix: zainicjalizowanie zmiennej, np:

```
ServerSW = "2.7.9";
```

bfaliszek, 2021-03-02:
https://github.com/hackerspace-silesia/Smogomierz/commit/ed85019f8a8f7bc6c4407df713f4310df3992f6a

Closed 2021-04-08.

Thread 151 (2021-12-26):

Bład zapisu ustawień

monteros007, 2021-12-26:
Po ostatnim update praktycznie nic nie działa prawidłowo. Prosty zapis ustawień jak zmiana wysokości, kończy się przerwaniem pracy i błędem wczytywania strony. To co idzie w URL:
http://IP/config_device_save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

Kiedy już uda się coś zapisać, to nie idzie ustawić influx db, przycisk zapisz zlewa się z wpisaniem hasło do bazy.

ESP8266.bin

mrozu-poland, 2021-12-31:
Nie ma możliwości zapisu konfiguracji dla serwera MQTT, nie zapamiętuje hosta, portu, i parametrów kolejek.
Nie ma możliwości zapisu konfiguracji dla ThingSpeak-a (pola ChanellId - cały czas jest 57365, i ReadAPIKey - nie zapamiętuje). WriteApiKey zapisuje się i dane są wysyłane poprawnie do serwisu.

bryan-pl, 2022-01-01:
Dokładnie to samo mam na ESP32 - po wrzuceniu flasha przez esphome-flasher konsula zrzuca takie coś:
_[00:16:49]Mounting FS...
[00:16:49]E (65) SPIFFS: mount failed, -10025
[00:16:49]Failed to parse config file
[00:16:49]Failed to load config
[00:16:49]Saving the current config..._
Smogly działa itp, ale tak jak u Mrozu-Poland nie zapisuje ustawień MQTT i przez to MQTT nie działa.

bfaliszek, 2022-01-04:
Czyli jak rozumiem problem jest tylko ustawieniami MQTT?

monteros007, 2022-01-04:
>

Z zapisem danych do influxDB tak samo. To w ogóle nie działa po ostatnim update.

bryan-pl, 2022-01-04:
Z dodatkowych rzeczy - niekoniecznie związanych z zapisem konfiguracji - jak zaznaczy się wyświetlanie danych z airmonitor czy community.sensor, to okienka owszem są, ale w przekazanych żądaniach HTML nie ma identyfikatora stacji / lokalizacji i wykresy są puste.

kpoow, 2022-01-04:
U mnie jest podobnie z wysypującym się urządzeniem przy zapisie ustawień (mam wgrany najnowszy soft dla ESP8266) . Dodatkowo jak próbuję połączyć płytkę z siecią Wifi to nie ładuje się UI do wyboru sieci. Da się to obejść uderzając bezpośrednio w link http://smogomierz-ip/wifisave?s=<nazwa_sieci>&p=<haslo>, wtedy poprawnie połączy się z siecią.

bfaliszek, 2022-01-04:
> Z dodatkowych rzeczy - niekoniecznie związanych z zapisem konfiguracji - jak zaznaczy się wyświetlanie danych z airmonitor czy community.sensor, to okienka owszem są, ale w przekazanych żądaniach HTML nie ma identyfikatora stacji / lokalizacji i wykresy są puste.

Nie wiem jak z airmonitor, ale wykresy z community.sensor pojawiają się po jakimś czasie. Na początku są puste. Dopiero, gdy będzie trochę danych w ich bazie, to są generowane. Nie wiem dokładnie po jakim czasie ale na pewno nie szybciej niż 30 minut. Dopiero, gdy będzie tyle danych i wykona się restart urządzenia, to będzie dostępne ID dla community.sensor

bryan-pl, 2022-01-04:
Na stronie community sensor te statystyki są od tygodnia i oba wykresy pojawiają się OK. Problem jest po stronie smogomierza, bo wyświetla puste wykresy z uwagi na to, że w linku do nich nie ma id stacji (node=0) zamiast node=id_stacji_w_community_sensor:

> <iframe src='https://maps.sensor.community/grafana/d-solo/000000004/single-sensor-view?orgId=1&panelId=2&var-node=0' ></iframe>

Natomiast na airmonitor wykresy wyświetlają się puste błędem 404. W linku do nich są przekazane koordynaty stacji, na stronie airmonitor dane ze smogomierza są widoczne.

monteros007, 2022-01-04:
Ta wersja nie nadaje się na produkcję moim zdaniem. Jak dla mnie to w 2.7.9 poprawić CSS na poprawny URL i wydać wersję 2.7.9.1. Próbowałem sam skompilować 2.7.9 z tą poprawką ale za cienki jestem na c++ ;/

bfaliszek, 2022-01-04:
@bryan-pl
Mówisz o wersji ESP32 czy ESP8266?
Na ESP8266 nie działa airmonitor.

Jeśli chodzi o sensor.community, to żeby wyświetlić wykresy musisz mieć podane odpowiednie(takie same jak na ich stronie) współrzędne GPS. Urządzenie przy starcie sprawdza najbliższe stacje sensor.community dla tych współrzędnych i ściąga ich ID. To ID jest wymagane do wyświetlania wykresów. Nie wiem jak inaczej wydobyć to ID, bo jest ono inne niż to w panelu na stronie sensor.community. Ogólnie to przy wykresach sensor.community dwie rzeczy mogą pójść źle:
1) rozbierze koordynaty w ustawieniach i panelu sensor.community
2) błąd przy pobieraniu ID przy starcie Smogomierza

bfaliszek, 2022-01-04:
**MQTT**
Powrót do pełnego wsparcie MQTT w 2.8.x chcę zrobić po tym, gdy wersja dla ESP32 będzie dobrze działać z BME280/PMSx003. Właśnie skończyłem to robić i powinno być teraz ok, ale chcę to przez kilka dni potestować.
W 2.7.9 MQTT chyba działało poprawnie, ale nie korzystałem z niego, więc ciężko mi potwierdzić.

bryan-pl, 2022-01-04:
> @bryan-pl Mówisz o wersji ESP32 czy ESP8266? Na ESP8266 nie działa airmonitor.

Mówię o ESP32 gdzie nie trzyma części ustawień - szczególnie tych odnośnie przy MQTT

na ESP 8266 problemy z tą wersją są inne - każda próba zapisu ustawień powoduje reset ustawień wifi i smogomierz ustawia się na domyślnym wifi.

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
To muszę zbadać, bo luftdaten operuje na stałoprzecinkowych liczbach przy podawaniu lokalizacji.

bfaliszek, 2022-01-04:
@bryan-pl w sumie mogę dać opcję wpisywania tego ID ręcznie. Po kliknięciu w Dane odpowiedniego urządzenia na devices.sensor.community jest Sensor ID dla miernika pyłu i on jest potrzebny do wykresów.

bryan-pl, 2022-01-04:
> @bryan-pl w sumie mogę dać opcję wpisywania tego ID ręcznie. Po kliknięciu w Dane odpowiedniego urządzenia na devices.sensor.community jest Sensor ID dla miernika pyłu i on jest potrzebny do wykresów.

Dokładnie tak byłoby prościej -  próbowałem wywołać to api które powinno pobrać adres miernika, ale okazuje się że nie działa  tam teoretycznie powinny pojawić się wszystkie mierniki z prostokąta wskazanego koordynatami, ale jakoś tak to dziwnie działa że oba punkty są tożsame i zwraca null. Udało mi się pobrać dopiero jak zmniejszyłem precyzję zapytania do 3 miejsc po przecinku. Tak że lepiej to będzie ustawić na sztywno.

bfaliszek, 2022-01-05:
@bryan-pl Już jest w branch dev. Pliki .bin dla ESP32 i ESP8266. Dodałem tam w ustawieniach serwisów opcję wpisania ręcznie Sensor ID. Wyłączyłem też to automatyczne wyszukiwanie. Trzeba zawsze je podać ręcznie w ustawieniach.
https://github.com/hackerspace-silesia/Smogomierz/tree/dev/firmware
prerelease_ESPxxxx_Smogomierz_2.8.2_PMS_build_5.01.2022.bin

bryan-pl, 2022-01-05:
@bfaliszek - Wrzuciłem, ustawiłem ID i wykresy się wyświetlają poprawnie. Ta opcja jest dużo prostsza niż wydłubywanie ID z api luftdaten przy starcie. DzięKi!

bryan-pl, 2022-01-05:
Zostaje jeszcze MQTT - sprawdziłem zarówno w ESP32 jak i w ESP8266 nie zapisuje ustawień serwera i portu.

bfaliszek, 2022-01-05:
OK, czyli zostało poprawienie MQTT, sprawdzenie czy działa influxDB oraz aktualizacja biblioteki HomeKi(tylko na ESP32)

bryan-pl, 2022-01-05:
Dzięki -czy mógłbym prosić o listę bibliotek aktualnie wykorzystywanych przez smogomierz do ESP32. Mam u siebie niezły bałagan sporo mi się wywala w trakcie kompilacji.
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
monteros007, 2022-02-28:
W porządku ale jak z krzaków ͬ⸮ ⸮⸮⸮<⸮X
 zrobić użytek?

monteros007, 2022-02-28:
Proszę, logi w załączniku. Nic nie zdążyłem zrobić. 1 podłączenie do wifi, ou yeah i za chwilę restart do ustawień fabrycznych
[logi.txt](https://github.com/hackerspace-silesia/Smogomierz/files/8154636/logi.txt)
.

bfaliszek, 2022-03-01:
OK, ale to nie jest związane z zapisem, tylko masz restart zaraz po ustawieniu połączenia wifi. Nigdzie nie masz zmiany ustawień

bfaliszek, 2022-03-02:
Masz podłączone DHT22?

mati75, 2022-05-15:
Mam dokładnie to samo, bez podłączonych żadnych czujników.

austinroolon, 2022-05-30:
U mnie po aktualizacji (8266, BMP280, SPS30 nie da się ustawić poprawnie portów SPS oraz niektórych danych ThingSpeak. Wersja 2.7.9 SPS30 działa najlepiej, ale nie generuje poprawnie grafik na www. Do Thinkspeak raporty wysyła poprawnie. Ustawiłem wstępnie dane ThinkSpeak na wersji 2.7.9 i podniosłem do najnowszej SPS30. Gubi wpisy. Ręcznie wprowadzone ponownie nie zapamiętuje, albo zastępuje innym (nieznanym mi, tym samym za każdym razem). Póki co niestety jedynie działa u mnie 2.7.9 SPS30 - nie generuje poprawnie www i nie usypia SPS30 między pomiarami przez co szybko drenuje akumulator. Nawet na Sleep=1 (to już omawialiśmy). Gdzie zapisywane są ustawienia ?

dudus2000, 2022-06-13:
Czesc.
Esp8266 - bme280 - pms7003
Wszstko sie sypie po probie zapisu ustawien MQTT
Mam pytanie - czy moglibyscie wydac porawke w formie ostatnio dzialajacego softu.
Czy z takim spreparowanym softem z wyzszym nr pozwoli przeprowadzic zdalna aktualizacje??
Niestety nie mam dostepu do urzadzenia a korzystam tylko z mqtt

hanskiepl, 2022-09-03:
Cześć,
coś sie posypało u mnie też... nie wiem dlaczego. testowałem inne ESP ale jest tak samo.
Nawet po restarcie urządzenie (np zanik zasilania) gubi ustawienia wifi i trzeba sie logować do jego sieci i przestawiać.
Da się to jakoś obejśc na stałe ? kompilowac samem i na sztywno podać dane wifi ?
Czy może ja coś źle robię ?

hanskiepl, 2022-09-08:
Przeszedłem całą procedure programowania nowej płytki ESP8266 i to samo. nie zapamętje SSIDa do Wifi i po restarcie tworzy swoją sieć czekając na konfigurację.
Co jest grane ? jak temu zapobiec ?

hanskiepl, 2022-09-08:
Ok juz znalazłem rozwiązanie. Trzeba pozmienić kody żródłowe ESPASyncWifiManagera
https://github.com/alanswx/ESPAsyncWiFiManager/issues/102

> OK, ale to nie jest związane z zapisem, tylko masz restart zaraz po ustawieniu połączenia wifi. Nigdzie nie masz zmiany ustawień

Czy mógłbyś skompilowac ostatnią wersję ze skorygowanym WifiManagerem ?

LeanderLBN, 2022-11-04:
Jeśli dobrze rozumiem, to jest to rozwiązanie tego #154 problemu?
Zatem, czy można się w jakimś przewidywalnym czasie spodziewać poprawki i nowej wersji dla tych, którzy tylko wgrywają, a nie kompilują? :)

lukaszog, 2022-11-12:
@up podbijam pytanie, mam ten sam problem. Plus po około 24h smogomierz odłącza się od sieci wtedy trzeba wyłączyć zasilanie podłączyć jeszcze raz i ręcznie wybrać sieć. Korzystam z softu z branchu dev, z mastera nic nie chciało działać :). Czy gdzieś są zapisywane logi?

hanskiepl, 2022-11-13:
[prerelease_ESP8266_Smogomierz_2.8.2_PMS_build_1.02.2022-WifiFix.bin.zip](https://github.com/hackerspace-silesia/Smogomierz/files/9998090/prerelease_ESP8266_Smogomierz_2.8.2_PMS_build_1.02.2022-WifiFix.bin.zip)
Tu macie fixa resetującego się wifi.

LeanderLBN, 2022-11-16:
> [prerelease_ESP8266_Smogomierz_2.8.2_PMS_build_1.02.2022-WifiFix.bin.zip](https://github.com/hackerspace-silesia/Smogomierz/files/9998090/prerelease_ESP8266_Smogomierz_2.8.2_PMS_build_1.02.2022-WifiFix.bin.zip) Tu macie fixa resetującego się wifi.

Super! Dziękuję, działa.

hanskiepl, 2022-11-16:
> > [prerelease_ESP8266_Smogomierz_2.8.2_PMS_build_1.02.2022-WifiFix.bin.zip](https://github.com/hackerspace-silesia/Smogomierz/files/9998090/prerelease_ESP8266_Smogomierz_2.8.2_PMS_build_1.02.2022-WifiFix.bin.zip) Tu macie fixa resetującego się wifi.
>
> Super! Dziękuję, działa.

Proszę uprzejmie :-)
Niestety pozostałych błędów to nie naprawia takich jak mqtt czy tych dziwnych linii na stronie chyba ustawień.

FilipTP, 2022-11-17:
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

Ja też dziękuję :) na problemy z wifi pomogło, ale po zalogowaniu się mogę zapisać tylko ustawienia w jednym menu (np. zmiana języka na Polski, współrzędne, czujniki itd.), ale jak próbuję potem zapisać ustawienia na które serwisy ma wysyłać otrzymane dane to się wysypuje i nie mogę się już zalogować do czujnika. Jedyne wyjście to wgranie na nowo softu gdzie znowu mogę jedynie w jednym menu i jeden raz zapisać ustawienia.. chyba przydałoby się to jakoś systemowo ogarnąć..

lukaszog, 2022-11-30:
@FilipTP wifi działa prawidłowo tak?
U mnie po aktualizacji niestety problem nadal występuje, po około 20h rozłącza.

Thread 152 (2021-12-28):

Błąd podczas wgrywania oprogramowania ESP32

mickelk, 2021-12-28:
Cześć, mam problem z ESP32, chce wgrać smogly i nie pokazuje mi się sieć wifi, po rozmowach z @bfaliszek kazał mi sprawdzić w monitorze portu szeregowego i mam taki efekt:

`rst:0x10 (RTCWDT_RTC_RESET),boot:0x13 (SPI_FAST_FLASH_BOOT)
flash read err, 1000
ets_main.c 371
ets Jun  8 2016 00:22:57`

Gdy wgram przykład z ArduinoIDE- działa, więc myśle że wgram smogly przez Arduino, przy pomocy tego poradnika, https://github.com/hackerspace-silesia/Smogomierz/blob/master/instrukcje/software.md#arduino---konfiguracja a po komplikacji dostaje info :

> Smogomierz:134:10: fatal error: src/WiFiManager/ESPAsyncWiFiManager.h: No such file or directory
 #include "src/WiFiManager/ESPAsyncWiFiManager.h" // https://github.com/alanswx/ESPAsyncWiFiManager // 5.11.2021
          ^~~~~~~~~~~~~~~~~~~~~~~~~~~~~~~~~~~~~~~
compilation terminated.
exit status 1
src/WiFiManager/ESPAsyncWiFiManager.h: No such file or directory

>

bfaliszek, 2021-12-29:
Źle zflashowana pamięć w ESP32. Używałeś do wgrania pliku .bin esptool.py czy czegoś innego?
Na szybko w google znalazłem coś takiego
"A:\> esptool.py.exe --port COM7 --baud 512000 write_flash --flash_size=detect 0x1000 .\Downloads\esp32-idf3-20210202-v1.14.bin" gdzie istotne jest 0x1000

mickelk, 2022-01-03:
Trochę czasu mi to zajęło, nie wiem czemu ale podczas wgrywania gotowego pliku bin się wysypuje. Próbowałem na 3 kompach i tylko smogomierz się wysypuje, gdy wgrywam HAA działa bez problemu.
W każdym bądź razie udało mi się przez ArduinoIDE skompilować i wgrać - działa ale mam taki problem:

[https://ibb.co/tHFSV6k](url)

zamiast temperatury wyświetla się: {TEXT_HUMIDITY}:{Humidity} %
próbowałem różnych ustawień ciągle ten sam efekt, przez zakładkę update wgrałem plik bin z wersji 2.7.1 temperatura się wyświetla prawidłowo,
więc zaktualizowałem przez plik *.bin wersje z githuba Smogly_2.8.1_build_27.11.2021 i dalej ten sam problem.

bfaliszek, 2022-01-04:
Czyli jak rozumiem problem jest tylko ustawieniami MQTT?
Brak pomiarów temp/humi pojawia się na ESP32 i poprawię to w kolejnej wersji.

mickelk, 2022-01-04:
ok, to czekam na update :)
jak dodałem urządzenie do homekit to przy PM miałem nieznane mimo iż na www pokazywało, temp była 2C i jakaś dziwna wilgotność.

bryan-pl, 2022-01-04:
To jest ciekawe, bo mam właśnie ESP32 (devkitv1) i BME280 i działa bez problemu odczyt BME i PMS, natomiast są problemy w ogóle z wgraniem firmware na esp (tylko na jednym sofcie mi się udało, żeby zadziałało) i z zapisywaniem części ustawień w konfiguracji (m.in mqtt).

bfaliszek, 2022-01-04:
Udostępniłem prerelease_ESP32_Smogomierz_2.8.2_PMS_build_4.01.2022.bin - https://github.com/hackerspace-silesia/Smogomierz/tree/dev/firmware/ESP32
Poprawiłem tam obsługę BME280 i PMSx003. Teraz powinno się poprawnie dać ustawić piny na, których są podłączone i "{TEXT_HUMIDITY}:{Humidity}" nie powinno się już pojawiać.
Przed wgraniem tego .bin zalecam kliknąć "Przywróć ustawienia domyślne"

mickelk, 2022-01-04:
Podeślesz Smogomierz.ino ?

bfaliszek, 2022-01-04:
@mickelk jest w branchu dev - https://github.com/hackerspace-silesia/Smogomierz/tree/dev tam aktualizuję wszystkie pliki przy wrzucaniu nowych testowych plików .bin

mickelk, 2022-01-04:
działa, ale w HomeKit nie pokazuje PM

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

bfaliszek, 2022-01-05:
@mickelk wiem, bo muszę trochę inaczej zrobić HomeKit. W tej bibliotece, która jest teraz używana nie ma obsługi poziomów PM. Jest już taka bardziej oficjalna i tam to działa, tylko muszę jeszcze przetestować zmienianie kodu, który jest przy parowaniu z urządzeniem Apple(żeby można było ustawić swój, a nie 111111111)

mickelk, 2022-01-06:
Jeszcze tak apropo HomeKit, przy temperaturze 0 lub mniej
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

w HomeKit wyświetla się

![Uploading B8A33D4D-D492-4C5C-8F68-BB9CCF254887.jpeg…]()

liske310, 2023-01-25:
Mam idealnie to samo... Arduino IDE jakiś przykład działa, a np. Twój program ma te same błędy co poprzednicy:
```
rst:0x10 (RTCWDT_RTC_RESET),boot:0x13 (SPI_FAST_FLASH_BOOT)
configsip: 0, SPIWP:0xee
...
```

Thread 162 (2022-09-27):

[ESP32] brak rozgłaszania WiFi po wgraniu oprogramowania

eReS72, 2022-09-27:
No niestety nie udało mi się doprowadzić do stanu, żebym widział sieć WiFi rozgłaszaną przez ESP32.
Wgrywanie softu przez NodeMCY-PyFlasher z różnymi wersjami, łącznie z prerelease 2.8.2
Próbowałem wgrać też przez esptool.exe z parametrem "write_flash --flash_size=detect 0x1000" tak jak w tym wątku:
https://github.com/hackerspace-silesia/Smogomierz/issues/152
Także bez sukcesu.
Jeśli ktoś jest w stanie pomóc i cokolwiek podpowiedzieć to będę wdzięczny.

eReS72, 2022-09-28:
Próbowałem dziś załadować soft przez Arduino wg instrukcji.
Niestey przy weryfikacji pojawia się błąd:

In file included from C:\***\Smogly\Smogomierz\Smogomierz.ino:134:
C:\***\Smogly\Smogomierz\src\WiFiManager\ESPAsyncWiFiManager.h:24:10: fatal error: ESPAsyncWebServer.h: No such file or directory
 #include <ESPAsyncWebServer.h>
          ^~~~~~~~~~~~~~~~~~~~~
compilation terminated.

exit status 1

Compilation error: ESPAsyncWebServer.h: No such file or directory

eReS72, 2022-09-28:
błąd nowicjusza - biblioteki były nierozpakowane
udało się załadować soft przez Arduino - niestety wciąż nie widzę sieci rozgłaszanej przez ESP32

Closed 2022-09-28.

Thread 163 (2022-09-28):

nieprawidłowy odczyt z BME280

eReS72, 2022-09-28:
po długich bojach z wgarniem softu teraz mam problem z odczytami z BME280

Weather:
Temperature: 2147483647 °C
Humidity: 0 %
Pressure: 2147483647 hPa
Dewpoint: 2147483647 °C
Air pollution:
PM2.5: 4 µg/m³
PM10: 4 µg/m³

Ustawienia:
Temp/Humi/Press Sensor: BME280
PM2.5/PM10 Sensor: PMS5003/7003

First Temp/Humi Sensor SDA/SCL config - BME280
Pin SDA: D18/GPIO18
Pin SCL: D19/GPIO19

PM2.5/PM10 Sensor TX/RX config - PMS7003
Pin TX: D22/GPIO22
Pin RX: D23/GPIO23

Software version: 2.8.2

eReS72, 2022-10-17:
uszkodzony czujnik - wszystko działa po wymianie

Closed 2022-10-17.

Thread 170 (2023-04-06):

Brak wifi po flashu

radziejewicz, 2023-04-06:
Cześć na esp8826 wrzuciłem ESP8266_Smogomierz_2.8.1_PMS_build_27.11.2021.bin, lecz po flashu płytka nie wstaje, brakuje wifi :/

Flashuję tak:
```
$ esptool.py -p /dev/ttyUSB0 --baud 460800 write_flash --flash_size=detect 0x1000  ESP8266_Smogomierz_2.8.1_PMS_build_27.11.2021.bin esptool.py v4.5.1
Serial port /dev/ttyUSB0
Connecting....
Detecting chip type... Unsupported detection protocol, switching and trying again...
Connecting....
Detecting chip type... ESP8266
Chip is ESP8266EX
Features: WiFi
Crystal is 26MHz
MAC: 30:83:98:85:a4:4e
Uploading stub...
Running stub...
Stub running...
Changing baud rate to 460800
Changed.
Configuring flash size...
Auto-detected Flash size: 4MB
Flash will be erased from 0x00001000 to 0x000aafff...
Compressed 695568 bytes to 461673...
Wrote 695568 bytes (461673 compressed) at 0x00001000 in 11.7 seconds (effective 473.8 kbit/s)...
Hash of data verified.

Leaving...
Hard resetting via RTS pin...
```

Ktoś podpowie co poszło nie tak?

lim3ra, 2023-04-28:
mam w sumie ten sam problem na ESP32

```
Chip is ESP32-D0WD-V3 (revision 3)
Features: WiFi, BT, Dual Core, 240MHz, VRef calibration in efuse, Coding Scheme None
Crystal is 40MHz
MAC: d4:d4:da:e5:49:20
Uploading stub...
Running stub...
Stub running...
Configuring flash size...
Auto-detected Flash size: 4MB
Erasing flash (this may take a while)...
Chip erase completed successfully in 12.7s
Compressed 1477968 bytes to 861887...
Wrote 1477968 bytes (861887 compressed) at 0x00000000 in 76.4 seconds (effective 154.8 kbit/s)...
Hash of data verified.

Leaving...
Staying in bootloader.

Firmware successfully flashed. Unplug/replug or reset device
to switch back to normal boot mode.
```

bfaliszek, 2023-04-29:
@lim3ra hej! Sprawdź kod z brancha dev - https://github.com/hackerspace-silesia/Smogomierz/tree/dev
Właśnie do skompilowałem i wgrałem na ESP32 Dev Module i łączy się z WiFi
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

lim3ra, 2023-04-29:
hey @bfaliszek , dzieki za odpowiedz

Próbowałem sflashować 2.8.3 na moje ESP32 uzywając NodeMCU PyFlasher ale niestety nic to za bardzo nie daje.

Spróbowałem też skompilować sobie brancha dev na swoim Arduino IDE ale non-stop rzuca się o jakieś dependency biblioteki np ESPAsyncWebServer.h nie wiem do końca jak sobie poradzić z ich brakiem (instalacja ESPAsyncWebSrv przez library manager'a nie pomaga)

masz jakiś pomysł czego mógłbym jeszcze spróbować?

bfaliszek, 2023-04-29:
Musisz ręcznie doinstalować brakujące biblioteki - https://github.com/hackerspace-silesia/Smogomierz/blob/master/instrukcje/software.md#arduino---konfiguracja - podpunkt 10

radziejewicz, 2023-04-29:
W razie czego brakujące libki (ja tak robiłem) pobrałem i wrzuciłem w katalog po prostu.

lim3ra, 2023-04-29:
Bardzo dziękuję za pomoc @bfaliszek, wszystko działa

bfaliszek, 2023-04-30:
@lim3ra czyli kod z brancha dev u Ciebie na ESP32? Czyli zostaje kwestia ESP8266. Problem w tym, że nie mam żadnego ESP8266, ale poszukam i postaram się to ogarnąć.
Jestem też w połowie refactoringu kodu Smogomierza. Chcę to skończyć w przyszłym tygodniu i poprawić znane błędy.

lim3ra, 2023-04-30:
> @lim3ra czyli kod z brancha dev u Ciebie na ESP32? Czyli zostaje kwestia ESP8266. Problem w tym, że nie mam żadnego ESP8266, ale poszukam i postaram się to ogarnąć.
>
> Jestem też w połowie refactoringu kodu Smogomierza. Chcę to skończyć w przyszłym tygodniu i poprawić znane błędy.

Hej, tak mogę potwierdzić, ze na ESP32 wszystko się kompiluje i wgrywa bez problemu. Działa tez wsparcie dla HomeKit.

radziejewicz, 2023-05-03:
O dzięki za fix, w sumie już też namierzyłem i poprawiłem w kodzie :)

Co do refactoringu - to będziesz poprawiać błędy, czy dojdzie coś nowego?

lim3ra, 2023-05-03:
> Na razie przepisuję ten kod, który jest tak strasznie napisany, że aż wstyd mi na niego patrzeć. Większość już przepisałem na nowo. Chcę jeszcze poprawić błędy, które znajdę. Na razie nie planuję żadnych nowych funkcjonalności

Przy okazji - dzięki za Twoją pracę @bfaliszek

świetny projekt, ja korzystam już od kilku lat

lipszczak, 2023-06-10:
Hej,
U mnie na ESP32 po flashu przez NodeMCU Pyflasher również nie pojawia się WiFi.
W Arduino IDE jak próbuję samemu skompilować program to sypie błędami:
In file included from C:\Users\xxx\Documents\Smogomierz\Smogomierz.ino:556:
C:\Users\xxx\Documents\Smogomierz\src\smogly_asyncwebserver.h: In function 'String handle_root_processor(const String&)':
C:\Users\xxx\Documents\Smogomierz\src\smogly_asyncwebserver.h:94:3: error: 'takeTHPMeasurements' was not declared in this scope
   takeTHPMeasurements();
   ^~~~~~~~~~~~~~~~~~~
C:\Users\xxx\Documents\Smogomierz\src\smogly_asyncwebserver.h:94:3: note: suggested alternative: 'pmMeasurements'
   takeTHPMeasurements();
   ^~~~~~~~~~~~~~~~~~~
   pmMeasurements
In file included from C:\Users\xxx\Documents\Smogomierz\Smogomierz.ino:556:
C:\Users\xxx\Documents\Smogomierz\src\smogly_asyncwebserver.h: In function 'void handle_adv_mqtt_config(AsyncWebServerRequest*)':
C:\Users\xxx\Documents\Smogomierz\src\smogly_asyncwebserver.h:2044:5: error: 'takeTHPMeasurements' was not declared in this scope
     takeTHPMeasurements();
     ^~~~~~~~~~~~~~~~~~~
C:\Users\xxx\Documents\Smogomierz\src\smogly_asyncwebserver.h:2044:5: note: suggested alternative: 'pmMeasurements'
     takeTHPMeasurements();
     ^~~~~~~~~~~~~~~~~~~
     pmMeasurements
C:\Users\xxx\Documents\Smogomierz\src\smogly_asyncwebserver.h: In function 'void handle_api(AsyncWebServerRequest*)':
C:\Users\xxx\Documents\Smogomierz\src\smogly_asyncwebserver.h:3267:5: error: 'takeTHPMeasurements' was not declared in this scope
     takeTHPMeasurements();
     ^~~~~~~~~~~~~~~~~~~
C:\Users\xxx\Documents\Smogomierz\src\smogly_asyncwebserver.h:3267:5: note: suggested alternative: 'pmMeasurements'
     takeTHPMeasurements();
     ^~~~~~~~~~~~~~~~~~~
     pmMeasurements
C:\Users\xxx\Documents\Smogomierz\Smogomierz.ino: At global scope:
C:\Users\xxx\Documents\Smogomierz\Smogomierz.ino:1078:3: error: expected unqualified-id before 'if'
   if (need_update == true && deviceSettings.autoUpdate) {
   ^~
C:\Users\xxx\Documents\Smogomierz\Smogomierz.ino:1086:10: error: expected constructor, destructor, or type conversion before ';' token
   yield();
          ^
C:\Users\xxx\Documents\Smogomierz\Smogomierz.ino:1088:19: error: expected constructor, destructor, or type conversion before ';' token
   pm_calibration();
                   ^
C:\Users\xxx\Documents\Smogomierz\Smogomierz.ino:1091:3: error: expected unqualified-id before 'if'
   if (!strcmp(sensorsSettings.dustModel, "PMS7003")) {
   ^~
C:\Users\xxx\Documents\Smogomierz\Smogomierz.ino:1112:3: error: expected unqualified-id before 'if'
   if (strcmp(sensorsSettings.dustModel, "Non")) {
   ^~
C:\Users\xxx\Documents\Smogomierz\Smogomierz.ino:1169:5: error: expected unqualified-id before 'else'
   } else {
     ^~~~
C:\Users\xxx\Documents\Smogomierz\Smogomierz.ino:1205:3: error: expected unqualified-id before 'if'
   if (airMonitorSettings.enabled) {
   ^~
C:\Users\xxx\Documents\Smogomierz\Smogomierz.ino:1215:3: error: expected unqualified-id before 'if'
   if (luftdatenSettings.enabled or aqiEcoSettings.enabled or smoglistSettings.enabled) {
   ^~
C:\Users\xxx\Documents\Smogomierz\Smogomierz.ino:1224:3: error: expected unqualified-id before 'if'
   if (thingSpeakSettings.enabled or influxDBSettings.enabled or mqttSettings.enabled) {
   ^~
C:\Users\xxx\Documents\Smogomierz\Smogomierz.ino:1235:3: error: expected unqualified-id before 'if'
   if (current_REBOOT_Millis - intervals.previousRebootMillis >= intervals.reboot) {
   ^~
C:\Users\xxx\Documents\Smogomierz\Smogomierz.ino:1263:1: error: expected declaration before '}' token
 }  // loop() - END
 ^

exit status 1

Compilation error: 'takeTHPMeasurements' was not declared in this scope

lipszczak, 2023-06-10:
Odpowiem sam do siebie.
U mnie flashowanie przez NodeMCU Pyflasher z pliku bin nie działało. Ten sam plik bin, wgrany przez ESPHomeflasher, na tę samą płytkę działa. Nie jestem specem, ale czytałem że NodeMCU nie wgrywa niezbędnych danych bootloadera, więc wgrywając z pliku bin, musimy mieć w pliku binarnym te brakującą część. ESPHomeflasher wgrywa tę część dump (czy jakoś tak) z automatu.
Teraz walczę z ustawieniami, żeby wyświetlało wyniki pomiarów, bo mój smogomierz póki co pokazuje same 0

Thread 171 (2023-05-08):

ESP32 flashed devices dont work

andygodber, 2023-05-08:
Apologies for writing in English.
Im unable to use the ESP32 image on any devices.
I have used the NodeMCU-pyFlasher and a selection of different ESP32 .bin files (inc pre-release 2.8.3).
The files appear to be written by the flash tool, as the % indicator increases and says completed successfully; the tool reports the connected ESP as ESP32-D0WDQ6-V3.
If I look at the serial output in Arduino IDE, it seems to be in a boot-loop:

invalid header: 0x55544954
inva�ets Jul 29 2019 12:21:46

rst:0x10 (RTCWDT_RTC_RESET),boot:0x13 (SPI_FAST_FLASH_BOOT)
invalid header: 0x55544954
invalid header: 0x55544954
invalid header: 0x55544954
invalid header: 0x55544954
invalid header: 0x55544954
invalid header: 0x55544954
invalid header: 0x55544954
invaets Jul 29 2019 12:21:46

(I have successfully flashed and used the 8266 version.)

andygodber, 2023-05-08:
Confirmed that I tied with the pre-release.

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

Im also having trouble trying to complile from the code (missing some libraries - I added BME280 from Ada (as well as BMP) but still showing an error with bmeStatus as not being defined).

lipszczak, 2023-06-11:
Try to flash .bin with ESPHomeflasher. I had the same issue with NodeMCU flasher.

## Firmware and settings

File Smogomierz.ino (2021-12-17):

/*
  ESP8266 core for Arduino - 3.0.2 // NodeMCU 1.0; Flash Size: 4MB (FS:1MB OTA:~1019KB)
  Arduino core for the ESP32 - 1.0.6!! // 2.0.0 NOT SUPPORTED!

  Adafruit Unified Sensor - 1.1.4
  DallasTemperature - 3.8.0
*/

// ****** CHOOSE(uncomment) ONLY ONE!!! ******

#define INTL_OLD  // old translataion system
// #define INTL_PL  // polish translataion // EXPERIMENTAL!
// #define INTL_EN  // english translataion // EXPERIMENTAL!

// *******************************************

// ****** CHOOSE(uncomment) ONLY ONE!!! ******

#define DUSTSENSOR_PMS5003_7003_BME280_0x76 // PMS5003 / PMS7003 - BME280_0x76
// #define DUSTSENSOR_PMS5003_7003_BME280_0x77 // PMS5003 / PM§S7003 - BME280_0x77
// #define DUSTSENSOR_SDS011_21 // Nova Fitness SDS011 / SDS021
// #define DUSTSENSOR_HPMA115S0 // Honeywell HPMA115S0
// #define DUSTSENSOR_SPS30 // Sensirion SPS30

// *******************************************

#define ASYNC_WEBSERVER_ON
#define DISABLE_SMOGLIST

/*

   ESP8266

  Podłączenie czujnikow dla ESP8266 NodeMCU:
  BME280/BMP280: VIN - 3V; GND - G; SCL - D4; SDA - D3
  SHT1x: VIN - 3V; GND - G; SCL - D5; DATA/SDA - D6 wymaga rezystora 10k podłaczonego do VCC
  SHT21/HTU21D: VIN - 3V; GND - G; SCL - D5; SDA - D6
  DHT22: VIN - 3V; GND - G; D7
  DS18B20: VIN - 3V; GND - G; D5 - 4.7k Ohm resistor!
  PMS5003/7003: VIN - VIN/5V; GND - G; Zielony/TX - D1; Niebieski/RX - D2
  HPMA115S0: VIN - VIN/5V; GND - G; TX - D1; RX - D2
  SDS011/21: VIN - 5V; GND - G; TX - D1; RX - D2
  Sensirion SPS30: VIN - 5V; GND - G; TX - D1; RX - D2

  Connection of sensors on ESP8266 NodeMCU:
  BME280/BMP280: VIN - 3V; GND - G; SCL - D4; SDA - D3
  SHT1x: VIN - 3V; GND - G; SCL - D5; DATA/SDA - D6 required pull-up resistor 10k to VCC
  SHT21/HTU21D: VIN - 3V; GND - G; SCL - D5; SDA - D6
  DHT22: VIN - 3V; GND - G; D7
  DS18B20: VIN - 3V; GND - G; D5 - 4.7k Ohm resistor!
  PMS5003/7003: VIN - VIN/5V; GND - G; Green/TX - D1; Blue/RX - D2
  HPMA115S0: VIN - VIN/5V; GND - G; TX - D1; RX - D2
  SDS011/21: VIN - 5V; GND - G; TX - D1; RX - D2
  Sensirion SPS30: VIN - 5V; GND - G; TX - D1; RX - D2


   ESP32

  Podłączenie czujnikow dla ESP32:
  BME280/BMP280: VIN - 3V; GND - G; SCL - D17; SDA - D16
  SHT1x: VIN - 3V; GND - G; SCL - D5; DATA/SDA - D6 wymaga rezystora 10k podłaczonego do VCC
  SHT21/HTU21D: VIN - 3V; GND - G; SCL - D5; SDA - D6
  DHT22: VIN - 3V; GND - G; D7
  DS18B20: VIN - 3V; GND - G; D5 - 4.7k Ohm resistor!
  PMS5003/7003: VIN - VIN/5V; GND - G; TX - D5; RX - D4
  HPMA115S0: VIN - VIN/5V; GND - G; TX - D1; RX - D2
  SDS011/21: VIN - 5V; GND - G; TX - D5; RX - D4
  Sensirion SPS30: VIN - 5V; GND - G; TX - D5; RX - D4

  Connection of sensors on ESP32:
  BME280/BMP280: VIN - 3V; GND - G; SCL - D17; SDA - D16
  SHT1x: VIN - 3V; GND - G; SCL - D5; DATA/SDA - D6 required pull-up resistor 10k to VCC
  SHT21/HTU21D: VIN - 3V; GND - G; SCL - D5; SDA - D6
  DHT22: VIN - 3V; GND - G; D7
  DS18B20: VIN - 3V; GND - G; D5 - 4.7k Ohm resistor!
  PMS5003/7003: VIN - VIN/5V; GND - G; TX - D5; RX - D4
  HPMA115S0: VIN - VIN/5V; GND - G; TX - D1; RX - D2
  SDS011/21: VIN - 5V; GND - G; TX - D5; RX - D4
  Sensirion SPS30: VIN - 5V; GND - G; TX - D5; RX - D4
*/

/*
  ESP8266 PMS7003/BME280_0x76 - NodeMCU 1.0 - 1M SPIFFS --- FS:1MB OTA: ~1019KB

  Szkic używa 580548 bajtów (55%) pamięci programu. Maksimum to 1044464 bajtów.
  Zmienne globalne używają 45888 bajtów (56%) pamięci dynamicznej, pozostawiając 36032 bajtów dla zmiennych lokalnych. Maksimum to 81920 bajtów.

  ASYNC_WEBSERVER_ON + INTL_OLD

  Szkic używa 694529 bajtów (66%) pamięci programu. Maksimum to 1044464 bajtów.
  Zmienne globalne używają 46688 bajtów (56%) pamięci dynamicznej, pozostawiając 35232 bajtów dla zmiennych lokalnych. Maksimum to 81920 bajtów.

  Szkic używa 695897 bajtów (66%) pamięci programu. Maksimum to 1044464 bajtów.
  Zmienne globalne używają 46800 bajtów (57%) pamięci dynamicznej, pozostawiając 35120 bajtów dla zmiennych lokalnych. Maksimum to 81920 bajtów.

  Szkic używa 691393 bajtów (66%) pamięci programu. Maksimum to 1044464 bajtów.
  Zmienne globalne używają 46876 bajtów (57%) pamięci dynamicznej, pozostawiając 35044 bajtów dla zmiennych lokalnych. Maksimum to 81920 bajtów.

  ASYNC_WEBSERVER_ON + INTL_PL

  Szkic używa 662541 bajtów (63%) pamięci programu. Maksimum to 1044464 bajtów.
  Zmienne globalne używają 40528 bajtów (49%) pamięci dynamicznej, pozostawiając 41392 bajtów dla zmiennych lokalnych. Maksimum to 81920 bajtów.


  ================================================================================================================================================

  ESP32 Dev Module PMS7003/BME280_0x76 - 1.9MB APP with OTA - 190KB SPIFFS

  Szkic używa 1375786 bajtów (69%) pamięci programu. Maksimum to 1966080 bajtów.
  Zmienne globalne używają 58664 bajtów (17%) pamięci dynamicznej, pozostawiając 269016 bajtów dla zmiennych lokalnych. Maksimum to 327680 bajtów.

  Szkic używa 1377866 bajtów (70%) pamięci programu. Maksimum to 1966080 bajtów.
  Zmienne globalne używają 58656 bajtów (17%) pamięci dynamicznej, pozostawiając 269024 bajtów dla zmiennych lokalnych. Maksimum to 327680 bajtów.

  *** init homekit support:

  Szkic używa 1543130 bajtów (78%) pamięci programu. Maksimum to 1966080 bajtów.
  Zmienne globalne używają 60808 bajtów (18%) pamięci dynamicznej, pozostawiając 266872 bajtów dla zmiennych lokalnych. Maksimum to 327680 bajtów.

  ASYNC_WEBSERVER_ON

  Szkic używa 1477490 bajtów (75%) pamięci programu. Maksimum to 1966080 bajtów.
  Zmienne globalne używają 58976 bajtów (17%) pamięci dynamicznej, pozostawiając 268704 bajtów dla zmiennych lokalnych. Maksimum to 327680 bajtów.

  Szkic używa 1477750 bajtów (75%) pamięci programu. Maksimum to 1966080 bajtów.
  Zmienne globalne używają 59024 bajtów (18%) pamięci dynamicznej, pozostawiając 268656 bajtów dla zmiennych lokalnych. Maksimum to 327680 bajtów.

*/

#include <Arduino.h>
#include "FS.h"
#include <ArduinoJson.h> // 6.9.0 or later
#ifdef ASYNC_WEBSERVER_ON
#include "src/WiFiManager/ESPAsyncWiFiManager.h" // https://github.com/alanswx/ESPAsyncWiFiManager // 5.11.2021
#else
#include "src/WiFiManager/WiFiManager.h" // https://github.com/tzapu/WiFiManager/tree/development // 5.11.2021 DEV
#endif
#ifdef ARDUINO_ARCH_ESP8266
#ifndef DUSTSENSOR_PMS5003_7003_BME280_0x77
#include "src/libs/esp8266/bme280_0x76.h" // https://github.com/zen/BME280_light // CUSTOMIZED! 5.11.2021
#else
#include "src/libs/esp8266/bme280_0x77.h" // https://github.com/zen/BME280_light // CUSTOMIZED! 5.11.2021
#endif
#elif defined ARDUINO_ARCH_ESP32
#include "src/libs/esp32/Adafruit_BME280.h" // https://github.com/Takatsuki0204/BME280-I2C-ESP32 // 5.11.2021
#endif

#include "src/libs/HTU2xD_SHT2x_Si70xx.h" // https://github.com/enjoyneering/HTU2xD_SHT2x_Si70xx // 5.11.2021
#include "src/libs/Adafruit_BMP280.h" // https://github.com/adafruit/Adafruit_BMP280_Library // 5.11.2021
#include "src/libs/SHT1x.h" // https://github.com/practicalarduino/SHT1x // 5.11.2021
#include "src/libs/DHT.h" // https://github.com/adafruit/DHT-sensor-library // 5.11.2021

#ifdef DUSTSENSOR_PMS5003_7003_BME280_0x76 or DUSTSENSOR_PMS5003_7003_BME280_0x77
#include "src/libs/pms.h" // https://github.com/fu-hsi/PMS // 5.11.2021
#elif defined DUSTSENSOR_SDS011_21
#ifdef ARDUINO_ARCH_ESP8266
#include "src/libs/esp8266/SdsDustSensor.h" // SDS011/SDS021 - https://github.com/lewapek/sds-dust-sensors-arduino-library // 5.11.2021
#elif defined ARDUINO_ARCH_ESP32
// #include "src/libs/esp8266/SdsDustSensor.h" // SDS011/SDS021 - https://github.com/lewapek/sds-dust-sensors-arduino-library // 5.11.2021
#include "src/libs/esp32/SDS011.h" // https://github.com/ricki-z/SDS011 // 5.11.2021
#endif
#elif defined DUSTSENSOR_HPMA115S0
#include "src/libs/hpma115S0.h" // https://github.com/hpsaturn/HPMA115S0 // 5.11.2021
#elif defined DUSTSENSOR_SPS30
#include "src/libs/sps30.h" // https://github.com/paulvha/sps30 // CUSTOMIZED! 5.11.2021
#else // If no dust sensor has been defined - use DUSTSENSOR_PMS5003_7003_BME280_0x76
#include "src/libs/pms.h" // https://github.com/fu-hsi/PMS // 5.11.2021
#endif

#include "src/smogly_spiffs.h"
#include "config.h"
#include "defaultConfig.h"

#include "src/autoupdate.h"

#ifndef DISABLE_SMOGLIST
#include "src/services/smoglist.h"
#endif
#include "src/services/luftdaten.h"
#ifdef ARDUINO_ARCH_ESP32
#include "src/services/airmonitor.h"
#endif
#include "src/services/thing_speak.h"
#include "src/services/aqieco.h"
#include "src/services/InfluxDbV2.h" // https://github.com/davidgs/ESP8266_Influx_DB_V2 // CUSTOMIZED! 5.11.2021

//        it would be nice to update the InfluxDB library to
// #include "src/services/InfluxDB/InfluxDbClient.h" // https://github.com/tobiasschuerg/InfluxDB-Client-for-Arduino

#ifdef ARDUINO_ARCH_ESP8266 // ESP8266 core for Arduino - 2.6.3 or later
#ifdef ASYNC_WEBSERVER_ON
#include <ESPAsyncTCP.h>
#include <ESPAsyncWebServer.h>
#else
#include <ESP8266WebServer.h>
#endif
#include <ESP8266mDNS.h>
#ifndef ASYNC_WEBSERVER_ON
#include <ESP8266HTTPUpdateServer.h>
#endif
#include <SoftwareSerial.h>
#elif defined ARDUINO_ARCH_ESP32 // Arduino core for the ESP32 - 1.0.4-rc1 or later // at 1.0.3 autoupdate doesn't work !!!
#include <WiFi.h>
#include <WiFiClient.h>
#include <ESPmDNS.h>
#ifdef ASYNC_WEBSERVER_ON
#include <AsyncTCP.h>
#include <ESPAsyncWebServer.h>
#else
#include <WebServer.h>
#endif
#include <Update.h>
#include <HTTPClient.h>
#include <HTTPUpdate.h>
#include <time.h>
#include <HardwareSerial.h>
#endif

#include <PubSubClient.h>
#include <Wire.h>
#include <OneWire.h>
#include <DallasTemperature.h>

// TEMP/HUMI/PRESS Sensor config - START
// BME280 config
#ifdef ARDUINO_ARCH_ESP8266 // VIN - 3V; GND - G; SCL - D4; SDA - D3
#define ASCII_ESC 27
char bufout[10];
BME280<> BMESensor;
BME280<> BMESensor_2;
#elif defined ARDUINO_ARCH_ESP32 // VIN - 3V; GND - G; SCL - D17; SDA - D16
//#define I2C_SDA = FIRST_THP_SDA
//#define I2C_SCL = FIRST_THP_SCL
Adafruit_BME280 bme((uint8_t)FIRST_THP_SDA, (uint8_t)FIRST_THP_SCL); // I2C -- ONLY THE DEFAULT VALUES WORK
#endif

// BMP280 config
Adafruit_BMP280 bmp; //I2C

// Serial for SHT21/HTU21D config
// HTU21D  myHTU21D(HTU21D_RES_RH12_TEMP14);
HTU2xD_SHT2x_SI70xx ht2x(HTU2xD_SENSOR, HUMD_12BIT_TEMP_14BIT); //sensor type, resolution

// DHT22 config
//#define DHTPIN 13 // D7 on NodeMCU/WeMos board
#define DHTTYPE DHT22   // DHT 22  (AM2302), AM2321
DHT dht(FIRST_THP_SDA, DHTTYPE);

// SHT1x – Config
//#define dataPin 14 //D5
//#define clockPin 12 //D6
SHT1x sht1x(FIRST_THP_SDA, FIRST_THP_SCL);

// DS18B20 – Config
//const int DS18B20_WireBus = 14; // D5
//OneWire oneWire(FIRST_THP_SDA);
OneWire oneWire(14);
DallasTemperature DS18B20(&oneWire);
// TEMP/HUMI/PRESS Sensor config - END

// DUST Sensor config - START

#ifdef DUSTSENSOR_PMS5003_7003_BME280_0x76 or DUSTSENSOR_PMS5003_7003_BME280_0x77
//***PMSx003 - START***
#ifdef ARDUINO_ARCH_ESP8266
#ifdef ARDUINO_ESP8266_RELEASE_2_6_0
SoftwareSerial PMS_Serial; // only for esp8266 core 2.6.0
#else
SoftwareSerial PMS_Serial(DUST_TX, DUST_RX); // Change TX - D1 and RX - D2 pins -- esp8266 core 2.6.1 or later
#endif
PMS pms(PMS_Serial);
PMS::DATA data;
#elif defined ARDUINO_ARCH_ESP32
HardwareSerial PMS_Serial(1); // Change TX - D5 and RX - D4 pins
PMS pms(PMS_Serial);
PMS::DATA data;
#endif
//***PMSx003 - END***
#elif defined DUSTSENSOR_SDS011_21
//***SDS0x1 - START***
#ifdef ARDUINO_ARCH_ESP8266
// SDS011/21 config
SdsDustSensor sds(DUST_TX, DUST_RX); // Change TX - D1 and RX - D2 pins
#elif defined ARDUINO_ARCH_ESP32
// SDS011/21 config
HardwareSerial sds_port(2); // Change TX - D5 and RX - D4 pins
SDS011 my_sds;
int err;
float SDSpm25, SDSpm10;
#endif
//***SDS0x1 - END***
#elif defined DUSTSENSOR_HPMA115S0
//***HPMA115S0 - START***
#ifdef ARDUINO_ARCH_ESP8266
SoftwareSerial hpmaSerial(DUST_TX, DUST_RX); // TX/RX – D1/D2
HPMA115S0 hpma115S0(hpmaSerial);
#elif defined ARDUINO_ARCH_ESP32
HardwareSerial hpmaSerial(1); // Change TX - D5 and RX - D4 pins
HPMA115S0 hpma115S0(hpmaSerial);
#endif
unsigned int hpma115S0_pm25, hpma115S0_pm10;
//***HPMA115S0 - END***
#elif defined DUSTSENSOR_SPS30
//***SPS30 - START***
#ifdef ARDUINO_ARCH_ESP8266
#define SP30_COMMS I2C_COMMS
#elif defined ARDUINO_ARCH_ESP32
#define SP30_COMMS SERIALPORT1
#endif
#define SPS30_AUTOCLEANINTERVAL -1
#define SPS30_PERFORMCLEANNOW 1
#define SPS30_DEBUG 0
// function prototypes (sometimes the pre-processor does not create prototypes themself on ESPxx)
void ErrtoMess(char *mess, uint8_t r);
void Errorloop(char *mess, uint8_t r);
void GetDeviceInfo();
bool read_sps30_data();
// create constructor
SPS30 sps30;
float SPS30_PM1, SPS30_PM25, SPS30_PM4, SPS30_PM10;
//***SPS30 - END***
#else // If no dust sensor has been defined - use DUSTSENSOR_PMS5003_7003_BME280_0x76
//***PMSx003 - START***
#ifdef ARDUINO_ARCH_ESP8266
#ifdef ARDUINO_ESP8266_RELEASE_2_6_0
SoftwareSerial PMS_Serial; // only for esp8266 core 2.6.0
#else
SoftwareSerial PMS_Serial(DUST_TX, DUST_RX); // Change TX - D1 and RX - D2 pins -- esp8266 core 2.6.1 or later
#endif
PMS pms(PMS_Serial);
PMS::DATA data;
#elif defined ARDUINO_ARCH_ESP32
HardwareSerial PMS_Serial(1); // Change TX - D5 and RX - D4 pins
PMS pms(PMS_Serial);
PMS::DATA data;
#endif
//***PMSx003 - END***
#endif

// DUST Sensor config - END

static char device_name[20];

static unsigned int DUST_interval = 60 * 1000; // 1 minute
unsigned int previous_DUST_Millis = 0;
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
void loop() {
  /*
    Serial.print(F("========================================\n"));
    Serial.println(F("Free Heap: " + String(ESP.getFreeHeap())));
    Serial.print(F("========================================\n"));
  */

  if (need_update == true && AUTOUPDATE_ON) {
    for (int i = 0; i < 5 ; i++) {
      unsigned char x = 0;
      doUpdate(x);

#ifdef ASYNC_WEBSERVER_ON
      yield();
      delay(1000);

#else
      delay(1000);
#endif

    }
  }

  yield();

  pm_calibration();

  // DUST SENSOR refresh data - START
#ifdef DUSTSENSOR_PMS5003_7003_BME280_0x76 or DUSTSENSOR_PMS5003_7003_BME280_0x77
  if (!strcmp(DUST_MODEL, "PMS7003")) {
    pms.read(data);
  }
#elif defined DUSTSENSOR_SDS011_21
#ifdef ARDUINO_ARCH_ESP8266
  PmResult SDSdata = sds.queryPm();
#endif
#elif defined DUSTSENSOR_HPMA115S0
#elif defined DUSTSENSOR_SPS30
  //read_sps30_data();
#else // If no dust sensor has been defined - use DUSTSENSOR_PMS5003_7003_BME280_0x76
  if (!strcmp(DUST_MODEL, "PMS7003")) {
    pms.read(data);
  }
#endif
  // DUST SENSOR refresh data - END

#ifndef ASYNC_WEBSERVER_ON
  WebServer.handleClient();
#endif

#ifdef ARDUINO_ARCH_ESP8266
  MDNS.update();
#endif

  if (strcmp(DUST_MODEL, "Non")) {
    unsigned int current_DUST_Millis = millis();
    if (FREQUENTMEASUREMENT == true ) {
      if (current_DUST_Millis - previous_DUST_Millis >= DUST_interval) {
        if (DEBUG) {
#ifdef ARDUINO_ARCH_ESP8266
          Serial.println(F("\nFREQUENT MEASUREMENT Mode!"));
#elif defined ARDUINO_ARCH_ESP32
          Serial.println(("\nFREQUENT MEASUREMENT Mode!"));
#endif
        }
        takeNormalnPMMeasurements();
        previous_DUST_Millis = millis();
      }
    }
    if (DEEPSLEEP_ON == true) {
      if (DEBUG) {
#ifdef ARDUINO_ARCH_ESP8266
        Serial.println(F("\nDeepSleep Mode!"));
#elif defined ARDUINO_ARCH_ESP32
        Serial.println(("\nDeepSleep Mode!"));
#endif
      }
      takeSleepPMMeasurements();
      yield();

      if (LUFTDATEN_ON or AQI_ECO_ON or AIRMONITOR_ON or SMOGLIST_ON) {
        takeTHPMeasurements();
        sendDataToExternalServices();
      }
      if (THINGSPEAK_ON or INFLUXDB_ON or MQTT_ON) {
        takeTHPMeasurements();
        sendDataToExternalDBs();
      }

#ifdef ARDUINO_ARCH_ESP8266
      Serial.println(F("Going into deep sleep for ") + String(SENDING_FREQUENCY) + F(" minutes!"));
      Serial.flush();
      ESP.deepSleep(SENDING_FREQUENCY * 60 * 1000000); // *1000000 - secunds

      yield();

#elif defined ARDUINO_ARCH_ESP32
      Serial.println(("Going to sleep now"));
      Serial.flush();
      esp_deep_sleep_start();
#endif

    } else {
      if (current_DUST_Millis - previous_DUST_Millis >= DUST_interval) {
        if (DEBUG) {
#ifdef ARDUINO_ARCH_ESP8266
          Serial.println(F("\nNormal Mode!"));
#elif defined ARDUINO_ARCH_ESP32
          Serial.println(("\nNormal Mode!"));
#endif
        }
        takeSleepPMMeasurements();
        previous_DUST_Millis = millis();
      }
    }
  } else {
    if (DEEPSLEEP_ON == true) {
#ifdef ARDUINO_ARCH_ESP8266
      Serial.println(F("\nDeepSleep Mode!\n"));
#elif defined ARDUINO_ARCH_ESP32
      Serial.println(("\nDeepSleep Mode!\n"));
#endif
      unsigned int current_2sec_Millis = millis();
      previous_2sec_Millis = millis();
      while (previous_2sec_Millis - current_2sec_Millis <= TwoSec_interval * 10) {
#ifndef ASYNC_WEBSERVER_ON
        WebServer.handleClient();
#endif
        previous_2sec_Millis = millis();
      }
      if (LUFTDATEN_ON or AQI_ECO_ON or AIRMONITOR_ON or SMOGLIST_ON) {
        takeTHPMeasurements();
        sendDataToExternalServices();
      }
      if (THINGSPEAK_ON or INFLUXDB_ON or MQTT_ON) {
        takeTHPMeasurements();
        sendDataToExternalDBs();
      }

      yield();

#ifdef ARDUINO_ARCH_ESP8266
      Serial.println(F("Going into deep sleep for ") + String(SENDING_FREQUENCY) + F(" minutes!"));
      Serial.flush();
      ESP.deepSleep(SENDING_FREQUENCY * 60 * 1000000); // *1000000 - secunds
      yield();
#elif defined ARDUINO_ARCH_ESP32
      Serial.println(("Going to sleep now"));
      Serial.flush();
      esp_deep_sleep_start();
#endif

    }
  }

  if (AIRMONITOR_ON) {
    // Serial.println("SENDING_FREQUENCY_AIRMONITOR_interval: " + String(SENDING_FREQUENCY_AIRMONITOR_interval));
    // Serial.println("previous_SENDING_FREQUENCY_AIRMONITOR_Millis: " + String(previous_SENDING_FREQUENCY_AIRMONITOR_Millis));

    unsigned int current_SENDING_FREQUENCY_AIRMONITOR_Millis = millis();
    // Serial.println("current_SENDING_FREQUENCY_AIRMONITOR_Millis: " + String(current_SENDING_FREQUENCY_AIRMONITOR_Millis));

    if (current_SENDING_FREQUENCY_AIRMONITOR_Millis - previous_SENDING_FREQUENCY_AIRMONITOR_Millis >= SENDING_FREQUENCY_AIRMONITOR_interval) {
      takeTHPMeasurements();
      // Serial.println("SEND DATA TO AIRMONITOR");
      sendDataToExternalServices();
      previous_SENDING_FREQUENCY_AIRMONITOR_Millis = millis();
    }
  }

  if (LUFTDATEN_ON or AQI_ECO_ON or SMOGLIST_ON) {
    unsigned int current_SENDING_FREQUENCY_Millis = millis();
    if (current_SENDING_FREQUENCY_Millis - previous_SENDING_FREQUENCY_Millis >= SENDING_FREQUENCY_interval) {
      takeTHPMeasurements();
      sendDataToExternalServices();
      previous_SENDING_FREQUENCY_Millis = millis();
    }
  }

  if (THINGSPEAK_ON or INFLUXDB_ON or MQTT_ON) {
    unsigned int current_SENDING_DB_FREQUENCY_Millis = millis();
    if (current_SENDING_DB_FREQUENCY_Millis - previous_SENDING_DB_FREQUENCY_Millis >= SENDING_DB_FREQUENCY_interval) {
      takeTHPMeasurements();
      sendDataToExternalDBs();
      previous_SENDING_DB_FREQUENCY_Millis = millis();
    }
  }

  unsigned int current_REBOOT_Millis = millis();
  if (current_REBOOT_Millis - previous_REBOOT_Millis >= REBOOT_interval) {
#ifdef ARDUINO_ARCH_ESP8266
    Serial.println(F("autoreboot..."));
#elif defined ARDUINO_ARCH_ESP32
    Serial.println(("autoreboot..."));
#endif
    delay(1000);
    previous_REBOOT_Millis = millis();

#ifdef ARDUINO_ARCH_ESP8266
    ESP.reset();
#elif defined ARDUINO_ARCH_ESP32
    ESP.restart();
#endif

    delay(5000);
  }

  /*
    unsigned int current_SENDING_FREQUENCY_Millis = millis();
    if (current_SENDING_FREQUENCY_Millis - previous_SENDING_FREQUENCY_Millis >= SENDING_FREQUENCY_interval) {
    #ifdef ARDUINO_ARCH_ESP32
      if (HOMEKIT_SUPPORT) {
        homekit_DeviceData.homekit_temperature = float(random(-11.00, 45));
        homekit_DeviceData.homekit_humidity = float(random(0.0, 99));
        homekit_DeviceData.homekit_pm10_level = int(random(0, 3000));
        homekit_DeviceData.homekit_pm25_level = int(random(0, 2000));
        notify_hap();
      }
    #endif
      previous_SENDING_FREQUENCY_Millis = millis();
    }
  */

} // loop() - END

void sendDataToExternalServices() {

  if (LUFTDATEN_ON) {
    sendDataToLuftdaten(currentTemperature, currentPressure, currentHumidity, averagePM1, averagePM25, averagePM4, averagePM10);
    if (DEBUG) {
#ifdef ARDUINO_ARCH_ESP8266
      Serial.println(F("Sending measurement data to the LuftDaten service!\n"));
#elif defined ARDUINO_ARCH_ESP32
      Serial.println(("Sending measurement data to the LuftDaten service!\n"));
#endif
    }
  }

#ifdef ARDUINO_ARCH_ESP32
  if (AIRMONITOR_ON) {
    sendDataToAirMonitor(currentTemperature, currentPressure, currentHumidity, averagePM1, averagePM25, averagePM4, averagePM10);
    if (DEBUG) {
#ifdef ARDUINO_ARCH_ESP8266
      Serial.println(F("Sending measurement data to the AirMonitor service!\n"));
#elif defined ARDUINO_ARCH_ESP32
      Serial.println(("Sending measurement data to the AirMonitor service!\n"));
#endif
    }
  }
#endif

#ifndef DISABLE_SMOGLIST
  if (SMOGLIST_ON) {
    sendDataToSmoglist(currentTemperature, currentPressure, currentHumidity, averagePM1, averagePM25, averagePM4, averagePM10);
    if (DEBUG) {
#ifdef ARDUINO_ARCH_ESP8266
      Serial.println(F("Sending measurement data to the Smoglist service!\n"));
#elif defined ARDUINO_ARCH_ESP32
      Serial.println(("Sending measurement data to the Smoglist service!\n"));
#endif
    }
  }
#endif

  if (AQI_ECO_ON) {
    sendDataToAqiEco(currentTemperature, currentPressure, currentHumidity, averagePM1, averagePM25, averagePM4, averagePM10);
    if (DEBUG) {
#ifdef ARDUINO_ARCH_ESP8266
      Serial.println(F("Sending measurement data to the aqi.eco service!\n"));
#elif defined ARDUINO_ARCH_ESP32
      Serial.println(("Sending measurement data to the aqi.eco service!\n"));
#endif
    }
  }

}
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

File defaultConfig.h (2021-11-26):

#pragma once

bool DEVICENAME_AUTO = true;
char DEVICENAME[32] = "Smogly1"; // Bez polskich znakow!! // Without Polish letters!!
bool DISPLAY_PM1 = false;
char LANGUAGE[12] = "english"; // english or polish
unsigned char SELECTED_LANGUAGE = 1; // en - 1; pl - 2

char THP_MODEL[12] = "Non";
char DUST_MODEL[12] = "Non";
bool FREQUENTMEASUREMENT = false;

bool SECOND_THP = false;
char SECOND_THP_MODEL[12] = "Non";

#ifdef ARDUINO_ARCH_ESP8266
char CONFIG_FIRST_THP_SDA[4] = "D3";
char CONFIG_FIRST_THP_SCL[4] = "D4";
unsigned char FIRST_THP_SDA = 0; // D3
unsigned char FIRST_THP_SCL = 2; // D4
#elif defined ARDUINO_ARCH_ESP32
char CONFIG_FIRST_THP_SDA[4] = "D4";
char CONFIG_FIRST_THP_SCL[4] = "D5";
unsigned char FIRST_THP_SDA = 4; // D16
unsigned char FIRST_THP_SCL = 5; // D17
#endif

#ifdef ARDUINO_ARCH_ESP8266
char CONFIG_SECOND_THP_SDA[4] = "D5";
char CONFIG_SECOND_THP_SCL[4] = "D6";
unsigned char SECOND_THP_SDA = 14; // D5
unsigned char SECOND_THP_SCL = 12; // D6
#elif defined ARDUINO_ARCH_ESP32
char CONFIG_SECOND_THP_SDA[4] = "D22";
char CONFIG_SECOND_THP_SCL[4] = "D23";
unsigned char SECOND_THP_SDA = 22; // D5
unsigned char SECOND_THP_SCL = 23; // D6
#endif

#ifdef ARDUINO_ARCH_ESP8266
char CONFIG_DUST_TX[4] = "D1";
char CONFIG_DUST_RX[4] = "D2";
unsigned char DUST_TX = 5; // D1
unsigned char DUST_RX = 4; // D2
#elif defined ARDUINO_ARCH_ESP32
char CONFIG_DUST_TX[4] = "D18";
char CONFIG_DUST_RX[4] = "D19";
unsigned char DUST_TX = 18; // D1
unsigned char DUST_RX = 19; // D2
#endif

/*
   ESP8266
   13 - D7
   15 - D8
*/

unsigned char DUST_TIME = 1;
unsigned char NUMBEROFMEASUREMENTS = 10;

bool LUFTDATEN_ON = false;
bool LUFTDATEN_GRAPH_ON = false;
int LUFTDATEN_APIID = 0;
bool SMOGLIST_ON = true;

bool AIRMONITOR_ON = false;
bool AIRMONITOR_GRAPH_ON = false;
char AIRMONITOR_API_KEY[48] = "";
char LATITUDE[16] = "50.263911";
char LONGITUDE[16] = "18.995711";
char EMAIL[64] = "email@mail.pl";
short MYALTITUDE = 271;

bool THINGSPEAK_ON = false;
bool THINGSPEAK_GRAPH_ON = false;
char THINGSPEAK_API_KEY[32] = "WRITE_API_KEY";
unsigned short THINGSPEAK_CHANNEL_ID = 0;
char THINGSPEAK_READ_API_KEY[32] = "READ_API_KEY";

bool INFLUXDB_ON = false;
char INFLUXDB_VERSION[4] = "1"; // 1 (for 1.x version) or 2 for 2.0 or later
char INFLUXDB_HOST[128] = "INFLUXDB_ADRESS";
uint16_t INFLUXDB_PORT = 8086;
char INFLUXDB_DATABASE[32] = "mydb";
char INFLUXDB_USER[32] = "username";
char INFLUXDB_PASSWORD[64] = "password";
char INFLUXDB_ORG[32] = "myOrg";
char INFLUXDB_BUCKET[32] = "myBucket";
char INFLUXDB_TOKEN[128] = "myToken";

bool MQTT_ON = false;
char MQTT_HOST[128] = "MQTT_ADRESS";
uint16_t MQTT_PORT = 1883;
char MQTT_USER[32] = "username";
char MQTT_PASSWORD[64] = "password";

bool MQTT_IP_IN_TOPIC = false;
bool MQTT_DEVICENAME_IN_TOPIC = true;
bool MQTT_SLASH_AT_THE_BEGINNING = true;
bool MQTT_SLASH_AT_THE_END = true;

char MQTT_TOPIC_TEMP[64] = "sensor/temperature";
char MQTT_TOPIC_HUMI[64] = "sensor/humidity";
char MQTT_TOPIC_PRESS[64] = "sensor/pressure";
char MQTT_TOPIC_PM1[64] = "sensor/PM1";
char MQTT_TOPIC_PM25[64] = "sensor/PM2.5";
char MQTT_TOPIC_PM10[64] = "sensor/PM10";
char MQTT_TOPIC_AIRQUALITY[32] = "airquality";

bool AQI_ECO_ON = false;
char AQI_ECO_HOST[64] = "???.aqi.eco";
char AQI_ECO_PATH[64] = "/u/???";

unsigned char SENDING_FREQUENCY = 3;
unsigned char SENDING_DB_FREQUENCY = 3;
bool DEEPSLEEP_ON = false;

bool DEBUG = false;
#ifdef ARDUINO_ARCH_ESP8266
bool AUTOUPDATE_ON = true;
#elif defined ARDUINO_ARCH_ESP32
bool AUTOUPDATE_ON = true;
#endif

bool CONFIG_AUTH = false;
char CONFIG_USERNAME[64] = "admin";
char CONFIG_PASSWORD[128] = "password";

char MODEL[12] = "white";
float calib1 = 1.0;
float calib2 = 1.0;

bool HOMEKIT_SUPPORT = false;

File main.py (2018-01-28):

from sensor_manager import SensorManager
from webapp import webapp
from ntptime import settime, loop_set_time

import uasyncio
import picoweb
import network


def do_webapp():
    webapp.debug = False
    webapp.init()
    for mount in webapp.mounts:
        mount.init()
    return asyncio.start_server(webapp._handle, '0.0.0.0', 80)


if __name__ == "__main__":
    ap_if = network.WLAN(network.AP_IF)
    if not ap_if.active():
        settime()

    sensor_manager = SensorManager(fake_data=True, send_to_airmonitor=False)
    #sensor_manager.setup()

    while True:
        loop = uasyncio.get_event_loop()

        loop.create_task(sensor_manager.execute(loop))
        if not ap_if.active():
            loop.create_task(loop_set_time())
        loop.create_task(do_webapp())
        
        loop.run_forever()
        loop.close()

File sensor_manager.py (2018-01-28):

from bme280 import BME280
from pms7003 import PMS7003
from machine import Pin, I2C, RTC

from uasyncio import sleep

import ujson
import urequests
import utime
import uasyncio


URL_API = 'http://api.airmonitor.pl:5000/api'
SENSOR_MODEL = 'PMS7003'


class SensorManager:
    fake_data = False
    send_to_airmonitor = False

    bme280 = None  # type: BME280
    pms7003 = None  # type: PMS7003
    
    def __init__(self, fake_data=False, send_to_airmonitor=True):
        self.fake_data = fake_data
        self.send_to_airmonitor = send_to_airmonitor

    def setup(self):
        """
            Setup sensors BME280 nad PMS7003
            WARNING: pms7003 need UART,
            Communication python shell <-> UART will be turned off!
        """
        i2c = I2C(scl=Pin(5), sda=Pin(4)) 
        self.bme280 = BME280(i2c=i2c)
        self.pms7003 = PMS7003()

    def get_data(self):
        """
            returns a dict with data
            :return: dict with keys::
                
                pm1 - PM1.0 from PMS7003 [μg/m³]
                pm25 - PM2.5 from PMS7003 [μg/m³]
                pm10 - PM10 from PMS7003 [μg/m³]
                temperature - [°C]
                pressure - [hPa]
                humidity - [%]
                date - YYYY-MM-DD hh:mm:ss
        """
        pm1, pm25, pm10 = self.pms7003.read_data()
        temp, press, hum = self.bmp280.read_compensated_data()

        return {
            'pm1': pm1,
            'pm25': pm25,
            'pm10': pm10,
            'temperature': temp / 100.0,
            'pressure': (press // 256) / 100.0,
            'humidity': hum / 1024.0,
            'date': self.get_date(),
        }

    def get_fake_data(self):
        now = utime.time()
        year, month, day, hour, minute, second, *_ = utime.localtime(now)
        return {
            'pm1': 5,
            'pm25': 5,
            'pm10': 5,
            'temperature': 20,
            'pressure': 20,
            'humidity': 100,
            'date': self.get_date(),
        }

    @staticmethod
    def _get_date():
        now = utime.time()
        year, month, day, hour, minute, second, *_ = utime.localtime(now)
        fmt = '{year}-{month}-{day} {hour}:{minute}:{second}'

        return fmt.format(
            year=year,
            month=month,
            day=day,
            hour=hour,
            minute=minute,
            second=second,
        )

    async def execute(self, loop):
        while True:
            loop.create_task(self.get_and_send_data())
            await sleep(60)

    async def get_and_send_data(self, loop):
        if self.fake_data:
            data = self.fake_get_data()
        else:
            data = self.get_data()

        loop.create_task(self.save_data_to_file(data))
        loop.create_task(self.upload_to_airmonitor(data))

    async def save_data_to_file(self, data):
        with open('data', 'a') as f:
            f.write(ujson.dumps(data) + '\n')

    async def upload_to_airmonitor(self, data):
        if not self.send_to_airmonitor:
            return
        # todo: get lat & long from config
        config_lat = 50.2639
        config_long = 18.9957

        air_data = {
            'lat': lat,
            'long': long,
            'pressure': data['pressure'],
            'temperature': data['temperature'],
            'humidity': data['humidity'],
            'pm1': data['pm1'],
            'pm25': data['pm25'],
            'pm10': data['pm10'],
            'sensor': SENSOR_MODEL,
        }

        urequests.post(
            URL_API,
            timeout=10,
            data=data,
            headers={"Content-Type": "application/json"},
        )

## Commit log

2018-01-27 add main and sensor manager
2018-01-27 code snippet for setting time from NTP and change in http_server for showing current time (/time)
2018-02-07 add 3d model
    [80x80x40mm.stl]
2018-02-08 add arduinojson, more comments and minor visual update
2018-02-10 fix variable error in airmonitor.cpp
    [Smogomierz.ino, airmonitor.cpp]
2018-02-10 bugfixes & split thing speak code
    [Smogomierz.ino, airmonitor.cpp]
2018-02-14 Fix connection description
    Fix wrong pin for RX of PMS
    [Smogomierz.ino]
2018-02-24 Better calibration!
    Better calibration in low temp and high humidity and init influxdb
    support.
2018-03-12 update
    fix pressure measurements
    [Smogomierz.ino, airmonitor.cpp, bme280.h]
2018-03-12 update
    fixed wrong pressure measure
    [Smogomierz.ino, airmonitor.cpp, bme280.h]
2018-04-15 minor visual update
    add „Hackerspace Silesia” in footer!
2018-04-23 fixed pressure measurements
2018-06-13 English translation and better PM calibration
2018-08-24 Add SHT21, HTU21D, BMP280 support
    At /config, you can choose the model of temp/humi/press sensor and model of dust sensor.
    // BME280 support probably stopped working :(
2018-08-26 fixed the BME280 / BMP280 support
    [Smogomierz.ino, bme280.h]
2018-08-30 fixed auto calibration on HTU21 and BME280 sensor
    [Smogomierz.ino]
2018-10-03 fixed SDS011 Serial pins
    [Smogomierz.ino]
2018-10-03 fixed SDS011 Serial pin
    [Smogomierz.ino]
2018-11-07 New design, AutoUpdate(only HTTP) and ArduinoJSON6.5 support
    AutoUpdate works only with HTTP links. Default disable and commenting by the code. SDS011 support disable by commenting by the code.
2018-11-19 Update to 2.4.5
    Add DHT22, SDS011/21 and HPMA11550 support. Lots of fix and improvements.
    [Smogomierz.ino, airmonitor.cpp, defaultConfig.h]
2018-11-26 added an example of the wrong placement of PM sensor
2018-12-16 Fixed sending data to AirMonitor
    [airmonitor.cpp]
2018-12-16 added information about the cable for PMS7003
2018-12-19 Added "Erase WiFi Config" button
2018-12-24 added option for less frequent PM measurements
    PMS will go to sleep(pms.sleep) between a series of measurements. This will significantly extend the life of the PM sensor.
2018-12-24 Added "restoring default settings" button
    On the /config page of course.
2019-01-03 fixed AIRMONITOR_interval and THINGSPEAK_interval
    [Smogomierz.ino]
2019-03-20 add deepsleep support
    DeepSleep allows you to switch off the device between a series of measurements.
2019-03-24 fixed displaying charts from Thingspeak
    [html-content.h]
2019-03-27 added "smogomierz" prefix for X-Sensor
2019-03-28 fixed deepsleep sendDataToExternalServices bug
    [Smogomierz.ino]
2019-03-29 mqtt and sending measured values before reading the first data has been fixed
    [Smogomierz.ino, html-content.h]
2019-04-06 Texts about measurements of temp/humi/press have been hidden, when we do not have a chosen temp/humi/press sensor
2019-04-06 Hidden texts about Temp/Humi/Press measurements when they chose the wrong Temp/Humi/Press sensor
2019-04-08 Fix BME280 oversampling and standby delay
    [bme280.h]
2019-04-10 The choice of the SDS011 or HPMA115S0 sensor has been added
    If you choose a different PM sensor than supported. The system will download and install the correct .bin file
2019-04-10 added _handle_config after changing PM sensor
2019-04-11 fixed PM sensor name on Config page
2019-04-15 fixed issue with sending 0 instead PM measurements when DeepSleep is enabled
    [Smogomierz.ino]
2019-04-16 Fixed issue with refreshing data via MQTT under DeepSleep
    added mqttclient.disconnect() after data was send
    [Smogomierz.ino]
2019-04-18 Luftdaten service has been improved
    PIN info added.
    Support for all PM sensors.
    Preparation for support of all sensors Temp/Humi/Press.
2019-04-24 added support for Temperature/Humidity/Pressure sensors other than BME280 to AirMonitor, Luftdaten, ThingSpeak and Smoglist
2019-04-25 autoupdate can check the availability of any version of the software and install it
    Previously, autoupdate checked only the availability of the currently installed version.
2019-08-23 fixed and enable smoglist and autoupdate
    [Smogomierz.ino, smoglist.cpp]
2019-08-23 fixed PasswdInput and FloatInput bug
    [Smogomierz.ino, html-content.h, smoglist.cpp]
2019-08-23 added ESP32 support!
2019-08-23 new prerelease .bin for ESP8266 and ESP32 - 2.7.1
2019-08-24 add info about uploading a blank SPIFFS image for ESP32
2019-08-26 created separate folders for esp8266 ann esp32 libs
2019-08-26 fixed auto firmware upgrade on ESP8266
    [autoupdate.cpp]
2019-08-27 fixed influxDB on ESP32
2019-08-30 fixed webOTA update on ESP32
    [Smogomierz.ino]
2019-08-30 fixed deepsleep on ESP32
    [Smogomierz.ino]
2019-08-30 more comments about ESP32 code
2019-09-03 update ArduinoIDE to 1.8.9
2019-09-26 fixed broadcasting unwanted open wifi network
    https://github.com/hackerspace-silesia/Smogomierz/issues/47#issue-496810438
    [Smogomierz.ino]
2019-10-01 changed LATITUDE / LONGITUDE format from float to char
    https://github.com/hackerspace-silesia/Smogomierz/issues/49#issue-500691554
    [Smogomierz.ino, airmonitor.cpp, defaultConfig.h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]
2019-10-01 changed the MYALTITUDE format from char to int
    https://github.com/hackerspace-silesia/Smogomierz/issues/49#issuecomment-536982251
    [Smogomierz.ino, defaultConfig.h]
2019-10-02 added protection to LATITUDE/LONGITUDE input
    https://github.com/hackerspace-silesia/Smogomierz/issues/49
    [Smogomierz.ino]
2019-10-04 Update to 2.7.2
    + changed LATITUDE / LONGITUDE format from float to char - https://github.com/hackerspace-silesia/Smogomierz/issues/49
    + fixed broadcasting unwanted open wifi network - https://github.com/hackerspace-silesia/Smogomierz/issues/47
    [Smogomierz.ino, airmonitor.cpp, autoupdate.cpp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]
2019-11-07 Changed name to Smogly and added better SPIFFS support for ESP32
2019-11-07 added prerelease bin file for ESP32
2019-11-09 ESP8266 core for Arduino - 2.6.0 support
2019-11-13 New UI for ESP32
2019-11-14 fixed some UI issues
    [html-content.h]
2019-11-18 ESP8266 core for Arduino - 2.6.1 support
2019-11-18 ESP8266 core for Arduino - 2.6.1 - fixed!
    [Smogomierz.ino]
2019-12-20 problem with saving settings from the /config page has been fixed
    [Smogomierz.ino]
2020-01-16 Specify the device measuring the weather data in JSON.
2020-01-16 One Code to rule them all! - Just define the PM Sensor at the beginning of the code.
    Added Sensirion SPS30 support!
2020-01-18 the configuration JSON(config.json) was divided into two parts(device_config and services_config)
2020-01-22 some fixes in asyncwebserver
    [Smogomierz.ino, html-content.h]
2020-01-22 fixed save/load config issue
    [Smogomierz.ino, html-content.h]
2020-01-23 fixed airmonitor graph issue on esp8266
    [html-content.h]
2020-01-23 switched back to default DEBUG = false
2020-01-23 saved altitude! Finally! And fixed SPS30 issiue with ESP8266HTTPUpdateServer.h
    [Smogomierz.ino]
2020-01-23 even more fixes to SPS30 - ESP8266HTTPUpdateServer.h issue!
    [Smogomierz.ino]
2020-01-24 fixed OTA update at ESP32 with asyncwebserver
    [Smogomierz.ino, html-content.h]
2020-01-25 fixed mDNS issue and prepare MQTT update
    [Smogomierz.ino]
2020-02-02 fixed some issues with adv MQTT
    [Smogomierz.ino]
2020-02-04 fixed support for InfluxDB with auth (version <2.0)
    [InfluxDbV2.cpp, Smogomierz.ino]
2020-02-04 fixed esp32 support
2020-04-23 init support for THP/DUST Sensor pins config
2020-04-23 Added protection against selecting the same pins for THP and DUST sensor
2020-04-30 fixed DHT22 and DS18B20 support!
    [Smogomierz.ino]
2020-05-01 fixed BME280 and SPS30 support
    [Smogomierz.ino]
2020-05-03 fixed SPS30 support on ESP32
    [Smogomierz.ino]
2020-11-27 fix: metrics port is no longer 3000
    [html-content.h]
2021-01-04 minor fix for ESP32 2.8.0
    [Smogomierz.ino]
2021-01-27 fixed fixed compilation issue on ESP32 issue on ESP32
2021-01-27 init Apple HomeKit Support for ESP32!
2021-01-29 ESP32: use HTTP if HTTPS connection fails [for autoupdate options]
    [autoupdate.cpp]
2021-02-23 2.8.1 - full async webserver support - for ESP32 and ESP8266
2021-02-24 fixed issue with UART devices and AsyncWebServer
    [Smogomierz.ino]
2021-03-09 added WiFi.hostname/setHostname(device_name)
2021-04-19 fixed airmonitor api key support?
    [airmonitor.cpp]
2021-09-13 added esp32 .bin file
2021-11-26 fixed issue with config services site and added DISABLE_SMOGLIST
    [Smogomierz.ino, smogly_asyncwebserver.h]
2021-11-27 Luftdaten -> Sensor.Community
